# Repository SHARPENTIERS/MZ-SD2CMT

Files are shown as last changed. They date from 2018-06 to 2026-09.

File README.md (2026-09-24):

# MZ-SD2CMT2 - Reborn

**Extended SD-card CMT emulator / recorder for the Sharp MZ-800**  
**Firmware 1.0**

<p align="center">
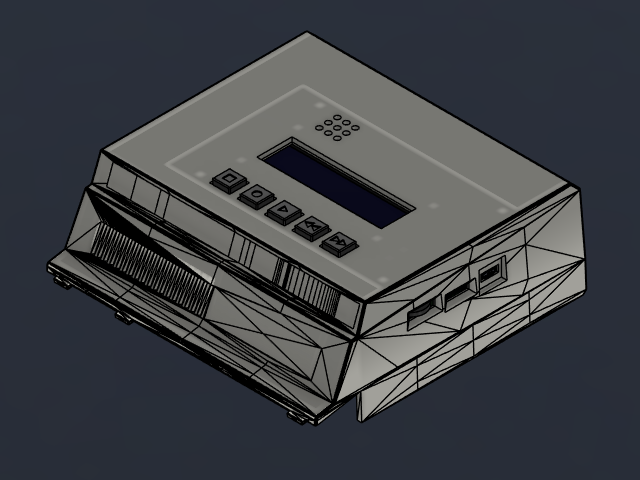
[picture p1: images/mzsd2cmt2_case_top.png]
MZ-SD2CMT2 enclosure
  
</p>

> **MZ-SD2CMT2 is based directly on the original [MZ-SD2CMT](https://github.com/SHARPENTIERS/MZ-SD2CMT) project by Christophe Avoinne (hlide).**  
> The purpose of MZ-SD2CMT2 is to **continue and extend the original project**: improve the firmware and user interface, add playback and recording capabilities, and provide an optional integrated hardware implementation, while preserving compatibility with the original modular hardware concept.

The primary target is the **Sharp MZ-800**. The project acts as a solid-state CMT replacement using an SD card, but its design goal is not only functional replacement: the dedicated hardware version is also intended to look and feel at home next to original Sharp MZ equipment.

## Project goals

MZ-SD2CMT2 has three main goals: **preserve compatibility with the original MZ-SD2CMT modular hardware**, extend the firmware with additional playback/recording features, and provide an optional dedicated PCB and enclosure for a cleaner stand-alone build.

The dedicated version remains based on the same core CMT interface, but adds convenience hardware and a mechanical design inspired by original Sharp MZ cassette equipment.

## Main features

- SD-card file browser with alphabetical sorting, folders and long-name scrolling
- playback of **MZF, MZT, M12, WAV, LEP, L16 and TAP**
- recording to **MZF, WAV, LEP and L16**
- WAV recording at **44.1 kHz or 22.05 kHz, 8-bit mono**
- recording control by **MOTOR**, automatic activity detection, or manual control
- optional **AutoName**: automatic naming of recordings from detected Sharp MZ tape metadata
- live recognition/display of several normal and turbo tape profiles while recording
- multiple Sharp MZ tape timing and loader profiles, including NORMAL, MZ-700, InterCopy and Turbo Copy families
- **Ultra Fast** loading for compatible MZF files
- selectable ZX Spectrum **TAP playback speed**
- **MFI metadata for MZF** and **MTI per-record metadata for MZT**
- **MZT mini-browser / record selector** showing logical record number, title, loader/profile and per-record duration
- independent loader/profile selection for every logical record inside an MZT
- browser `I` indicator when matching MFI/MTI playback information is available
- MFI/MTI files hidden from normal browser entry counts and sorting
- preparation and conversion of **MZF, MZT, LEP, L16 and WAV** files, including matching **MFI/MTI** metadata is possible with [Extended QDTool](https://github.com/bales0/QDTool)
- automatic sound-monitor activity during physical tape waveform playback/recording
- persistent hardware, playback and recording settings stored in EEPROM
- SD-card insertion/removal handling on supported dedicated hardware
- selectable internal MZ-SD2CMT2 / external physical CMT path on supported dedicated hardware

This README is intentionally a **project overview rather than a complete operating manual**.

For normal use see:

- [User Handbook](guide/USER_HANDBOOK.md)
- [Quick Reference Guide](guide/QUICK_REFERENCE_GUIDE.md)

For metadata syntax see:

- [MFI / MTI playback metadata](guide/MFI_MTI_FORMAT.md)

## Playback overview

### Normal files

Browse to a file and press **PLAY**.

Supported playback formats are:

| Format | Purpose |
|---|---|
| **MZF** | canonical single Sharp MZ program image |
| **MZT** | container with multiple logical MZF records |
| **M12** | supported Sharp tape-format variant |
| **WAV** | sampled tape waveform |
| **LEP** | pulse-duration representation using a 50 µs unit |
| **L16** | pulse-duration representation using a 16 µs unit |
| **TAP** | ZX Spectrum TAP playback |

The normal recommended starting point for Sharp MZ software is:

```text
PLAY CTRL = MOTOR
LOADER    = NORMAL
SPEED     = 1:1
```

When a library contains matching MFI/MTI files, use:

```text
PLAY CTRL = MOTOR
LOADER    = AUTO
```

### MZT mini-browser / record selector

An MZT is not started immediately as one long stream. Opening an MZT first enters a lightweight **record selector**.

Example:

```text
+----------------+
|2I5 PACMAN     █|
|MTI N13 01:27   |
+----------------+
```

The selector shows:

- selected logical record and total record count
- title from the selected MZF header
- the resolved loader/profile for that record
- the nominal duration of that record when known

Controls:

```text
REWIND = previous record
FFWD   = next record
PLAY   = confirm/start selected record
STOP   = return to main browser
```

The selector wraps from the first record to the last and vice versa.

During playback, **STOP** returns first to the MZT selector. A second **STOP** returns to the main SD browser.

Each logical MZT record is treated independently. Its title, loader/profile and duration are recalculated for that record rather than applying one global setting to the whole MZT.

Ultra Fast records are also treated as independent LOAD operations. After an Ultra Fast record completes, the next MZT record is not injected automatically: MOTOR mode waits for a new MOTOR cycle and MANUAL mode waits for a new PLAY confirmation.

## MFI and MTI playback metadata

External playback metadata use two explicit sidecar formats:

```text
GAME.MZF  -> GAME.MFI
TAPE.MZT  -> TAPE.MTI
```

There is **no external `.MZI` fallback**. The internal source module still uses the historical `mzi_sidecar.*` name, but files on the SD card are MFI/MTI.

### MFI - one MZF

Example:

```ini
TYPE=NORMAL
SPEED=1:3
```

MFI is used when:

```text
LOADER = AUTO
```

If a loader is selected manually, the manual selection has priority.

### MTI - per-record information for MZT

Each logical record can have its own playback profile:

```ini
RECORD=1
TYPE=NORMAL
SPEED=1:1

RECORD=2
TYPE=IC
SPEED=1:3

RECORD=3
TYPE=TC
SPEED=1:3

RECORD=4
TYPE=UL_MZ800
```

This is particularly useful for multi-part games where the bootstrap, main program and later level/data records do not use the same loader.

Current supported metadata families include:

| TYPE | SPEED |
|---|---|
| `NORMAL` | `1:1`, `1:2`, `1:3`, `1:4` |
| `MZ700` | `1:1`, `1:3` |
| `IC` | `1:1`, `1:2`, `1:3`, `1:4` |
| `TC` | `1:1`, `1:2`, `1:3` |
| `UL` | no SPEED |
| `UL_MZ800` | no SPEED |
| `UL_MZ700` | no SPEED |

`TC 1:4` is intentionally not defined in the current firmware.

If an MTI file or a particular `RECORD=n` section is missing/invalid, that record falls back independently to `NORMAL 1:1`. Other MZT records are resolved again from their own metadata.

### Browser information indicator

MFI and MTI files themselves are hidden from the normal browser and do not count as visible entries.

A normal browser counter:

```text
3/28
```

changes to:

```text
3I28
```

when matching playback information exists for the highlighted MZF/MZT.

For MZT, the same `I` convention is also used in the logical record counter when MTI information is available.

## Preparing files with Extended QDTool

The companion [**Extended QDTool**](https://github.com/bales0/QDTool) can be used on a PC to prepare files for MZ-SD2CMT2.

In its Advanced mode it can:

- create and edit **MZF** and multi-record **MZT** images
- export tape waveforms as **LEP**, **L16** or **44.1 kHz WAV**
- assign a **Loader** and **Speed** profile to individual records before waveform export
- generate matching **MFI** sidecars when saving MZF files
- generate matching **MTI** sidecars with per-record profiles when saving MZT files
- combine several records into one waveform output or export them separately
- import supported WAV/LEP/L16 tape captures and map recognized NORMAL, MZ700, IC and TC timing profiles back to record metadata

This makes Extended QDTool the recommended desktop utility for preparing an SD-card library when files need to be converted, grouped into MZT containers, assigned a specific playback profile, or supplied together with MFI/MTI information for `LOADER=AUTO`.

Typical workflow:

```text
MZF files
   |
   +--> assign Loader / Speed in Extended QDTool
   |
   +--> save as MZF + MFI
   |
   +--> combine as MZT + MTI
   |
   +--> or export as LEP / L16 / WAV
```

The waveform exporters use the selected record profiles. Static waveform export supports the NORMAL, MZ700, IC and TC families implemented by QDTool; Ultra Fast profiles require the live CMT handshake and therefore are not exported as a static LEP/L16/WAV waveform.

## Recording overview

Recording formats:

| Format | Record |
|---|---:|
| **MZF** | yes |
| **WAV 44.1 kHz** | yes |
| **WAV 22.05 kHz** | yes |
| **L16** | yes |
| **LEP** | yes |

Recording modes:

- **MOTOR** - follows the Sharp MOTOR signal
- **AUTO** - starts on detected signal activity and finishes after inactivity
- **MANUAL** - controlled by the user

All normal captures are written to:

```text
/RECORDINGS
```

A short **STOP** finishes and saves an active recording. A long **STOP** cancels it and deletes an already-created capture file.

AutoName can decode a valid incoming header, display the detected title/profile during capture and rename the provisional `RECxxxx` file after a successful save.

## Loader/profile families

The user-facing loader families include:

- **NORMAL** - normal Sharp MZ timing family, 1:1 through 1:4
- **MZ700** - MZ-700 1:1 and FAST3 / 1:3
- **IC** - InterCopy-family profiles, 1:1 through 1:4
- **TC** - Turbo Copy profiles, 1:1 through 1:3
- **UL** - Ultra Fast with automatic target/placement handling
- **UL MZ800** - MZ-800-specific Ultra Fast
- **UL MZ700** - MZ-700-specific Ultra Fast
- **AUTO** - resolve MFI/MTI when present, otherwise use safe fallback behaviour

Compact LCD labels include `N11`..`N14`, `M71`, `M73`, `IC1`..`IC4`, `TC1`..`TC3`, `UL`, `UL8` and `UL7`.

## Hardware variants

### 1. Original-compatible modular build

The original MZ-SD2CMT concept is deliberately retained as a fully supported hardware option. MZ-SD2CMT2 can therefore be built from readily available modules without the dedicated PCB. This is useful for reproducing the original project, experimenting with the firmware, or building a compact version from standard parts.

The modular implementation uses the same basic building blocks as MZ-SD2CMT: an ATmega2560 board, a 16×2 LCD/keypad interface, an SPI SD-card module and the four Sharp MZ CMT signals. Two ATmega2560 board styles are practical:

- a standard **Arduino Mega 2560 R3**, which can accept the LCD Keypad Shield directly,
- a compact **Mega 2560 Pro Mini / Mini Mega**, which provides the same ATmega2560 resources in a much smaller module and is convenient for a self-contained enclosure.

#### Arduino Mega 2560 R3

<p align="center">
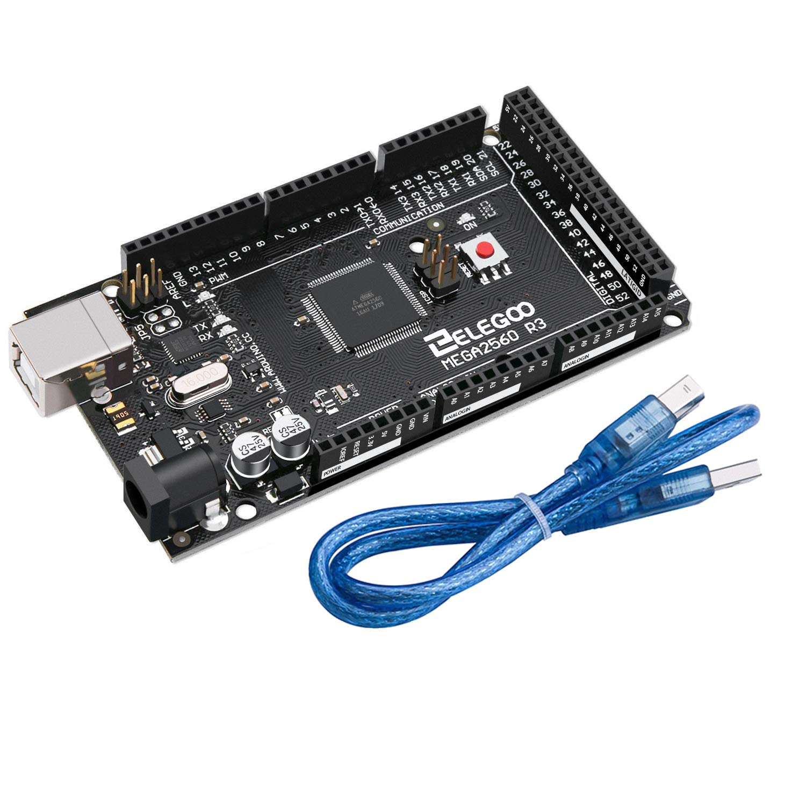
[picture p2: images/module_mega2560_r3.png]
Arduino Mega 2560 R3 used by the original-compatible modular build
  
</p>

The full-size Mega 2560 follows the most straightforward construction style: the LCD Keypad Shield can be fitted directly on the Arduino headers and the SD-card module and CMT signals are connected with wiring. This is the closest arrangement to the original MZ-SD2CMT module-based implementation.

**What to look for when buying:** a full-size **Mega 2560 R3-compatible 5 V / 16 MHz board** with the ATmega2560 and the standard Mega shield header layout. The photograph above is a real board and is intended as a visual identification aid.

#### Mini Mega / Mega 2560 Pro Mini

<p align="center">
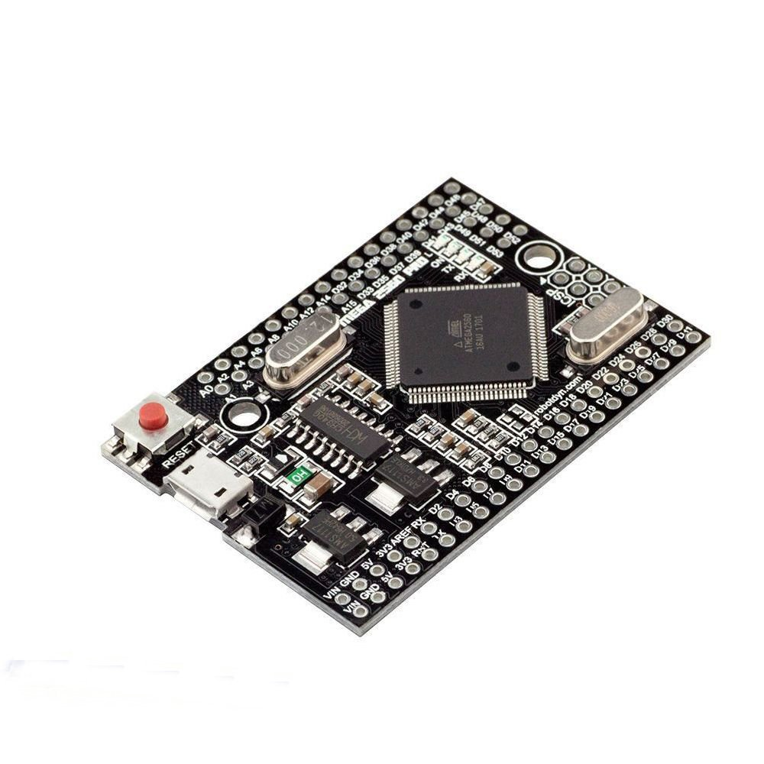
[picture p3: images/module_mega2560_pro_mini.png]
Mini Mega 2560 module
  
</p>

The compact Mini Mega version keeps the ATmega2560 platform while reducing the physical size substantially. It is especially suitable when the modular electronics are to be placed in a small stand-alone case rather than left as separate development boards.

**What to look for when buying:** this board is commonly listed as **Mega 2560 Pro Mini**, **Mini Mega 2560**, **Mega Pro Embed** or similar. Choose the **ATmega2560, 5 V, 16 MHz** version. The photograph above shows the compact board style used as the reference for this project.

For this version the repository already contains printable enclosure parts in the `STL/KeypadShield` directory:

- [`STL/KeypadShield/Cover.stl`](STL/KeypadShield/Cover.stl) - enclosure/cover
- [`STL/KeypadShield/Button.stl`](STL/KeypadShield/Button.stl) - printable button part

These STL files allow the Mini Mega + keypad-shield implementation to be built as a compact finished unit while still using the original modular electrical concept.

#### 16x2 LCD Keypad Shield

<p align="center">
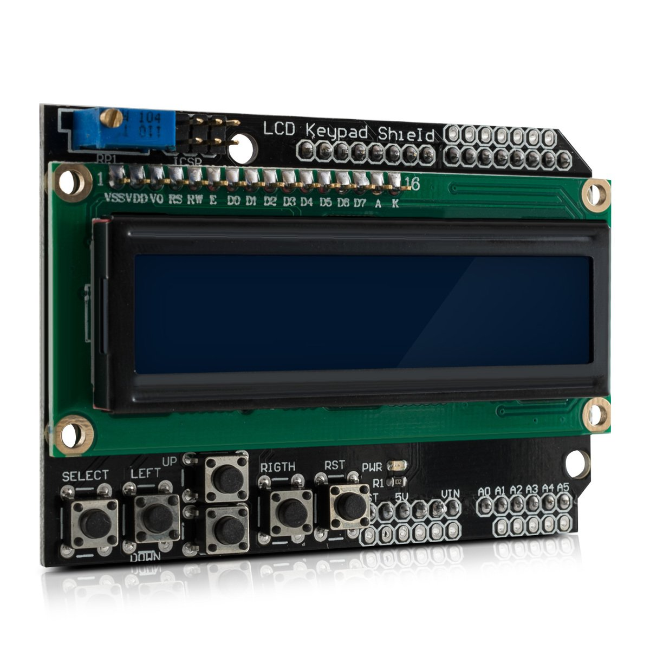
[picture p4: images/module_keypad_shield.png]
16x2 LCD Keypad Shield
  
</p>

The firmware retains support for the familiar 16x2 LCD with five analogue-keypad buttons. The keypad shield provides the display and the basic navigation/transport controls without requiring a custom front-panel PCB.

**What to look for when buying:** the common **1602 / HD44780-compatible LCD Keypad Shield** with five navigation buttons read through the analogue resistor ladder on **A0**. The real photograph above matches the classic shield style used by the original MZ-SD2CMT project.

#### SD-card module

<p align="center">
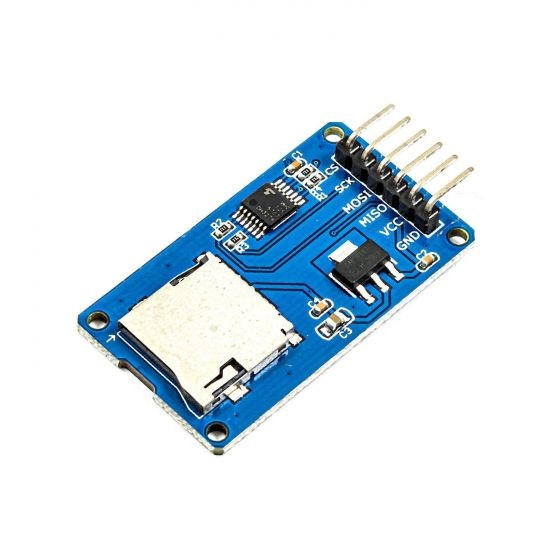
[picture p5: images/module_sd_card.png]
SPI SD-card module with 5 V level shifting
  
</p>

The modular build uses a standard SPI SD-card adapter with 5 V-compatible level shifting. On the Mega 2560 the hardware SPI interface is connected through pins **50-53** (`MISO`, `MOSI`, `SCK`, `SS/CS`).

**What to look for when buying:** use an **SD-card SPI module intended for 5 V Arduino boards**, with an onboard **3.3 V regulator and logic-level conversion**. The original-style full-size module usually exposes `GND`, `3.3V`, `5V`, `CS/SDCS`, `MOSI`, `SCK`, `MISO` and `GND`. The real photograph above is included as a visual guide; modules with the same electrical function may have a different PCB colour or layout.

Connection details for the Sharp MZ CMT interface are collected in the dedicated **CMT interface and compatibility** section below, so the wiring reference is shown only once in this README.

### 2. Dedicated MZ-SD2CMT2 hardware

The dedicated hardware combines the electronics into a purpose-built unit and adds:

- **SD-card presence detection**, allowing the firmware to detect card insertion/removal instead of relying only on failed file access
- a selectable **internal MZ-SD2CMT2 / external CMT path**, allowing a real external cassette recorder or another CMT source to remain connected and be selected without rewiring
- **audio monitoring** of the tape signal during playback and recording
- integrated connectors and wiring intended for a permanent installation
- a dedicated mechanical arrangement for the LCD, five control buttons, SD-card access and CMT connections

#### USB programming from PlatformIO

The dedicated PCB is designed so that the Mega/ATmega2560 firmware can be programmed and updated through the **USB connection directly from PlatformIO**. For normal firmware updates this avoids the need to connect a separate ISP programmer.

> **Important:** direct USB upload requires an **Arduino Mega 2560-compatible bootloader** to be present in the ATmega2560. If a blank/replacement ATmega2560 is fitted, or the Mega module does not contain the bootloader, the Arduino Mega 2560 bootloader must first be programmed via **ISP**. Once the bootloader is installed, subsequent firmware uploads can be performed normally through USB using PlatformIO/AVRDUDE.

#### Mechanical design

A major goal of the dedicated version is for the finished device to **visually resemble an original Sharp MZ CMT/cassette unit as closely as is practical**, rather than looking like a generic Arduino box.

The enclosure is therefore designed around the visual language of period Sharp hardware: a low, slightly wedge-shaped body, an inclined upper control panel, a recessed display area, a row of transport-style controls and horizontal grille/vent details. The intention is **not to make an exact 1:1 reproduction of a specific Sharp cassette mechanism**, but to create a modern SD-based CMT replacement that looks appropriate beside an MZ-800 and preserves the character of the original equipment.

The dedicated PCB is designed together with the enclosure, so the positions of the display, buttons, SD-card access and connectors are part of the mechanical concept rather than an afterthought.

For the dedicated PCB version, the repository contains the matching **3D-printable mechanical parts** in the [`STL/PCB`](STL/PCB) directory:

- [`STL/PCB/Cover.stl`](STL/PCB/Cover.stl) - enclosure cover
- [`STL/PCB/Distancer.stl`](STL/PCB/Distancer.stl) - mechanical spacer
- [`STL/PCB/FFD_REW.stl`](STL/PCB/FFD_REW.stl) - fast-forward / rewind control
- [`STL/PCB/Play.stl`](STL/PCB/Play.stl) - PLAY control
- [`STL/PCB/Rec.stl`](STL/PCB/Rec.stl) - REC control
- [`STL/PCB/Stop.stl`](STL/PCB/Stop.stl) - STOP control

These STL files form the mechanical counterpart to the dedicated PCB and allow the enclosure and transport-style controls shown below to be reproduced without having to design a separate case. There is a space between knobs and tact switches for double adhesive foam to dampen too much click feel.

<table>
<tr>
<td align="center"><b>PCB - component side</b></td>
<td align="center"><b>PCB - opposite side</b></td>
</tr>
<tr>
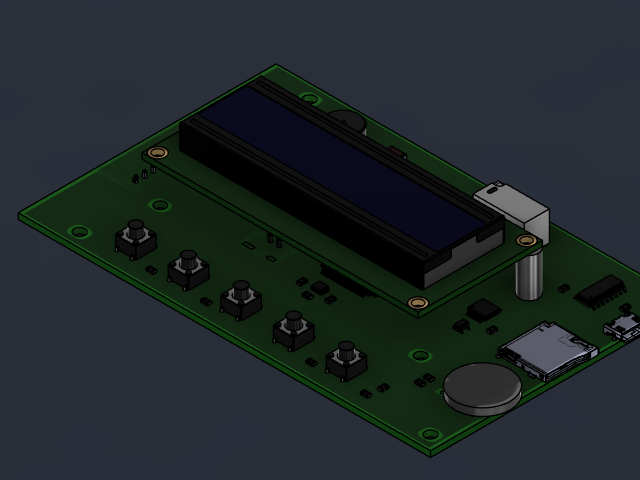
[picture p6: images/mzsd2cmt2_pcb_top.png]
MZ-SD2CMT2 PCB top
<td></td>
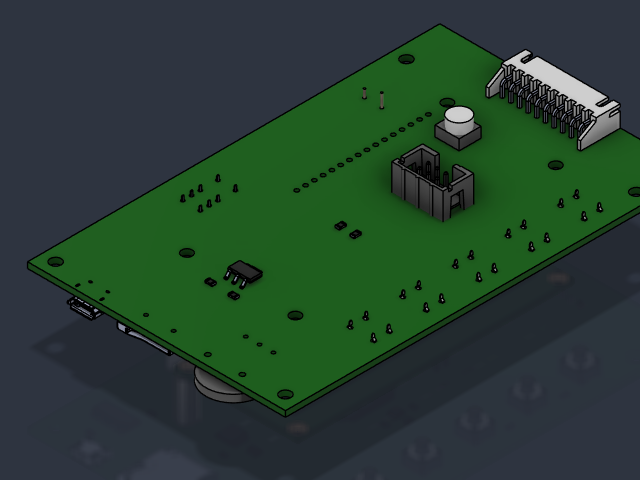
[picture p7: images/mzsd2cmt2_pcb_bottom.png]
MZ-SD2CMT2 PCB bottom
<td></td>
</tr>
</table>

<p align="center">
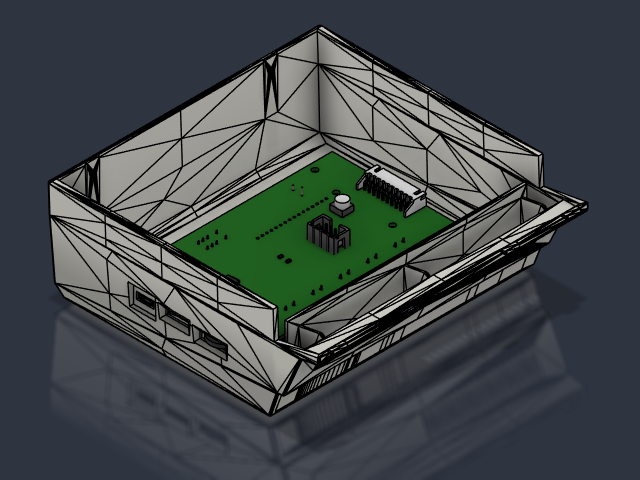
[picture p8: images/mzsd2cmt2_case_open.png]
MZ-SD2CMT2 internal arrangement
  
</p>

<p align="center"><em>Internal arrangement of the dedicated PCB below the upper control panel.</em></p>

## CMT interface and compatibility with MZ-SD2CMT

MZ-SD2CMT2 retains the CMT signal arrangement of the original MZ-SD2CMT project. This is the key hardware compatibility point that allows both the original-style modular build and the dedicated PCB to use the same firmware architecture.

<p align="center">
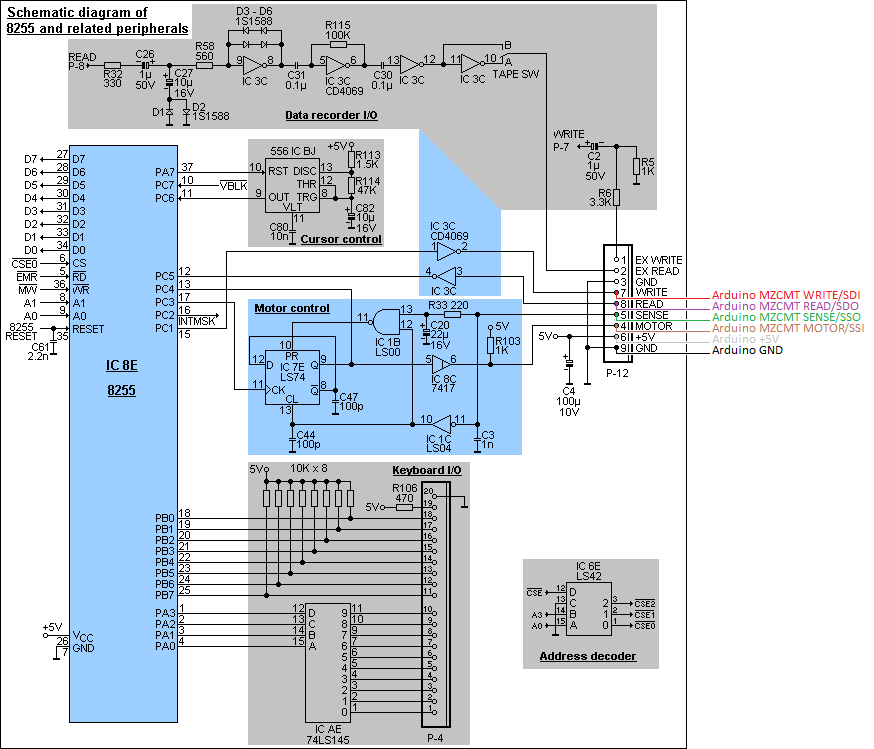
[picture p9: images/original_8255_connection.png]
MZ-SD2CMT compatible Sharp MZ 8255 CMT wiring reference
  
</p>

<p align="center"><em>Original MZ-SD2CMT 8255/CMT connection diagram and pin assignment.</em></p>

| Signal | Arduino Mega pin | Function |
|---|---:|---|
| `WRITE / SDI` | 15 | data from the Sharp MZ to the CMT interface |
| `MOTOR / SSI` | 16 | motor/control input from the Sharp MZ |
| `READ / SDO` | 2 | data from the CMT interface to the Sharp MZ |
| `SENSE / SSO` | 18 | tape sense/control output to the Sharp MZ |

These four signals are also used by the original MZ-SD2CMT Ultra-Fast transfer method. The dedicated MZ-SD2CMT2 PCB adds card detection, external-CMT switching and audio-monitor circuitry around this core interface without changing the basic connection concept.

> **Dedicated PCB schematic:** the electrical schematic of the MZ-SD2CMT2 board is kept with the project hardware files. The PCB/enclosure images in this README are mechanical/3D design renders, not the electrical schematic.

## Software structure

The current firmware targets the **ATmega2560**. Time-critical tape generation and capture use AVR timers and interrupts, while SD access, file parsing, UI and metadata processing run in the foreground.

The source tree is divided into functional areas including:

- `src/play` - playback engines, loaders and timing profiles
- `src/record` - WAV/LEP/L16/MZF recording and automatic naming
- `src/formats` - file-format detection, tape profiles and MFI/MTI sidecar handling
- `src/drivers` - LCD, keypad, SD card, CMT I/O, external-CMT switching and sound monitor
- `src/ui` - browser, MZT record selector, menus and transport screens

The internal sidecar implementation is still named `mzi_sidecar.*` for source compatibility, but the supported external metadata files are `.MFI` and `.MTI`.

## Documentation

- [User Handbook](guide/USER_HANDBOOK.md) - full operating instructions
- [Quick Reference Guide](guide/QUICK_REFERENCE_GUIDE.md) - basic controls and everyday operation
- [MFI / MTI playback metadata](guide/MFI_MTI_FORMAT.md) - sidecar syntax and selection rules
- [CMT timing reference](guide/CMT_TIMING_REFERENCE.md) - technical timing/calibration reference
- [InterCopy / Turbo Copy timing reference](guide/CMT_INTERCOPY_TURBOCOPY_TIMING_REFERENCE.md) - copier-specific timing analysis

## Origins, references and acknowledgements

MZ-SD2CMT2 builds on earlier work from the Sharp MZ and retro-computing community. The following projects, formats and authors were used either as a direct starting point or as technical references during development:

| Project / format | Author(s) | Contribution / relevance |
|---|---|---|
| **[MZ-SD2CMT](https://github.com/SHARPENTIERS/MZ-SD2CMT)** | **Christophe Avoinne (hlide)** / SHARPENTIERS | **Direct predecessor and primary foundation of MZ-SD2CMT2.** Hardware concept, Sharp MZ CMT interface, file playback and Ultra-Fast transfer work. |
| **MZF2LEP** ([included in MZ-SD2CMT](https://github.com/SHARPENTIERS/MZ-SD2CMT/tree/master/Tools/mzf2lep)) | **Christophe Avoinne (hlide)** | MZF-to-LEP/WAV conversion and Sharp MZ tape waveform/timing work. MZF2LEP itself was based on MZF2WAV. |
| **MZF2WAV** | **Jeroen F. J. Laros** | Earlier MZF-to-audio conversion code on which MZF2LEP was based. |
| **[SDLEP-READER / LEP format](https://dcmoto.pages-perso.free.fr/bricolage/sdlep-reader/index.html)** | **Daniel Coulom** | LEP pulse-duration format and SD-based virtual cassette reader concept. |
| **[ZX Spectrum TAP format](https://sinclair.wiki.zxnet.co.uk/wiki/TAP_format)** | ZX Spectrum community / historical TAP documentation | TAP block structure and ZX Spectrum tape encoding/timing reference used for TAP playback support. |
| **[mz800emu](https://github.com/michalhucik/mz800emu)** | **Michal Hucik (ordoz)** | Reference material for Sharp MZ hardware, CMT behaviour and file formats. |
| **[TapeMZ](https://github.com/michalhucik/TapeMZ)** | **Michal Hucik (ordoz)** | Research and implementation covering Sharp MZ tape formats, loaders, timing profiles, WAV analysis and the TMZ archival format. |

Special thanks to the original authors, maintainers and contributors. MZ-SD2CMT2 is intended to extend this body of work while preserving clear attribution to the projects from which code, ideas, file formats or technical information originated.

## Development status

Firmware 1.0 documents the current user-facing playback, MZT selection, MFI/MTI metadata and recording workflow described above. Timing profiles and hardware options continue to be tested on real Sharp MZ hardware.

## License

See [`LICENSE`](LICENSE).

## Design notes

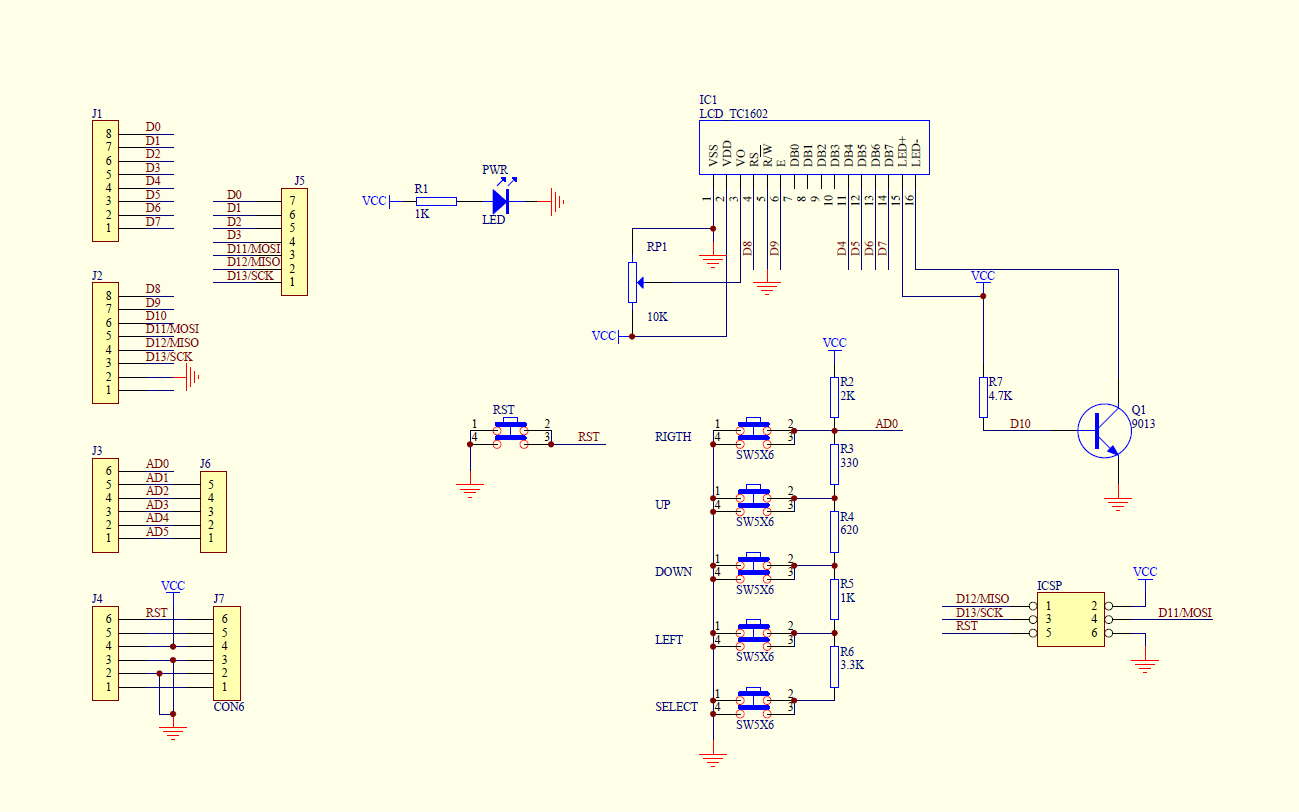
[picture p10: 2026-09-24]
images/lcdkeypadshieldschematic.png

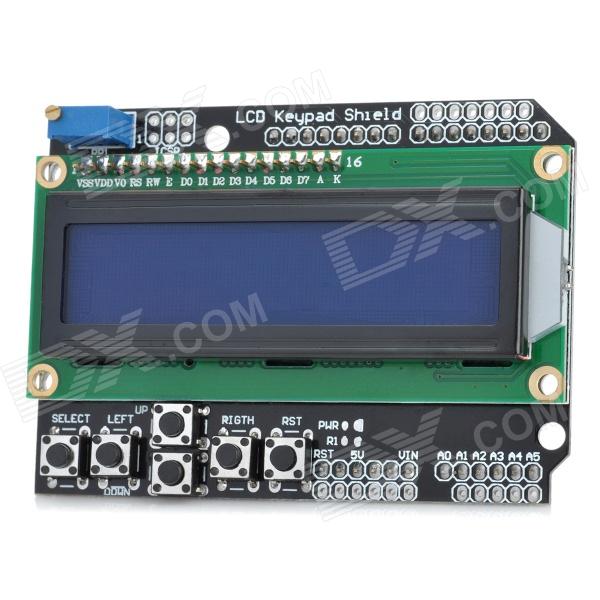
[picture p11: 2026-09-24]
images/lcdkeypadshield.jpeg

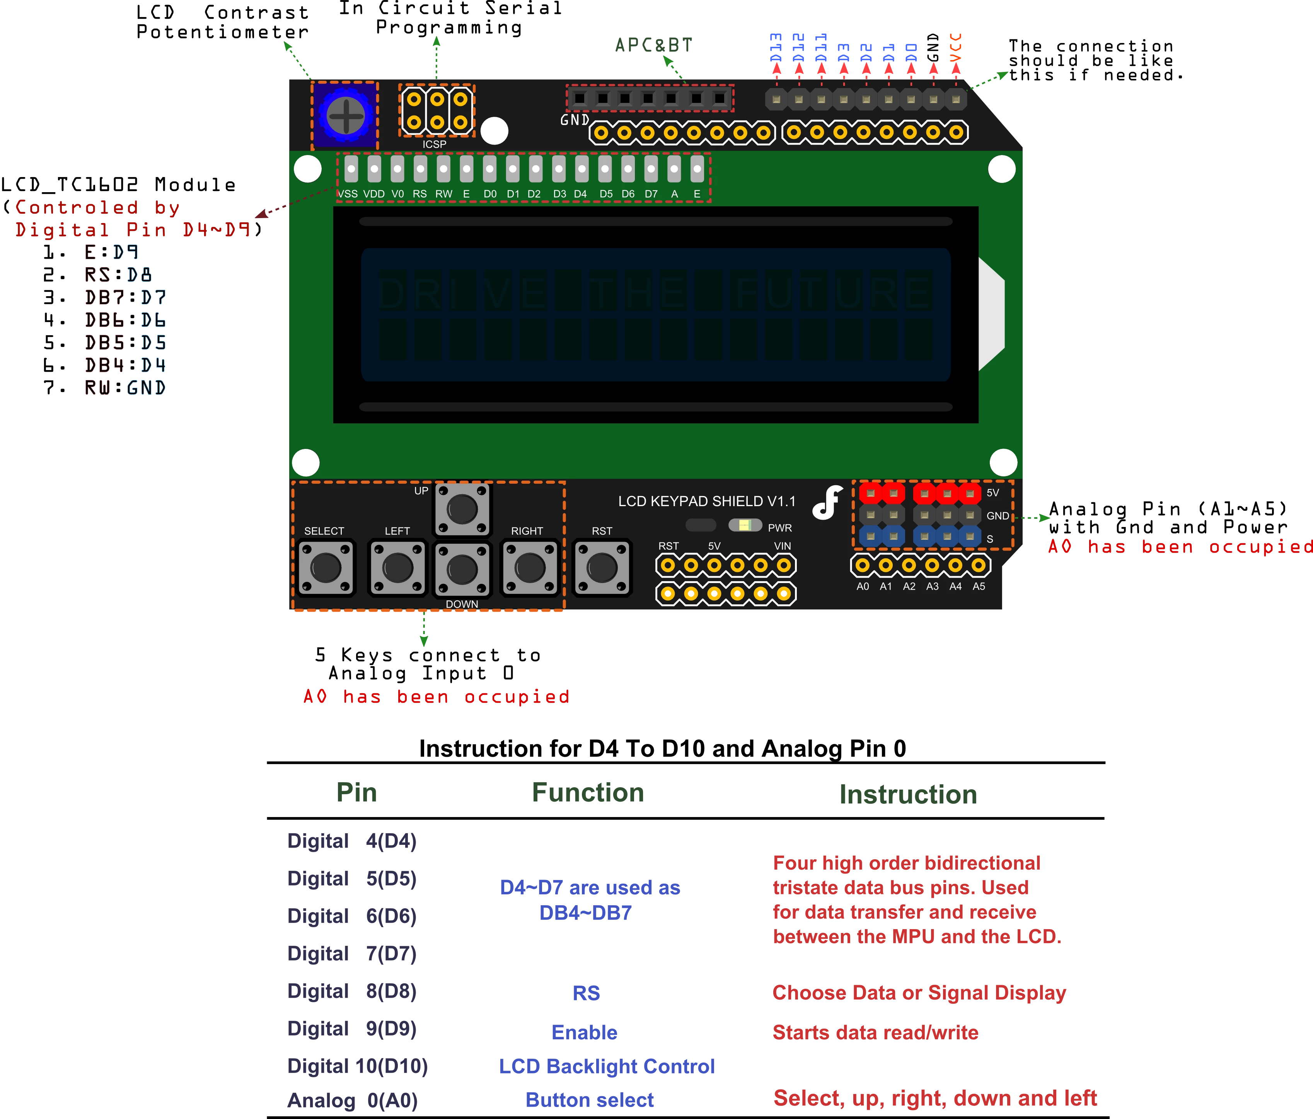
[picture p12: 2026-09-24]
images/lcdkeypadshield.webp

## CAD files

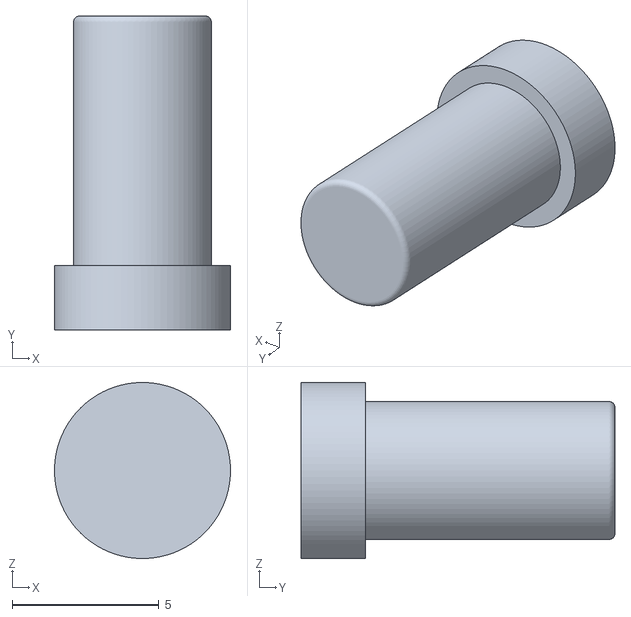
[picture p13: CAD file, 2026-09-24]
STL/KeypadShield/Button.stl
6.00 x 10.7 x 6.00

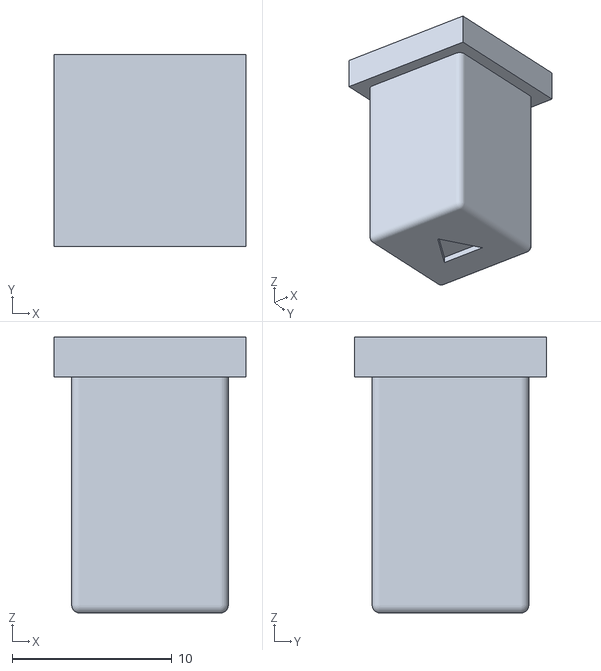
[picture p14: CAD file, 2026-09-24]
STL/PCB/Play.stl
12.0 x 12.0 x 17.3

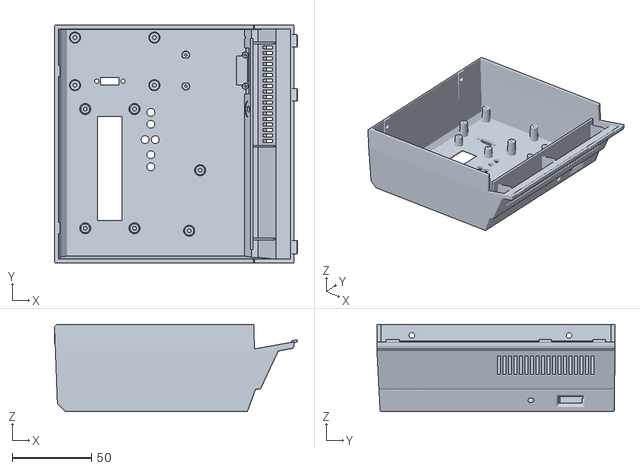
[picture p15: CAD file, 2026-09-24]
STL/KeypadShield/Cover.stl
153.1 x 150.0 x 55.0

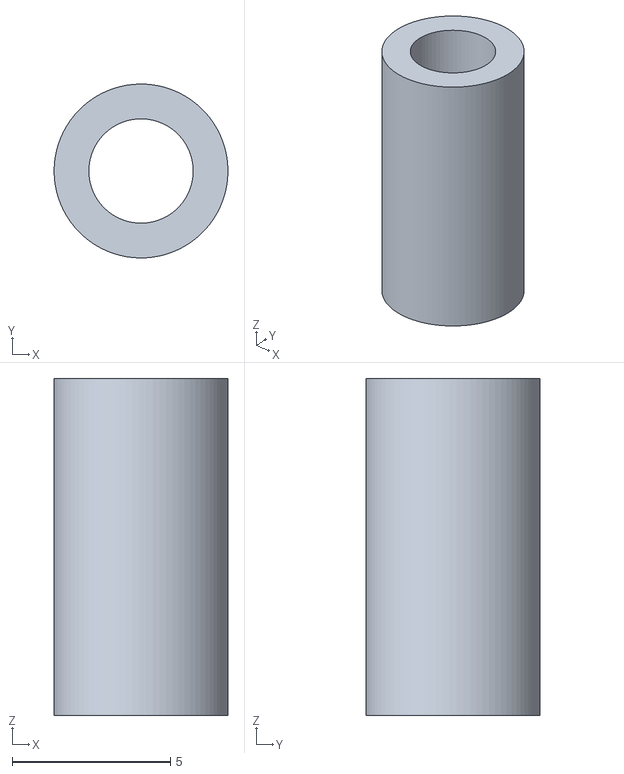
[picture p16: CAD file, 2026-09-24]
STL/PCB/Distancer.stl
5.50 x 5.50 x 10.7

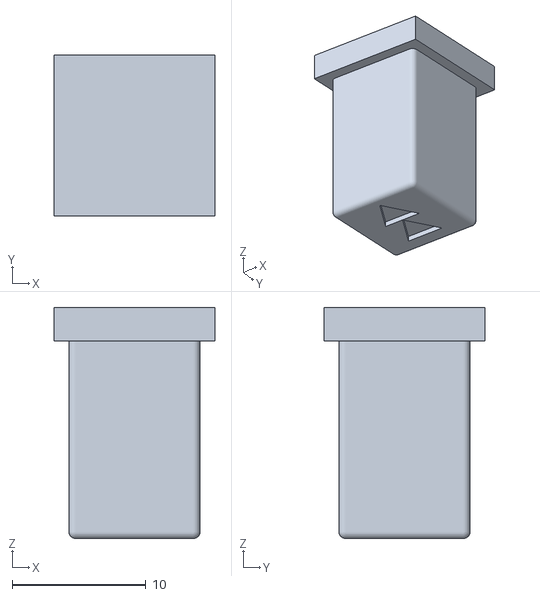
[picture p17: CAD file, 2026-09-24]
STL/PCB/FFD_REW.stl
12.0 x 12.0 x 17.3

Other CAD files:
STL/PCB/Cover.stl
STL/PCB/Stop.stl
STL/PCB/Rec.stl

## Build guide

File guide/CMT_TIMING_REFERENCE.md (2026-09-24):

# SD2CMT2 CMT Timing Reference
## ROM/loader-derived calibration reference

**Document purpose:** stable calibration source for future changes to CMT/PWM timing in `bales0/MZ-SD2CMT2`.

**Reference revision:** 2 (2026-08-29). This revision closes the native MZ-800 low-monitor analysis and separates MZ-800 IC, MZ-800 TC and MZ-700 FAST3 turbo-loader timing.

**Scope:** Sharp MZ CMT modes implemented in SD2CMT2 at baseline commit
`fabf8fc0d032a0363b991be2c1e388fc5657d2c5` (`TAP playback percentage adjustment`).

**Explicitly out of scope:** TAP/Sinclair. TAP must receive its own ROM/loader audit.

**Important:** this document intentionally distinguishes three different things that must never be conflated:

1. a waveform physically **generated** by a monitor ROM,
2. a receiver **decision/read point** implemented by a loader,
3. an empirically selected SD2CMT2 waveform that is merely required to fall safely on opposite sides of that read point.

The old 44.1 kHz WAV references remain useful as regression material, but they are **not the primary timing authority**.

---

## 1. Frozen inputs

### 1.1 Supplied ROM images

| File | Meaning | Size [B] | SHA-256 |
|---|---|---:|---|
| `1z-013a(2).rom` | MZ-700 PAL monitor 1Z-013A | 4096 | `ae1d65717414d4693158cbbd9ab707aa43e4e1ac0b2ae0e13ee3f68c66cba81b` |
| `mz700_1z-009a_jp(1).rom` | MZ-700 Japanese monitor 1Z-009A | 4096 | `b0d16889ac3e2a80cc3bc9445bc95bc9988df7b6115124f284850667cf45ff9f` |
| `9Z_504M(4).ROM` | MZ-800 high monitor 9Z-504M | 8192 | `68a91b82517d5642e250cdddb519de780fb20bcde39b2de8baee387ca6bf446a` |
| `Mz700a(1).rom` | MZ-800 low monitor 1Z-013B (binary identifies itself as `** MONITOR 1Z-013B **`) | 4096 | `fa65299ff588e3402973afbb1285dc5a7993efe9265213b64ba8e3a6facd2acf` |

### 1.2 SD2CMT2 source baseline

Repository:

`https://github.com/bales0/MZ-SD2CMT2`

Frozen commit:

`fabf8fc0d032a0363b991be2c1e388fc5657d2c5`

The repository head was re-checked on 2026-08-29; this commit is still the latest commit on `master`.

Important files at that commit:

- `src/formats/mz_tape_profiles.cpp`
- `src/formats/mz_tape_profiles.h`
- `src/formats/mz_loader_profiles.cpp`
- `src/play/mzf_loader.cpp`
- `src/play/mzf_playback.cpp`
- `src/play/mz700_fast3.cpp`
- `src/play/loader_mode.h`
- `TEST/MZ700/verify_mz700_fast3.ps1`

Relevant source blob IDs at the frozen commit:

```text
mz_tape_profiles.cpp   482414a8bba21e5787c325f02eed231eabcdf247
mzf_playback.cpp       f8429deb2fb9007a27626355242ef7b1f610dcfd
mzf_loader.cpp         1f45f2a7e3c20e91b6313e7d5c99d86f3880b7cc
mz_loader_profiles.cpp 3df3f1a41d67c582db30ff4cdaafdbcd502da029
mz700_fast3.cpp        ef24f178d995c13a6c16259536a75051b6a2fdcc
```

Embedded loader byte arrays additionally fingerprint to:

```text
IC loader, 96 B: SHA-256 a52224f33e5ad8ca6d436257f58ef5802c4a4a8a7c8e0798e31a0a968a6eeab2
TC loader, 90 B: SHA-256 4ab47c752ae0d04ce341d9be221336ed51b30a9c698d09aed4370172917ee790
```

If any of these inputs changes, this document is no longer automatically authoritative for the changed code.

---

## 2. Evidence and confidence rules

Use the following precedence when calibrating or reviewing a timing change.

| Level | Label | Meaning |
|---|---|---|
| 1 | `ROM-PATH-HIGH` | Supplied ROM bytes + deterministic Z80 path + documented hardware wait model |
| 1 | `LOADER-PATH-HIGH` | Exact loader bytes + exact patch value + deterministic RAM-executed Z80 path |
| 2 | `OFFICIAL-HW` | Sharp service/technical manual timing or source listing |
| 3 | `HW-TESTED` | Proven on a physical MZ machine, but exact timing origin may be empirical |
| 4 | `EMPIRICAL-WAV` | Derived from sampled WAV/PCM; quantized and not a source of exact CPU timing |
| special | `HANDSHAKE` | Mode is not pulse-width PWM; SHORT/LONG timing is not applicable |
| open | `TRACE-PENDING` | Static analysis exists, but cycle-accurate runtime trace is still desirable |

A WAV can confirm polarity, framing and compatibility. It must not silently overwrite a ROM/loader-derived timing equation.

---

## 3. Clock and timer model

### 3.1 Z80 clocks used here

```text
MZ-700 PAL / MZ-800 PAL: 3,546,875 Hz
MZ-700 Japanese/NTSC:    3,579,545 Hz
ATmega2560 SD2CMT2:     16,000,000 Hz
```

For ATmega2560 Timer3 with prescaler 1:

```text
1 timer tick = 62.5 ns
ticks = round(seconds * 16,000,000)
```

### 3.2 Monitor-ROM wait-state model

The published 1Z-013A source listing annotates timings such as:

```text
PUSH AF       12 T
LD A,n         9 T
LD (nn),A     16 T
CALL nn       20 T
DEC A          5 T
JP NZ,nn      13 T
RET            11 T
```

These are consistent with the standard Z80 timing plus one wait state for
each instruction byte fetched from monitor ROM. Example:

```text
LD A,n:      7 + 2 ROM-byte waits = 9 T
CALL nn:    17 + 3 ROM-byte waits = 20 T
JP NZ,nn:   10 + 3 ROM-byte waits = 13 T
```

This matters enormously. A PC emulator that executes the same instructions
with plain Z80 timings can produce a waveform roughly 20–30 % too fast even
though the instruction sequence itself is correct.

The supplied `MZ700_monitor_speed.wav` observed earlier is therefore treated
only as an emulator-output reference. Its 8/9 and 16/17 sample pulse halves
are consistent with missing/reduced real monitor-ROM wait time and 44.1 kHz
quantization; they are **not** the calibration authority used below.

For loaders that first copy the monitor to RAM and execute the patched CMT
receiver from RAM, this ROM-fetch penalty is removed. For those paths this
audit uses normal Z80 instruction timings. A future cycle-accurate runtime
trace should still verify that no machine-specific RAM wait is inserted.

---

## 4. Critical concept: a ROM pulse does not always have one fixed LOW width

`SHORT` and `LONG` explicitly create the rising and falling CMT writes, but
after the falling edge the routine returns to its caller. The time until the
next rising edge therefore includes caller instructions.

Consequently:

```text
HIGH width = largely intrinsic to SHORT/LONG routine
LOW width  = intrinsic delay + caller/framing/next-bit path
```

For example, a SHORT in the leader, a SHORT in a tape mark and a SHORT before
a LONG data bit do not have exactly the same LOW duration.

Therefore a firmware structure containing only:

```text
short_high, short_low, long_high, long_low
```

is necessarily a fixed approximation of a software-generated ROM waveform.
This is not a bug in SD2CMT2; it is a modeling decision that must be explicit.

---

## 5. MZ-700 monitor ROM analysis

### 5.1 Common delay routines

Both supplied MZ-700 ROMs contain:

```asm
0759  3E 15       LD A,$15        ; DLY1
075B  3D          DEC A
075C  C2 5B 07    JP NZ,$075B
075F  C9          RET

0760  3E 13       LD A,$13        ; DLY2
0762  3D          DEC A
0763  C2 62 07    JP NZ,$0762
0766  C9          RET
```

Using the monitor-ROM wait model:

```text
CALL DLY1 = 20 + 18*21 + 20 = 418 T
CALL DLY2 = 20 + 18*19 + 20 = 382 T
```

### 5.2 1Z-013A PAL

Supplied ROM SHA-256:

`ae1d65717414d4693158cbbd9ab707aa43e4e1ac0b2ae0e13ee3f68c66cba81b`

Relevant routines:

```text
WBYTE $0767
SHORT $0A01
LONG  $0A1B
DLY4  $09A9, operand $59 = 89
DLY3  $0A4A, operand $3F = 63
EDGE  $0601
RBYTE $0624
```

`SHORT` uses two `DLY1` calls per phase.

Exact rising-to-falling interval:

```text
16 + 2*418 + 9 = 861 T
861 T / 3,546,875 Hz = 242.749 us
```

`LONG` uses `DLY4`, whose call-inclusive time is:

```text
CALL DLY4 = 20 + 18*89 + 20 = 1642 T

LONG HIGH = 16 + 1642 + 9 = 1667 T
          = 469.991 us
```

### 5.3 1Z-009A Japanese/NTSC

Supplied ROM SHA-256:

`b0d16889ac3e2a80cc3bc9445bc95bc9988df7b6115124f284850667cf45ff9f`

Relevant routines:

```text
WBYTE $076D
SHORT $0D47
LONG  $0D60
DLY3  $0A4A, operand $45 = 69
EDGE  $0601
RBYTE $0624
```

`SHORT` is cycle-equivalent to 1Z-013A.

The Japanese `LONG` is important: it is not the same implementation as the
PAL ROM. Its first phase uses:

```text
DLY1 + DLY1 + DLY1 + DLY2
```

and its second phase uses:

```text
DLY1 + DLY1 + DLY1 + DLY1
```

Hence:

```text
LONG HIGH = 16 + 3*418 + 382 + 9
          = 1661 T
          = 464.025 us at 3.579545 MHz
```

This result is extremely close to Sharp's nominal MZ-700 service value of
464 us.

### 5.4 Exact context-dependent MZ-700 pulse table

Each cell below is `T-states / microseconds`.

| ROM | CPU [Hz] | SHORT HIGH | SHORT LOW leader | SHORT LOW mark | SHORT LOW S→L | SHORT LOW S→S | LONG HIGH | LONG LOW mark | LONG LOW L→L | LONG LOW L→S |
|---|---:|---:|---:|---:|---:|---:|---:|---:|---:|---:|
| `MZ700_1Z013A_PAL` | 3,546,875 | 861 / 242.749 | 946 / 266.714 | 934 / 263.330 | 938 / 264.458 | 951 / 268.123 | 1667 / 469.991 | 1740 / 490.573 | 1757 / 495.366 | 1770 / 499.031 |
| `MZ700_1Z009A_JP` | 3,579,545 | 861 / 240.533 | 946 / 264.279 | 934 / 260.927 | 938 / 262.044 | 951 / 265.676 | 1661 / 464.025 | 1770 / 494.476 | 1787 / 499.225 | 1800 / 502.857 |

Notes:

- `leader`: repeated SHORT in the BC leader loop.
- `mark`: repeated pulse in the D/E tape-mark loop.
- `S→L`, `S→S`, `L→L`, `L→S`: steady WBYTE data-loop transitions.
- The LOW path after the last bit/checksum can have another caller-dependent
  value; do not infer a universal LOW value from this table.

### 5.5 Why the current MZ-700 profile works

Current SD2CMT2:

```text
SHORT = 240 us HIGH + 264 us LOW
LONG  = 464 us HIGH + 494 us LOW
```

For 1Z-009A this is an excellent fixed representation of the canonical
pulse portions:

| Quantity | 1Z-009A derived | SD2CMT2 | Error |
|---|---:|---:|---:|
| SHORT HIGH | 240.533 us | 240 us | -0.533 us |
| SHORT LOW, leader | 264.279 us | 264 us | -0.279 us |
| LONG HIGH | 464.025 us | 464 us | -0.025 us |
| LONG LOW, mark | 494.476 us | 494 us | -0.476 us |

This also matches the Sharp MZ-700 service-manual nominal values
240/264/464/494 us.

**Calibration conclusion:** do not replace the current MZ-700 NORMAL
240/264/464/494 profile with the much shorter values measured from the
emulator WAV. The current profile has substantially stronger ROM/hardware
support than the WAV-derived alternative.

The 1Z-013A PAL ROM is measurably different. If a future project version
needs strict PAL-1Z-013A waveform fidelity, add a separate profile instead
of silently redefining `MZ700_NORMAL_1X`.

### 5.6 Reference Timer3 ticks for MZ-700 source values

These are *reference conversions*, not an instruction to change firmware.

| ROM/path | T | us | nearest Timer3 ticks @16 MHz |
|---|---:|---:|---:|
| 1Z-013A SHORT HIGH | 861 | 242.749 | 3884 |
| 1Z-013A SHORT LOW leader | 946 | 266.714 | 4267 |
| 1Z-013A LONG HIGH | 1667 | 469.991 | 7520 |
| 1Z-013A LONG LOW mark | 1740 | 490.573 | 7849 |
| 1Z-009A SHORT HIGH | 861 | 240.533 | 3849 |
| 1Z-009A SHORT LOW leader | 946 | 264.279 | 4228 |
| 1Z-009A LONG HIGH | 1661 | 464.025 | 7424 |
| 1Z-009A LONG LOW mark | 1770 | 494.476 | 7912 |

### 5.7 MZ-700 NORMAL receive decision timing

The same ROMs also allow a source-based check of the normal receiver.

For monitor-ROM execution, after a successful rising-edge sample inside
`EDGE`, the next data sample in `RBYTE` is modeled as:

```text
detected-edge -> data sample = 103 + 18*N T
```

where `N` is the byte at `$0A4B` used by `DLY3`.

The rising-edge polling loop in ROM is approximately 62 T, therefore a
physical edge can be detected anywhere within approximately one 62-T
polling interval:

```text
earliest sample = 103 + 18*N
latest sample   = earliest + 62
```

For the supplied ROMs:

| ROM | DLY3 N | earliest | latest | window [us] |
|---|---:|---:|---:|---:|
| 1Z-013A PAL | $3F = 63 | 1237 T | 1299 T | 348.758–366.238 |
| 1Z-009A JP | $45 = 69 | 1345 T | 1407 T | 375.746–393.067 |

The 1Z-013A late edge of this static window is very close to Sharp's
nominal MZ-700 read point of 368 us. This is an additional consistency
check for the ROM wait-state model.

These values also explain why pulse profiles that are not perfectly
waveform-faithful can still load reliably: the receiver classifies by a
decision window, not by requiring an exact pulse duration.

---

## 6. MZ-800 native monitor 1Z-013B — exact Z80 pulse audit

The newly supplied 4096-byte image `Mz700a(1).rom` identifies itself at
ROM `$06E7` as:

```text
**  MONITOR 1Z-013B  **
```

SHA-256:

`fa65299ff588e3402973afbb1285dc5a7993efe9265213b64ba8e3a6facd2acf`

The binary matches the 1Z-013B source organization in the MZ-800 Technical
Reference Manual and closes the major open item from revision 1 of this
document.

### 6.1 Why MZ-800 timing constants differ from MZ-700

The relevant 1Z-013B timing constants are:

```text
DLY1 $0759 : LD A,$1B = 27
DLY2 $0760 : LD A,$19 = 25
DLY4 $09A9 : LD A,$73 = 115
DLY3 $0A4A : LD A,$52 = 82
```

The important point is that these larger counters are not evidence of a
slower CMT. They compensate for the different monitor execution timing.

The MZ-700 1Z-013A source uses a delay-loop model of approximately 18 T per
loop count. The MZ-800 1Z-013B constants are chosen for the standard
14-T `DEC A / JP NZ` loop:

```text
MZ700 DLY1: 21 * 18 = 378
MZ800 DLY1: 27 * 14 = 378

MZ700 DLY4: 89 * 18 = 1602
MZ800 DLY4:115 * 14 = 1610

MZ700 DLY3: 63 * 18 = 1134
MZ800 DLY3: 82 * 14 = 1148
```

This is a strong code-level explanation for why simply copying delay
operands between MZ-700 and MZ-800 is wrong.

For 1Z-013B this audit uses standard Z80 instruction timing. The assembler
listing's own comments (`DLY1 ~111.39 us`, `DLY2 ~103.45 us`,
`DLY4 ~458.81 us`, `DLY3 ~331.35 us`) are consistent with this model at
3.546875 MHz.

### 6.2 Exact delay equations

For a normal RAM/no-added-wait Z80 loop:

```text
DLY(N) routine body
 = LD A,N + N*(DEC A + JP NZ) + RET
 = 7 + N*(4+10) + 10
 = 17 + 14*N T

CALL DLY(N), inclusive
 = 17 + (17 + 14*N)
 = 34 + 14*N T
```

Thus for 1Z-013B:

```text
CALL DLY1(27) = 412 T
CALL DLY4(115)= 1644 T
```

The `DLY3` routine is special because it executes `LD A,N; JP $0762`,
entering DLY2 at the loop body:

```text
CALL DLY3(N) = 44 + 14*N T
CALL DLY3(82)= 1192 T
```

### 6.3 Exact MZ-800 generated HIGH widths

`SHORT` at `$0A01` contains two DLY1 calls between its `$E003` writes.

```text
SHORT HIGH
 = 2*CALL_DLY1 + LD A,$02 + LD ($E003),A
 = 2*412 + 7 + 13
 = 844 T
 = 237.956 us
```

`LONG` at `$0A1A` contains one DLY4 call between its writes.

```text
LONG HIGH
 = CALL_DLY4 + LD A,$02 + LD ($E003),A
 = 1644 + 7 + 13
 = 1664 T
 = 469.145 us
```

These are the most context-independent pulse quantities because they are
fully inside the pulse routine.

### 6.4 Exact context-dependent LOW widths

The LOW phase includes the remainder of `SHORT`/`LONG` plus caller code
before the next rising edge. Therefore there is no single exact LOW value.

| Context | T-states | time [us] | nearest Timer3 ticks @16 MHz |
|---|---:|---:|---:|
| SHORT HIGH | 844 | 237.956 | 3807 |
| SHORT LOW, repeated leader (`GAP1`) | 918 | 258.819 | 4141 |
| SHORT LOW, repeated tape mark (`GAP3`) | 908 | 256.000 | 4096 |
| SHORT LOW, data S→L | 896 | 252.617 | 4042 |
| SHORT LOW, data S→S | 906 | 255.436 | 4087 |
| LONG HIGH | 1664 | 469.145 | 7506 |
| LONG LOW, repeated tape mark (`GAP2`) | 1728 | 487.189 | 7795 |
| LONG LOW, data L→L | 1716 | 483.806 | 7741 |
| LONG LOW, data L→S | 1726 | 486.626 | 7786 |

Examples of the low-phase equations:

```text
SHORT tail after falling edge
 = 2*CALL_DLY1 + POP AF + RET
 = 824 + 10 + 10
 = 844 T

SHORT LOW, leader
 = SHORT_tail
 + DEC BC + LD A,B + OR C + JR NZ
 + CALL SHORT + PUSH AF + LD A,$03 + LD ($E003),A
 = 844 + 6 + 4 + 4 + 12 + 17 + 11 + 7 + 13
 = 918 T

SHORT LOW, data S->L
 = 844 + RLCA + CALL C,LONG + pulse-prefix
 = 844 + 4 + 17 + 31
 = 896 T

SHORT LOW, data S->S
 = 844 + RLCA + CALL C(not taken) + CALL NC,SHORT + pulse-prefix
 = 844 + 4 + 10 + 17 + 31
 = 906 T
```

The corresponding LONG equations differ only by replacing the `SHORT` tail
with the 1664-T LONG tail.

### 6.5 Comparison with Sharp service values

Sharp's MZ-800 service documentation gives nominal values:

```text
SHORT HIGH 240 us
SHORT LOW  278 us
LONG  HIGH 470 us
LONG  LOW  494 us
READ POINT diagram: 379 us
READ POINT prose:   368 us
```

Direct Z80 execution gives:

```text
SHORT HIGH 237.956 us
SHORT LOW  approximately 252.617..258.819 us in steady/common contexts
LONG  HIGH 469.145 us
LONG  LOW  approximately 483.806..487.189 us in steady/common contexts
```

The HIGH portions agree extremely well with the manual. The software-derived
LOW portions are shorter than the manual's nominal LOW values. The manual
values must therefore be treated as hardware/nominal waveform guidance,
while the table above is the exact digital `$E003` software-edge schedule.

Do not collapse these two evidence types into one fake “exact” value.

### 6.6 Native MZ-800 receive decision window

The successful rising-edge read in `EDGE` is at `$061A`. In `RBYTE`, the
later data read is reached after:

```text
AND $20             7 T
JR Z,EDGE-loop       7 T  (not taken after successful rising edge)
RET                 10 T
JP C,RBY3           10 T  (not taken)
CALL DLY3(N)       44 + 14*N T
LD A,(DE)            7 T  (data sample)
-----------------------------------------------
detected-edge -> sample = 85 + 14*N T
```

For native MZ-800 `N=$52=82`:

```text
earliest detected-edge sample
 = 1233 T
 = 347.630 us
```

The successful rising-edge polling loop repeats every approximately 52 T,
so the physical edge can precede the detected edge by up to one poll:

```text
static physical-edge sample window
 = 1233..1285 T
 = 347.630..362.291 us
```

This is close to the service-manual 368/379-us read-point data once input
circuit propagation and documentation rounding are allowed for.

### 6.7 Current SD2CMT2 MZ-800 NORMAL versus Z80

Current project:

```text
SHORT 250/250 us
LONG  500/500 us
```

Compared with the exact Z80 schedule:

| Quantity | Z80 reference | current | delta |
|---|---:|---:|---:|
| SHORT HIGH | 237.956 us | 250 us | 12.044 us (+5.06 %) |
| SHORT LOW leader | 258.819 us | 250 us | -8.819 us (-3.41 %) |
| SHORT LOW data S→S | 255.436 us | 250 us | -5.436 us (-2.13 %) |
| LONG HIGH | 469.145 us | 500 us | 30.855 us (+6.58 %) |
| LONG LOW tape mark | 487.189 us | 500 us | 12.811 us (+2.63 %) |
| LONG LOW data L→S | 486.626 us | 500 us | 13.374 us (+2.75 %) |

**Calibration interpretation:** current 250/250/500/500 is a usable symmetric
compatibility approximation, but it is not ROM-exact.

If future work wants waveform fidelity rather than a symmetric model, the
best solution is not another single four-number guess. It is to allow
context-dependent LOW timing, or at minimum document which context was
chosen for a fixed profile.

A reasonable *reference-only* rounded fixed approximation of common 1Z-013B
software edges would be near:

```text
SHORT HIGH ~238 us
SHORT LOW  ~253..259 us
LONG  HIGH ~469 us
LONG  LOW  ~484..487 us
```

Do not change firmware to these values without real-MZ regression.

---

## 7. MZ-800 turbo loader — Intercopy (IC)

**Target machine:** MZ-800.

**Project modes:**

```text
IC_1_4
IC_1_3
IC_1_2
```

**Embedded loader:** 96 bytes, SHA-256
`a52224f33e5ad8ca6d436257f58ef5802c4a4a8a7c8e0798e31a0a968a6eeab2`.

### 7.1 What IC changes in the monitor

The IC loader operates on the RAM copy of the low monitor and performs two
timing-relevant modifications.

First, it replaces the `RET` at monitor `EDGE+$1E`, address `$061F`, with:

```asm
JP $115C
```

The loader byte sequence is visible directly in the embedded code:

```text
3E C3       LD A,$C3
32 1F 06    LD ($061F),A
21 5C 11    LD HL,$115C
22 20 06    LD ($0620),HL
```

Second, it obtains the selected speed byte from the fake header metadata and
writes it to the DLY3 operand at `$0A4B`.

In the current SD2CMT2 fake header:

```text
metadata byte $18 = original file type
metadata byte $19 = IC speed byte
```

The IC loader reads the pair via `$1108`, then uses the high byte for
`$0A4B`.

Project speed operands:

```text
IC_1_4 -> $11 = 17
IC_1_3 -> $16 = 22
IC_1_2 -> $20 = 32
```

### 7.2 IC EDGE return hook cost

Hook at `$115C`:

```asm
PUSH BC
LD   A,($1110)
XOR  $0C
LD   ($1110),A
LD   BC,$06CF
OUT  (C),A
POP  BC
RET
```

Standard RAM-executed Z80 cost:

```text
11 + 13 + 7 + 13 + 10 + 12 + 10 + 10 = 86 T
```

The original `$061F` instruction was `RET` (10 T). It is replaced by a
10-T `JP $115C` plus the 86-T hook, therefore the **net receiver delay added
by IC is +86 T**.

### 7.3 IC exact receiver equation

For RAM execution:

```text
base detected-edge -> sample = 85 + 14*N T
IC detected-edge -> sample   = 85 + 14*N + 86 T
poll uncertainty             = 0..52 T
```

So:

```text
IC earliest = 171 + 14*N T
IC latest   = 223 + 14*N T
```

### 7.4 IC receiver windows and current PWM

| Mode | DLY3 | sample T window | sample [us] | current SHORT H/L [us] | current LONG H/L [us] | SHORT-high margin [us] | LONG-high margin [us] |
|---|---:|---:|---:|---:|---:|---:|---:|
| `IC_1_4` | `0x11` (17) | 409–461 | 115.313–129.974 | 112/80 | 176/160 | 3.313 | 46.026 |
| `IC_1_3` | `0x16` (22) | 479–531 | 135.048–149.709 | 112/96 | 224/192 | 23.048 | 74.291 |
| `IC_1_2` | `0x20` (32) | 619–671 | 174.520–189.181 | 144/112 | 256/224 | 30.520 | 66.819 |

Margin definitions:

```text
SHORT margin = earliest sample - SHORT HIGH
LONG margin  = LONG HIGH - latest sample
```

The IC_1_4 SHORT margin is the tightest of all current turbo modes. That mode
should be the first regression target if IC timings are ever changed.

### 7.5 IC phase/polarity in current SD2CMT2

`mzf_stage_uses_low_first_timing()` returns true for IC turbo stages.
Therefore current IC pulses are physically started LOW-first. This is a
phase decision separate from pulse width and must be preserved during any
calibration change unless a hardware trace proves otherwise.

### 7.6 IC calibration meaning

The loader does **not** generate the transmitted waveform. It defines a
receiver decision window.

Therefore the code-derived requirement is:

```text
SHORT must be LOW before the receiver sample window
LONG must still be HIGH through the receiver sample window
```

The current asymmetric IC H/L values are compatibility waveforms chosen
around that decision window. Their LOW widths determine cadence and the next
edge, but cannot be derived from the single receiver sample point alone.

---

## 8. MZ-800 turbo loader — TurboCopy (TC)

**Target machine:** MZ-800.

**Project modes:**

```text
TC_1_3
TC_1_2
```

**Embedded loader:** 90 bytes loaded at `$D400`, SHA-256
`4ab47c752ae0d04ce341d9be221336ed51b30a9c698d09aed4370172917ee790`.

### 8.1 TC monitor modification

The TC loader carries its speed byte at loader offset `$4B`:

```text
runtime address $D44B
```

It executes:

```asm
LD A,($D44B)
LD ($0A4B),A
```

so the byte directly becomes the DLY3 operand.

Current SD2CMT2 values:

```text
TC_1_3 -> $1B = 27
TC_1_2 -> $29 = 41
```

TC does **not** install the IC `$061F -> $115C` EDGE hook.

The TC loader also arranges for the low monitor to execute from RAM before
the accelerated `RDDAT` path, therefore use normal no-wait Z80 instruction
timing for the patched receive routine.

### 8.2 TC exact receiver equation

With no IC hook:

```text
earliest sample = 85 + 14*N T
latest sample   = earliest + 52 T
```

### 8.3 TC receiver windows and current PWM

| Mode | DLY3 | sample T window | sample [us] | current SHORT H/L [us] | current LONG H/L [us] | SHORT-high margin [us] | LONG-high margin [us] |
|---|---:|---:|---:|---:|---:|---:|---:|
| `TC_1_3` | `0x1B` (27) | 463–515 | 130.537–145.198 | 112/112 | 204/204 | 18.537 | 58.802 |
| `TC_1_2` | `0x29` (41) | 659–711 | 185.797–200.458 | 144/144 | 288/288 | 41.797 | 87.542 |

Both current TC modes have wide classification margin.

### 8.4 TC polarity and framing details

Current SD2CMT2 sets:

```text
mzf_wave_invert_signal = true
```

for TC turbo. Thus TC's physical waveform polarity is automatically inverted
relative to the direct MZF/IC path. This inversion does not change timing
intervals, but it is part of the proven loader compatibility and must be
treated as a first-class calibration parameter.

Current TC-specific framing parameters include:

```text
TC_1_3 turbo leader: 15130 SHORT pulses
TC_1_2 turbo leader: 11239 SHORT pulses
TC trailing:         98 SHORT pulses
TC start delay:      110 ms
```

These values are **framing/transport parameters**, not DLY3 readpoint
parameters. Do not derive or modify them from the equation above.

### 8.5 TC calibration meaning

Exactly as with IC, the source-derived truth is the receiver sample window.
The current symmetric `112/112, 204/204` and `144/144, 288/288` waveforms
are implementation choices with substantial readpoint margin, not literal
pulse widths generated by TurboCopy itself.

---

## 9. MZ-700 turbo loader — FAST3

**Target machine:** MZ-700 monitor family.

This section is intentionally separate from IC/TC because FAST3 is built
around the supplied MZ-700 1Z-009A monitor logic, not the MZ-800 loader
family.

### 9.1 Exact project transformation

The project embeds the exact 1Z-009A QADCN table and constructs a header-only
runtime. Before accelerated data loading the runtime:

1. maps/copies the monitor so the CMT code executes from RAM,
2. writes only the DLY3 operand at `$0A4B`,
3. restores original SIZE/LOAD fields,
4. calls the public `RDDAT` vector at `$002A`.

The timing patch is:

```asm
LD A,$15
LD ($0A4B),A
```

so:

```text
FAST3 DLY3 N = $15 = 21
```

The project verification explicitly rejects the old `$0512` speed patch and
locks `$0A4B` as the only timing patch.

### 9.2 FAST3 exact receiver equation

FAST3 installs no IC EDGE hook. Once the monitor code is in RAM:

```text
earliest sample = 85 + 14*21
                = 379 T

latest sample   = 431 T
```

For the supplied Japanese 1Z-009A clock 3.579545 MHz:

```text
sample window = 105.879..120.406 us
```

For use on a 3.546875-MHz PAL-compatible machine, the same RAM instruction
path would be:

```text
sample window = 106.855..121.515 us
```

The distinction is small relative to the current pulse margin, but the clock
must still be recorded in any future audit.

### 9.3 FAST3 current PWM and margins

Current SD2CMT2:

```text
SHORT = 80 us HIGH + 80 us LOW
LONG  = 160 us HIGH + 160 us LOW
```

For the Japanese MZ-700 clock:

```text
SHORT-high margin
 = 105.879 - 80
 = 25.879 us

LONG-high margin
 = 160 - 120.406
 = 39.594 us
```

Thus both bit classes remain well separated from the complete static
readpoint window.

### 9.4 FAST3 phase and boundary behavior

Current project deliberately keeps FAST3 **HIGH-first**, unlike IC.

It also holds READ LOW for:

```text
400 ms
```

between the synthetic header and FAST3 payload stage.

That 400-ms interval is an inter-stage transport/startup behavior. It is not
part of SHORT/LONG pulse timing and must remain outside the DLY3 timing
equation.

### 9.5 FAST3 calibration meaning

FAST3 is a receiver-timing modification, not a transmitter pulse generator.

The old comment saying the input sample is “about 97 us after the edge”
counts only part of the delay mechanism. The complete static
detected-edge-to-sample path is the window above.

Therefore `80/160 us` should be justified by **decision margin**, not by
claiming that the patched ROM “generates 80/160-us pulses”.

---

## 10. Current NORMAL 2x and 3x modes

Current project values:

```text
MZ800 NORMAL 2x:
  SHORT = 2178 Timer3 ticks = 136.125 us per half
  LONG  = 4425 Timer3 ticks = 276.5625 us per half

MZ800 NORMAL 3x:
  SHORT = 1811 Timer3 ticks = 113.1875 us per half
  LONG  = 3265 Timer3 ticks = 204.0625 us per half
```

The current source explicitly says these came from 44.1 kHz PCM references.

Crucially, selecting `LOADER_MODE_NORMAL_1_2` or
`LOADER_MODE_NORMAL_1_3` does **not** install a receiver patch comparable to
IC/TC/FAST3.

Therefore these profiles are classified:

```text
EMPIRICAL-WAV / EXTERNAL-RECEIVER-ASSUMPTION
```

An AI agent must not label them ROM-derived or loader-derived. Before future
recalibration, establish which receiving monitor/loader is expected to
decode them.

---

## 11. UL LOW/HIGH modes are not PWM modes

The project's own UL receivers (`LOW` and `HIGH`, including MZ-700 UL)
use a software handshake:

```text
Z80 waits for WRITE phase
Z80 samples READ
Z80 changes $E003
AVR sees phase change
AVR drives next READ bit
```

The receiver loop contains operations equivalent to:

```asm
LD A,(DE)
BIT 4,A
JR Z/NZ,wait
```

The steady polling loop is about 27 standard Z80 T-states when running from
RAM.

`LOW` and `HIGH` in these loader names describe loader placement/address
choice, **not pulse polarity and not SHORT/LONG timing**.

Classification:

```text
type = HANDSHAKE
short_high = N/A
short_low  = N/A
long_high  = N/A
long_low   = N/A
```

Calibration of UL must use handshake turnaround/timeout analysis, not the
PWM table.

---

## 12. Framing values: keep separate from pulse calibration

Current project also contains leader/tape-mark counts. They are not pulse
lengths and should not be silently changed as part of a half-wave audit.

Current profile highlights:

```text
MZ700 NORMAL: header 22000 SHORT, data 11000 SHORT
MZ800 NORMAL: header 6344 SHORT, data 6344 SHORT
IC payload:   5500 SHORT
TC_1_3:       15130 SHORT
TC_1_2:       11239 SHORT
```

Sharp service documentation uses 22000/11000 for standard cassette framing.
The current MZ800 6344/6344 behavior is therefore a separate framing/design
question. Preserve it until a dedicated framing audit and hardware A/B test
are performed.

Likewise, MZ-700 documentation describes duplicated blocks separated by
SHORT pulses; current profile behavior should be audited separately from
pulse-width calibration.

---

## 13. Recommended calibration policy for SD2CMT2

### NORMAL ROM-compatible modes

Prefer:

```text
supplied ROM bytes
-> exact CMT write path
-> machine clock + verified wait-state model
-> contextual pulse timing
-> fixed Timer3 approximation
-> real-hardware regression
```

For a fixed four-value profile, explicitly state which contexts were chosen
as representative.

### Turbo receiver modes

Prefer:

```text
exact loader bytes
-> exact DLY3/EDGE patches
-> sample window
-> choose SHORT/LONG HIGH widths with margin
-> choose LOW widths for safe cadence/framing
-> real-hardware regression
```

Do **not** ask “what pulse does the loader generate?” when the loader is only
a receiver.

### UL modes

Do not put UL into a PWM pulse table. Audit handshake timing separately.

---

## 14. Machine-readable summary for future AI agents

The block below is deliberately redundant with the prose. It is intended as
a stable extraction target.

```yaml
schema: sd2cmt2-cmt-timing-reference-v2
project:
  repo: bales0/MZ-SD2CMT2
  commit: fabf8fc0d032a0363b991be2c1e388fc5657d2c5
  latest_checked: 2026-08-29
  avr_hz: 16000000

scope:
  tap: excluded

roms:
  mz700_1z013a_pal:
    file: 1z-013a(2).rom
    sha256: ae1d65717414d4693158cbbd9ab707aa43e4e1ac0b2ae0e13ee3f68c66cba81b
    cpu_hz: 3546875
    execution_model: mz700_monitor_wait_timing
    dly3_operand: 0x3f
    confidence: ROM-PATH-HIGH

  mz700_1z009a_jp:
    file: mz700_1z-009a_jp(1).rom
    sha256: b0d16889ac3e2a80cc3bc9445bc95bc9988df7b6115124f284850667cf45ff9f
    cpu_hz: 3579545
    execution_model: mz700_monitor_wait_timing
    dly3_operand: 0x45
    canonical_fixed_us:
      short_high: 240
      short_low: 264
      long_high: 464
      long_low: 494
    confidence: ROM-PATH-HIGH

  mz800_1z013b:
    file: Mz700a(1).rom
    sha256: fa65299ff588e3402973afbb1285dc5a7993efe9265213b64ba8e3a6facd2acf
    identity_string: "**  MONITOR 1Z-013B  **"
    cpu_hz: 3546875
    execution_model: standard_z80_timing_for_1z013b_delay_code
    delay_operands:
      dly1: 0x1b
      dly2: 0x19
      dly4: 0x73
      dly3: 0x52
    generated_waveform_t:
      short_high: 844
      short_low:
        leader: 918
        tape_mark: 908
        data_S_to_L: 896
        data_S_to_S: 906
      long_high: 1664
      long_low:
        tape_mark: 1728
        data_L_to_L: 1716
        data_L_to_S: 1726
    receiver_sample_t:
      earliest_from_detected_edge: 1233
      latest_from_physical_edge_static_model: 1285
    confidence: ROM-PATH-HIGH

  mz800_9z504m:
    file: 9Z_504M(4).ROM
    sha256: 68a91b82517d5642e250cdddb519de780fb20bcde39b2de8baee387ca6bf446a
    role: high_monitor
    delegates_rddat_vector_002a: true
    paired_low_monitor: mz800_1z013b

turbo_loaders:
  mz800_ic:
    target: MZ800
    loader_bytes: 96
    loader_sha256: a52224f33e5ad8ca6d436257f58ef5802c4a4a8a7c8e0798e31a0a968a6eeab2
    execution: low_monitor_copy_in_ram
    edge_patch:
      address: 0x061f
      replacement: JP_0x115c
      net_extra_t: 86
    modes:
      IC_1_4:
        dly3_n: 17
        sample_t: [409, 461]
        current_us:
          short: [112, 80]
          long: [176, 160]
      IC_1_3:
        dly3_n: 22
        sample_t: [479, 531]
        current_us:
          short: [112, 96]
          long: [224, 192]
      IC_1_2:
        dly3_n: 32
        sample_t: [619, 671]
        current_us:
          short: [144, 112]
          long: [256, 224]
    physical_phase: LOW-first
    confidence: LOADER-PATH-HIGH

  mz800_tc:
    target: MZ800
    loader_bytes: 90
    load_address: 0xd400
    loader_sha256: 4ab47c752ae0d04ce341d9be221336ed51b30a9c698d09aed4370172917ee790
    execution: low_monitor_copy_in_ram
    edge_hook_t: 0
    speed_source_address: 0xd44b
    speed_patch_address: 0x0a4b
    modes:
      TC_1_3:
        dly3_n: 27
        sample_t: [463, 515]
        current_us:
          short: [112, 112]
          long: [204, 204]
      TC_1_2:
        dly3_n: 41
        sample_t: [659, 711]
        current_us:
          short: [144, 144]
          long: [288, 288]
    physical_polarity: inverted_by_sd2cmt2
    confidence: LOADER-PATH-HIGH

  mz700_fast3:
    target: MZ700
    source_rom: mz700_1z009a_jp
    execution: monitor_copy_in_ram
    dly3_n: 21
    speed_patch_address: 0x0a4b
    edge_hook_t: 0
    sample_t: [379, 431]
    current_us:
      short: [80, 80]
      long: [160, 160]
    physical_phase: HIGH-first
    pre_payload_low_delay_ms: 400
    confidence: LOADER-PATH-HIGH

non_pwm:
  ul_low: HANDSHAKE
  ul_high: HANDSHAKE
  mz700_ul_low: HANDSHAKE
  mz700_ul_high: HANDSHAKE

empirical_profiles:
  mz800_normal_2x:
    short_half_ticks: 2178
    long_half_ticks: 4425
    source: 44.1kHz_PCM
  mz800_normal_3x:
    short_half_ticks: 1811
    long_half_ticks: 3265
    source: 44.1kHz_PCM
```

---

## 15. AI maintenance contract

Any future AI/code agent changing CMT timing in this project **must**:

1. identify the exact mode/profile being changed;
2. state whether it is `generated waveform`, `receiver readpoint`, or
   `handshake`;
3. identify the exact ROM/loader hash or frozen source commit;
4. identify the CPU clock;
5. state whether code executes from ROM or RAM;
6. state the wait-state model;
7. show the exact Z80 T-state equation;
8. show conversion to microseconds;
9. show conversion to Timer3 ticks;
10. preserve signal phase/polarity (`HIGH-first`/`LOW-first`, inversion);
11. compare against the current profile;
12. report SHORT and LONG decision margins for receiver-derived modes;
13. run or request a real-hardware regression before removing a
    hardware-proven profile;
14. never use a quantized WAV as a higher authority than a verified
    ROM/loader execution path without an explicit documented reason.

If a value cannot be proven, label it `EMPIRICAL`, `MANUAL`, or
`TRACE-PENDING`; do not invent precision.

---

## 16. Open items

Native MZ-800 timing is now statically closed to the same level as the
available ROM-path analysis: the supplied 1Z-013B binary is identified,
hashed and cycle-counted.

The remaining work is **validation and automation**, not missing source data:

- acquire a cycle-accurate runtime trace of `$E003` writes and `$E002` reads
  on a model that reproduces the machine's memory timing;
- capture real MZ-700 and MZ-800 digital CMT edges with a logic analyzer
  before the analog cassette circuitry when possible;
- compare the trace against this document's T-state equations;
- A/B test any future replacement of the current symmetric MZ-800
  `250/250/500/500` profile;
- separately audit framing/leader counts, because this document intentionally
  treats leader count and pulse width as different calibration dimensions.

### Recommended automated trace format

A future debug build/emulator should emit:

```text
cycle=<absolute Z80 T> pc=<PC> addr=E003 write=<0|1> map=<ROM|RAM>
cycle=<absolute Z80 T> pc=<PC> addr=E002 read=<0|1>  map=<ROM|RAM>
```

For receiver tests, feed a deterministic pattern such as:

```text
00 FF 55 AA
```

The analysis should automatically report:

```text
S->S
S->L
L->S
L->L
rising-edge polling latency
detected-edge -> sample
physical-edge -> sample window
```

The trace must include memory mapping so ROM execution and RAM-executed
turbo monitor code cannot be confused.

---

## 17. External reference documents

These are supporting references; the supplied binaries and frozen project
source remain the primary reproducible inputs.

- Sharp MZ-700 Owner's Manual / 1Z-013A source listing:
  `https://eaw.app/Downloads/Manuals/Sharp/MZ-700_Owners_Manual.pdf`
- Sharp MZ-700 Service Manual:
  `https://old.sharpmz.org/mz-700/download/sm700.pdf`
- Sharp MZ-800 Technical Reference Manual / 1Z-013B source listing (used to cross-check the supplied low-monitor binary):
  `https://www.radeksuk.cz/sharp/gdg/dokumentace/MZ800_Technical_reference_manual.pdf`
- Sharp MZ-800 Service Manual:
  `https://www.idealine.info/sharpmz/mz-800/download/sm800.pdf`
- MZ-800 ROM layout reference:
  `https://www.idealine.info/sharpmz/mz-800/dldrom.htm`

---

## 18. Current audit verdict

The audit now has a source-derived Z80 basis for both native monitor
families and for every implemented MZ turbo receiver mode.

### Native MZ-700

The earlier WAV-first conclusion remains corrected:

**retain MZ-700 NORMAL 240/264/464/494 us as the current fixed compatibility
profile unless a dedicated PAL/JP split is introduced.**

The supplied ROMs show that exact software-edge timing is contextual, but
the current profile is strongly supported by the Japanese 1Z-009A ROM and
Sharp's nominal hardware values.

### Native MZ-800

The supplied `1Z-013B` binary closes the missing-ROM gap.

The exact Z80 software-edge schedule is approximately:

```text
SHORT HIGH 237.956 us
SHORT LOW  252.617..258.819 us in common steady contexts
LONG  HIGH 469.145 us
LONG  LOW  483.806..487.189 us in common steady contexts
```

Therefore current `250/250/500/500 us` is a **symmetric compatibility
approximation**, not an exact reproduction of 1Z-013B.

No firmware change is made by this audit. Any later change should compare
real-hardware reliability against both the current profile and the
ROM-derived contextual reference.

### MZ-800 Intercopy (IC)

IC is a receiver modification of the RAM monitor copy. It patches DLY3 and
adds a **net +86 T EDGE-return hook**. The three current waveforms have
source-derived decision windows; IC_1_4 has the tightest SHORT margin and
deserves the most conservative treatment.

### MZ-800 TurboCopy (TC)

TC patches DLY3 directly from `$D44B` to `$0A4B`, with no IC EDGE hook.
Both current TC modes have substantial static readpoint margin. TC's signal
inversion and 98-SHORT trailing sequence are separate compatibility
parameters and must not be lost in a timing refactor.

### MZ-700 FAST3

FAST3 is explicitly an MZ-700 receiver mode. It copies the monitor into RAM,
patches only `$0A4B` to `$15`, and uses the normal EDGE path. Current
`80/80, 160/160 us` is justified by the derived readpoint window, not by a
claim that the ROM itself generates those widths.

### Overall rule

For future SD2CMT2 changes:

```text
native NORMAL:
    ROM-generated edge schedule is the timing source

IC / TC / FAST3:
    loader receiver window is the timing source

UL:
    handshake turnaround is the timing source

WAV:
    regression evidence only, not the highest timing authority
```

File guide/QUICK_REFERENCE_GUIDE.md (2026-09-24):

# MZ-SD2CMT2 – Reborn
## Quick Reference Guide

**Firmware 1.0**

This guide contains the basic controls and everyday operating steps only.

---

## Front-panel buttons

| Button | Basic function |
|---|---|
| **REWIND** | previous / up |
| **FFWD** | next / down |
| **STOP** | back / stop |
| **RECORD** | record |
| **PLAY** | select / play / confirm |

---

## SD-card browser

| Action | Control |
|---|---|
| Previous item | **REWIND** |
| Next item | **FFWD** |
| Enter folder / select file | short **PLAY** |
| Open PLAY settings | long **PLAY** |
| Go to parent folder | short **STOP** |
| Go directly to root | long **STOP** from a subfolder |
| Open SYSTEM menu | long **STOP** at root |
| Start recording with current settings | short **RECORD** |
| Open RECORD settings | long **RECORD** |

Holding **FFWD** or **REWIND** scrolls repeatedly.

### Browser counter

```text
3/28
```

means item 3 of 28.

```text
3I28
```

means item 3 of 28 and playback information is available for the selected MZF/MZT.

---

## Load and play a file

1. Select the file with **FFWD / REWIND**.
2. Press **PLAY**.
3. With `PLAY CTRL = MOTOR`, start the normal LOAD operation on the Sharp.
4. MZ-SD2CMT2 starts when the computer requests the tape.
5. Press **PLAY** during playback to pause or resume.
6. Press **STOP** to stop and return.

Recommended basic settings:

```text
PLAY CTRL = MOTOR
LOADER    = NORMAL
SPEED     = 1:1
```

If your library contains matching MFI/MTI information, use:

```text
PLAY CTRL = MOTOR
LOADER    = AUTO
```

---

## MZT multi-record files

Opening an MZT first shows its record selector.

| Action | Control |
|---|---|
| Previous record | **REWIND** |
| Next record | **FFWD** |
| Play selected record | **PLAY** |
| Return to browser | **STOP** |

During MZT playback, **STOP** first returns to the MZT record selector. Press **STOP** again to return to the main browser.

---

## PLAY controls

| Control | Action |
|---|---|
| **PLAY** | start / pause / resume |
| **STOP** | stop / back |
| **FFWD / REWIND** | select MZT record when the MZT selector is open |

Common display states:

| Display | Meaning |
|---|---|
| `RDY` | ready |
| `PLY` | playing |
| `PLA` | playing with information selected automatically |
| `PAU` | paused |
| `ERR` | error |

Pause reason at the end of the line:

```text
U = paused by user
M = paused by MOTOR control
```

---

## Recording

From the browser:

```text
short RECORD = start recording with current settings
long  RECORD = open RECORD settings
```

During recording:

| Control | Action |
|---|---|
| **PLAY** | pause / resume; also starts when manually armed |
| short **STOP** | finish and save |
| long **STOP** | cancel recording |

> **Important:** long **STOP** cancels the recording. If a capture file has already been created, it is deleted.

When stopping normally, wait while:

```text
SAVING ...
```

is displayed. The recording is finished when the saved screen appears.

All normal recordings are stored in:

```text
/RECORDINGS
```

---

## RECORD settings

Open the menu with long **RECORD**.

Use:

```text
FFWD / REWIND = move between settings
PLAY          = change / confirm
STOP          = return
```

Main choices are:

- recording type
- recording mode
- AutoName on/off

For an ordinary Sharp SAVE directly to MZF, a useful starting setup is:

```text
REC TYPE = MZF
REC MODE = MOTOR
AUTONAME = ON
```

### Recording modes

| Mode | Behaviour |
|---|---|
| `MOTOR` | follows the Sharp MOTOR signal |
| `AUTO` | waits for signal activity and stops automatically after inactivity |
| `MANUAL` | recording is controlled by the user |

---

## Display basics

A vertical bar at the right side of the display shows operating margin.

```text
high bar = good
low bar  = pay attention
```

Common messages:

| Display | Meaning / action |
|---|---|
| `INSERT CARD` | insert the SD card |
| `SD CARD ERROR` | press **RECORD** to retry |
| `EMPTY` | no visible files in the folder |
| `WAIT SIGNAL` | AUTO recording is armed |
| `PAUSED ... M` | waiting because of MOTOR control |
| `SAVING` | wait; do not remove the SD card |
| `SVD` | recording saved |
| `REC CANCELLED` | recording cancelled |
| `FILE DELETED` | cancelled recording file was deleted |

---

## PLAY settings

Open with long **PLAY** from the browser.

Use:

```text
FFWD / REWIND = move between settings
PLAY          = change / confirm
STOP          = return
```

For normal use, keep:

```text
PLAY CTRL = MOTOR
```

Use `MANUAL` only when you want playback to ignore MOTOR control.

---

## SYSTEM menu

At the root browser, long **STOP** opens the SYSTEM menu.

Use:

```text
FFWD / REWIND = move
PLAY          = change / confirm
STOP          = return
```

The ABOUT screen shows firmware version 1.0.

---

## Most important shortcuts

```text
REWIND        previous
FFWD          next
PLAY short    select / play
PLAY long     PLAY settings
STOP short    back / stop / save recording
STOP long     root or SYSTEM; during RECORD = CANCEL
RECORD short  start recording
RECORD long   RECORD settings
```

**Remember:** while recording, short **STOP** saves; long **STOP** cancels.

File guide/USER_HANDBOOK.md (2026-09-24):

# MZ-SD2CMT2 – Reborn
## User Handbook

**Extended SD-card CMT emulator / recorder for Sharp MZ computers**  
**Handbook draft for firmware 1.0**

> **Draft status**
>
> This is the first full user-handbook draft. It is intentionally more detailed than the project README and is designed both for users who simply want to replace the cassette recorder and for experienced users who want to use loader profiles, MZT containers, MFI/MTI metadata, direct MZF recording, AutoName and diagnostic information.
>
> The layout and wording are intended to be refined before a later PDF edition. LCD examples in this Markdown version are text mock-ups of the real 16×2 display. In the final PDF they can be replaced or supplemented by graphical LCD renders and photographs.

<p align="center">
  MZ-SD2CMT2 Reborn
</p>

---

## Contents

1. [Who this handbook is for](#1-who-this-handbook-is-for)
2. [What MZ-SD2CMT2 does](#2-what-mz-sd2cmt2-does)
3. [Quick start – load your first MZF](#3-quick-start--load-your-first-mzf)
4. [Front-panel controls](#4-front-panel-controls)
5. [Understanding the 16×2 LCD](#5-understanding-the-162-lcd)
6. [Using the SD-card browser](#6-using-the-sd-card-browser)
7. [Supported file formats](#7-supported-file-formats)
8. [Playing files](#8-playing-files)
9. [PLAY settings](#9-play-settings)
10. [Loader modes and speed profiles](#10-loader-modes-and-speed-profiles)
11. [MFI and MTI metadata](#11-mfi-and-mti-metadata)
12. [MZT multi-record tapes](#12-mzt-multi-record-tapes)
13. [Recording](#13-recording)
14. [AutoName and automatic profile detection](#14-autoname-and-automatic-profile-detection)
15. [Understanding the buffer indicator](#15-understanding-the-buffer-indicator)
16. [System settings](#16-system-settings)
17. [Keypad calibration](#17-keypad-calibration)
18. [Recommended setups](#18-recommended-setups)
19. [Troubleshooting](#19-troubleshooting)
20. [Technical reference](#20-technical-reference)
21. [Glossary](#21-glossary)

---

# 1. Who this handbook is for

MZ-SD2CMT2 can be used at two very different levels.

### If you only want a cassette replacement

You do **not** need to understand tape timing, loader profiles, MFI/MTI files or Ultra Fast loading. For normal use, read:

- Quick Start
- Front-panel controls
- SD-card browser
- Playing files
- the basic part of Recording
- Troubleshooting

A normal MZF can be treated very much like a cassette already inserted in a tape recorder: select it, let the Sharp request the tape, and allow MZ-SD2CMT2 to provide the signal.

### If you want the advanced features

Continue with:

- Loader modes and speed profiles
- Ultra Fast loading
- MZT containers
- MFI/MTI metadata
- direct MZF recording
- AutoName
- detected tape profiles
- buffer diagnostics
- MOTOR/AUTO/MANUAL capture modes

These functions allow MZ-SD2CMT2 to do considerably more than simply reproduce a cassette waveform.

---

# 2. What MZ-SD2CMT2 does

MZ-SD2CMT2 is a solid-state replacement and extension for the cassette/CMT interface used by the Sharp MZ family, with the **Sharp MZ-800 as the primary target**.

Instead of storing programs on magnetic tape, files are kept on an SD card. The device generates or reproduces the signal expected by the Sharp computer and can also capture data written by the Sharp back to the CMT interface.

The firmware supports:

- direct playback of **MZF**
- multi-record **MZT**
- **M12**
- waveform playback from **WAV**
- pulse/edge formats **LEP** and **L16**
- ZX Spectrum-style **TAP**
- recording to **MZF**
- recording to **WAV 44.1 kHz**
- recording to **WAV 22.05 kHz**
- recording to **L16**
- recording to **LEP**
- automatic naming from detected tape headers
- automatic recognition of several loader/tape profiles
- NORMAL and turbo playback profiles
- Ultra Fast loading
- MFI/MTI sidecar metadata
- MOTOR-controlled, AUTO-triggered and MANUAL playback/recording
- optional switching between the internal SD emulator and an external physical CMT unit

The original-compatible modular hardware and the dedicated PCB use the same basic Sharp CMT signals.

---

# 3. Quick start – load your first MZF

This is the shortest path for a user who simply wants to load software.

## 3.1 Prepare the SD card

Copy your MZF files to the SD card. Folders may be used to organise games, utilities and other software.

A simple example:

```text
/
├── GAMES/
│   ├── PACMAN.MZF
│   ├── MANICMIN.MZF
│   └── ...
├── BASIC/
└── DEMOS/
```

Insert the card and switch on MZ-SD2CMT2.

## 3.2 Browse to the program

The five front-panel buttons correspond to:

```text
REWIND   = up / previous
FFWD     = down / next
STOP     = back
RECORD   = record
PLAY     = select / play
```

Example browser display:

```text
+----------------+
|../GAMES    3/28|
|PACMAN.MZF      |
+----------------+
```

`3/28` means that the highlighted entry is item 3 of 28 visible entries in the current directory.

Press **PLAY** briefly to select `PACMAN.MZF`.

## 3.3 Load from the Sharp

With the default **PLAY CTRL = MOTOR** setting, MZ-SD2CMT2 waits for the Sharp computer to activate the cassette motor/control signal.

The display may show:

```text
+----------------+
|PACMAN.MZF     █|
|PAUSED         M|
+----------------+
```

The `M` in the final column means that playback is waiting because of **MOTOR control**.

Start the normal cassette load operation on the MZ-800. When the Sharp activates MOTOR, MZ-SD2CMT2 begins sending the tape data.

During normal playback:

```text
+----------------+
|PACMAN.MZF     █|
|PLY 00:08/01:42 |
+----------------+
```

`PLY` means playback is active. The time before `/` is elapsed time; the value after `/` is the nominal total duration.

## 3.4 Stop or leave playback

Press **STOP** to return to the browser.

For ordinary use, that is all you need to know.

---

# 4. Front-panel controls

MZ-SD2CMT2 uses the familiar five-button LCD Keypad Shield layout or equivalent dedicated front-panel buttons.

The firmware maps them as follows:

| Physical label | Logical function | Typical browser function |
|---|---|---|
| **REWIND** | UP | previous item |
| **FFWD** | DOWN | next item |
| **STOP** | LEFT / BACK | parent / back |
| **RECORD** | RIGHT | start recording |
| **PLAY** | SELECT | open / play / confirm |

The exact action depends on the current screen.

## 4.1 Browser shortcuts

| Button | Short press | Long press |
|---|---|---|
| REWIND | previous entry | repeated scrolling while held |
| FFWD | next entry | repeated scrolling while held |
| STOP | parent directory | from a subdirectory: root; from root: SYSTEM menu |
| RECORD | start recording with current settings | open RECORD settings |
| PLAY | enter directory or select file | open PLAY settings |

## 4.2 PLAY screen

| Button | Action |
|---|---|
| PLAY | start / pause / resume |
| STOP | stop and return; in MZT, first returns to the MZT record selector |
| REWIND | previous MZT record while the MZT selector is active |
| FFWD | next MZT record while the MZT selector is active |

## 4.3 RECORD screen

| Button | Action |
|---|---|
| PLAY | start manually when armed, or pause/resume an active recording |
| STOP short | finish and save |
| STOP long | cancel recording; if a capture file has already been created it is deleted |

> **Important:** long STOP while recording is **Cancel**, not normal Stop/Save.

---

# 5. Understanding the 16×2 LCD

The display has only sixteen characters per line, so several compact abbreviations are used.

This chapter is deliberately detailed. Once the display conventions are understood, diagnosing playback and recording becomes much easier.

---

## 5.1 The graphical buffer column

During active PLAY or RECORD, the **last LCD column** is normally reserved for a custom vertical bar character.

In the text examples in this handbook it is represented as:

```text
▁  low
▃
▅
▇
█  high
```

The real HD44780 LCD uses a custom vertical-fill character rather than these Unicode blocks.

### The important rule

**A high bar is healthy. A very low bar deserves attention.**

The internal meaning differs between PLAY and RECORD:

- during **PLAY**, the bar represents how much source data is already buffered and ready for output;
- during **RECORD**, it represents **buffer headroom** – how much safe free capacity remains.

This difference is explained in detail in [Understanding the buffer indicator](#15-understanding-the-buffer-indicator).

---

## 5.2 Browser display

At the root directory:

```text
+----------------+
|/           1/42|
|GAMES           |
+----------------+
```

Inside a directory:

```text
+----------------+
|../GAMES    3/28|
|PACMAN.MZF      |
+----------------+
```

### Browser line 1

The first line contains:

- `/` at root, or `../` inside a directory;
- the current directory name when space permits;
- position `current/total` at the right.

For example:

```text
3/28
```

means third visible item out of 28.

The browser is alphabetically sorted.

### `I` instead of `/` in the counter

If the highlighted MZF or MZT has matching playback metadata, the separator changes.

Normal:

```text
3/28
```

Metadata available:

```text
3I28
```

The `I` means an information sidecar exists:

- `.MFI` for an `.MZF`
- `.MTI` for an `.MZT`

Example:

```text
+----------------+
|../GAMES    3I28|
|PACMAN.MZF      |
+----------------+
```

The metadata files themselves are hidden from normal browsing.

---

## 5.3 Browser status screens

### SD card removed

```text
+----------------+
|INSERT CARD     |
|                |
+----------------+
```

### SD card error

```text
+----------------+
|SD CARD ERROR   |
|RECORD=RETRY    |
+----------------+
```

Press **RECORD** to retry SD initialization.

### Reinitializing

```text
+----------------+
|SD INIT         |
|                |
+----------------+
```

### Empty directory

```text
+----------------+
|../EMPTY     0/0|
|EMPTY           |
+----------------+
```

### Name too long

```text
+----------------+
|NAME TOO LONG   |
|                |
+----------------+
```

### Path too long

```text
+----------------+
|PATH TOO LONG   |
|                |
+----------------+
```

---

## 5.4 Standard PLAY display

Example:

```text
+----------------+
|PACMAN.MZF     █|
|PLY 00:12/01:42 |
+----------------+
```

### Line 1

The first fifteen columns contain the filename. Long names scroll horizontally.

The final column is the playback buffer bar.

### Line 2

`PLY` = actively playing.

```text
PLY 00:12/01:42
```

means:

- `PLY` – playback active
- `00:12` – 12 seconds elapsed
- `/`
- `01:42` – nominal total time 1 minute 42 seconds

---

## 5.5 `RDY`, `PLY`, `PLA`, `PAU`, `ERR`

The PLAY screen can use the following state abbreviations:

| Display | Meaning |
|---|---|
| `RDY` | source prepared / ready |
| `PLY` | playing |
| `PLA` | playing using loader information selected automatically from MFI/MTI metadata |
| `PAU` | paused |
| `ERR` | playback error |

`PLA` is useful because it confirms that **AUTO** actually selected the loader profile from the information sidecar rather than merely falling back to a default.

Example:

```text
+----------------+
|MFI PACMAN.MZF █|
|PLA 00:04/00:31 |
+----------------+
```

The `MFI` prefix shows that the MZF loader profile is being taken from the matching `.MFI`.

---

## 5.6 User pause and MOTOR pause

The **last character of line 2** may indicate why playback is paused.

### User pause

```text
+----------------+
|PACMAN.MZF     █|
|PAU 00:17/01:42U|
+----------------+
```

`U` = **User pause**.

The user pressed PLAY to pause the stream.

### MOTOR pause

```text
+----------------+
|PACMAN.MZF     █|
|PAU 00:17/01:42M|
+----------------+
```

`M` = **Motor pause**.

The Sharp computer lowered the MOTOR signal and MZ-SD2CMT2 paused automatically.

### Waiting for MOTOR before playback begins

```text
+----------------+
|PACMAN.MZF     █|
|PAUSED         M|
+----------------+
```

This is not an error. The file is prepared and MZ-SD2CMT2 is waiting for the computer.

---

## 5.7 Manual override of a MOTOR pause

In MOTOR mode, an active stream normally follows the Sharp MOTOR signal.

If playback has already been paused because MOTOR went LOW, pressing **PLAY** is an explicit user override and resumes playback even while MOTOR is still LOW.

The override lasts until MOTOR goes HIGH again. After that, normal MOTOR control is re-armed and the next LOW will pause the stream again.

This is useful for testing and unusual software, but normal users can simply let the computer control the transport.

---

## 5.8 Percentage PLAY display

Formats for which an exact nominal time is not the most useful representation use a percentage.

Example:

```text
+----------------+
|PROGRAM.L16    █|
|PLY        045% |
+----------------+
```

The percentage shows progress through the current source.

---

## 5.9 Turbo/Ultra-Fast phase display

Some generated Sharp tape profiles expose an internal phase label.

Example:

```text
+----------------+
|GAME.MZF       █|
|PLY UL     063% |
+----------------+
```

The three-character phase field is diagnostic. It shows which portion of a multi-stage loader is currently being sent.

Possible phase labels include:

| Phase | Meaning |
|---|---|
| `NLL` | Ultra-Fast bootstrap/normal-loader phase using LOW placement |
| `NLH` | Ultra-Fast bootstrap/normal-loader phase using HIGH placement |
| `HLL` | Ultra-Fast header phase using LOW placement |
| `HLH` | Ultra-Fast header phase using HIGH placement |
| `U7L` | MZ-700 Ultra-Fast loader phase, LOW placement |
| `U7H` | MZ-700 Ultra-Fast loader phase, HIGH placement |
| `ICL` | IC turbo loader stage |
| `IC` | IC turbo data stage |
| `TC` | Turbo Copy loader/data stage |
| `F3L` | MZ-700 FAST3 stage, LOW placement |
| `F3H` | MZ-700 FAST3 stage, HIGH placement |
| `UL` | Ultra-Fast handshake/data stage |

These abbreviations are intended mainly as diagnostics. A normal user does not need to react to them.

---

## 5.10 MZT selector display

Opening an MZT does **not** immediately begin record 1. It first opens a small record selector.

Example without MTI metadata:

```text
+----------------+
|2/5 PACMAN     █|
|SEL N13 01:27   |
+----------------+
```

Meaning:

- `2/5` – record 2 of 5
- `PACMAN` – title from that record's MZF header
- `SEL` – AUTO mode, but no MTI profile is being applied
- `N13` – NORMAL 1:3 for this record
- `01:27` – nominal duration

### MZT with MTI metadata

```text
+----------------+
|2I5 PACMAN     █|
|MTI N13 01:27   |
+----------------+
```

`I` and `MTI` confirm that the record has been resolved using the `.MTI` sidecar.

### Manually forced loader

```text
+----------------+
|2I5 PACMAN     █|
|MAN TC3 00:36   |
+----------------+
```

`MAN` means the user selected a loader manually in PLAY settings, so the manual setting has priority over MTI.

### Duration not known

Ultra Fast payload timing is handshake-driven and may not have a predictable duration.

```text
+----------------+
|2I5 PACMAN     █|
|MTI UL   --:--  |
+----------------+
```

---

## 5.11 Compact loader labels used by MZT

| LCD | Loader |
|---|---|
| `N11` | NORMAL 1:1 |
| `N12` | NORMAL 1:2 |
| `N13` | NORMAL 1:3 |
| `N14` | NORMAL 1:4 |
| `M71` | MZ700 1:1 |
| `M73` | MZ700 FAST3 / 1:3 |
| `IC2` | IC 1:2 |
| `IC3` | IC 1:3 |
| `IC4` | IC 1:4 |
| `TC2` | Turbo Copy 1:2 |
| `TC3` | Turbo Copy 1:3 |
| `TC4` | Turbo Copy 1:4 |
| `UL` | classic Ultra Fast |
| `UL8` | Ultra Fast forced for MZ-800 |
| `UL7` | Ultra Fast forced for MZ-700 |

---

## 5.12 Basic RECORD display

WAV example:

```text
+----------------+
|REC0001.WAV 44k█|
|REC 00:12       |
+----------------+
```

Line 1 contains:

- provisional filename
- WAV sample-rate abbreviation
- buffer-headroom bar in the last column

`44k` means 44.1 kHz mode.

At 22.05 kHz:

```text
+----------------+
|REC0001.WAV 22k█|
|REC 00:12       |
+----------------+
```

For LEP, L16 or MZF the sample-rate suffix is not used.

---

## 5.13 RECORD armed states

### MOTOR mode, waiting for MOTOR

```text
+----------------+
|REC0001.MZF    █|
|PAUSED         M|
+----------------+
```
`M` means waiting on the Sharp MOTOR signal.

### AUTO mode, waiting for the first signal activity

```text
+----------------+
|REC0001.WAV 44k█|
|WAIT SIGNAL     |
+----------------+
```

No file capture begins until signal activity is detected.

---

## 5.14 RECORD pause indicators

### User pause

```text
+----------------+
|REC0001.L16    █|
|PAU 00:24      U|
+----------------+
```

`U` = paused by the user.

### Motor pause

```text
+----------------+
|REC0001.L16    █|
|PAU 00:24      M|
+----------------+
```

`M` = paused because MOTOR is LOW.

A user pause has priority over MOTOR. If the user pauses recording manually, a later MOTOR HIGH does not silently resume it.

---

## 5.15 Detected profile and payload progress

When AutoName/profile detection has recognized a tape format and the payload length is known, the second line changes from elapsed time to profile + progress.

Example:

```text
+----------------+
|PACMAN         █|
|REC NRL 1:2 45% |
+----------------+
```

When paused:

```text
+----------------+
|PACMAN         █|
|PAU NRL 1:2 45%M|
+----------------+
```

The positions are fixed:

```text
columns: 1234567890123456
         REC NRL 1:2 45% 
         PAU NRL 1:2 45%M
```

The final column is reserved for `M`, `U` or another pause reason.

### Important: 100% does not necessarily mean recording has stopped

Example:

```text
+----------------+
|PACMAN         █|
|REC NRL 1:2 100%|
+----------------+
```

`100%` means the **declared detected payload length has been received**.

It does **not** necessarily mean the recorder has finished:

- MANUAL recording may continue;
- AUTO recording may still be keeping the five-second idle tail;
- the system may still be finalizing the file.

To avoid confusion, `REC` blinks after detected payload progress reaches 100% while the engine is still genuinely recording.

---

## 5.16 Detected record-profile abbreviations

| LCD | Meaning |
|---|---|
| `NRL 1:1` | detected normal Sharp MZ tape at 1:1 |
| `NRL 1:2` | detected normal Sharp MZ tape at 1:2 |
| `NRL 1:3` | detected normal Sharp MZ tape at 1:3 |
| `NRL 1:4` | detected normal Sharp MZ tape at 1:4 |
| `MZ7 1:1` | detected MZ-700 profile 1:1 |
| `MZ7 1:3` | detected MZ-700 FAST3 profile |
| `IC 1:2` etc. | detected IC/InterCopy-family profile |
| `TC 1:2` etc. | detected Turbo Copy profile |
| `SIN 1:x` | detected Sinclair-style auxiliary tape profile |
| `CPM 1:x` | detected CP/M/CMT-style auxiliary profile |

The detected profile is informational and also helps MZ-SD2CMT2 preserve the intended playback characteristics when appropriate.

---

## 5.17 Saving and saved screens

While the file is being finalized:

```text
+----------------+
|SAVING PACMAN   |
|NRL 1:2     WAIT|
+----------------+
```

or, when no profile was detected:

```text
+----------------+
|SAVING REC0001  |
|PLEASE WAIT     |
+----------------+
```

After a successful save:

```text
+----------------+
|SVD PACMAN.MZF  |
|NRL 1:2         |
+----------------+
```

Long filenames scroll while the fixed `SAVING ` or `SVD ` prefix remains visible.

---

## 5.18 Cancel screens

If recording had already created a file and long STOP cancels it:

```text
+----------------+
|FILE DELETED    |
|                |
+----------------+
```

If recording was cancelled before a capture file existed:

```text
+----------------+
|REC CANCELLED   |
|                |
+----------------+
```

---

## 5.19 Record error

```text
+----------------+
|REC ERROR       |
|MZF OVERFLOW    |
+----------------+
```

The second line contains the specific error when available.

---

# 6. Using the SD-card browser

The browser displays only user-relevant media entries. Playback metadata such as `.MFI` and `.MTI` is hidden.

## 6.1 Moving through entries

- REWIND = previous
- FFWD = next
- holding either button repeats
- moving past the first/last entry wraps around

The browser inserts a short pause before wrapping during repeated scrolling so that holding the button does not immediately run through the end of the list.

## 6.2 Entering and leaving directories

Press PLAY on a directory to enter it.

Press STOP briefly to go to the parent.

Press STOP long in a subdirectory to return directly to root.

At root, long STOP opens SYSTEM settings.

## 6.3 Long filenames

Long names scroll after a short hold.

The current directory name can also scroll independently on line 1.

## 6.4 SD card removal and reinsertion

The dedicated hardware can detect media removal.

If the card is removed:

```text
INSERT CARD
```

is shown.

During active PLAY, media removal aborts the stream safely. Reinserting the card causes reinitialization; MZT attempts to return to the previously prepared record selector, while a normal file is prepared again rather than blindly resumed from a stale buffer.

---

# 7. Supported file formats

| Format | Play | Record | Purpose |
|---|---:|---:|---|
| **MZF** | yes | yes | canonical Sharp MZ single-file image |
| **MZT** | yes | no | container with multiple logical MZF records |
| **M12** | yes | no | Sharp tape-format variant supported by playback |
| **WAV** | yes | yes | sampled physical tape waveform |
| **LEP** | yes | yes | compact pulse-duration representation, 50 µs unit |
| **L16** | yes | yes | finer pulse-duration representation, 16 µs unit |
| **TAP** | yes | no | ZX Spectrum TAP playback |

## 7.1 MZF

Best choice for ordinary Sharp software when a clean logical program image is available.

Advantages:

- small
- fast to browse
- can use generated loader/timing profiles
- supports MFI metadata
- can be recorded directly from a valid Sharp tape stream

## 7.2 MZT

A virtual multi-record tape.

An MZT may contain several logical MZF records. MZ-SD2CMT2 presents them through a mini-browser and can apply a different MTI loader profile to each record.

## 7.3 WAV

Stores a sampled representation of the tape signal.

WAV is useful for:

- compatibility with audio tools
- preserving a signal-like representation
- archiving
- analysis

MZ-SD2CMT2 records mono WAV at either:

- 44.1 kHz
- 22.05 kHz

### Hardware-speed limitation

> **Important:** WAV recording with AutoName / live metadata recognition is supported only up to approximately the **1:2** tape-speed profile because of the ATmega2560 real-time processing and buffering limits.
>
> Do not rely on WAV + AutoName/profile recognition for 1:3 or 1:4 signals. For faster signals use a more suitable direct/edge-oriented recording path where possible.

This limitation should be considered a design boundary, not an SD-card formatting problem.

## 7.4 LEP

Pulse-duration format using a 50 µs unit.

Good when a pulse representation is preferred over a sampled WAV while retaining physical tape timing.

## 7.5 L16

Pulse-duration format using a 16 µs unit.

L16 provides finer timing resolution than LEP and is a useful archival/intermediate format for fast or timing-sensitive tape signals.

## 7.6 TAP

ZX Spectrum TAP playback is supported with selectable bit rates:

- 1400 Bd
- 1800 Bd
- 2100 Bd
- 2500 Bd

TAP speed is independent from the Sharp loader SPEED setting.

---

# 8. Playing files

## 8.1 Select a file

Browse to the file and press PLAY.

MZ-SD2CMT2 detects the format from the extension.

Unknown extensions show:

```text
UNSUPPORTED
```

## 8.2 MOTOR playback

Default mode:

```text
PLAY CTRL
MOTOR
```

MZ-SD2CMT2 follows the Sharp MOTOR signal.

This is the most cassette-like behaviour and the recommended default.

## 8.3 MANUAL playback

```text
PLAY CTRL
MANUAL
```

The source starts immediately when selected/confirmed.

The Sharp MOTOR signal does not automatically control playback.

Use this for:

- diagnostics
- software with unusual MOTOR behaviour
- non-Sharp targets
- testing generated signals

## 8.4 Pause/resume

PLAY toggles pause/resume.

The reason is shown by:

- `U` – user
- `M` – motor

## 8.5 End of file

End of file leaves the source ready rather than automatically looping forever.

A later PLAY can re-prepare and start the source again.

---

# 9. PLAY settings

From the browser, **long PLAY** opens the PLAY menu.

Use:

- FFWD / REWIND to move through settings
- PLAY to change the selected setting
- STOP to return

Settings are stored persistently.

---

## 9.1 WAV INVERT

```text
+----------------+
|>WAV INVERT     |
| ON             |
+----------------+
```

or

```text
+----------------+
|>WAV INVERT     |
| OFF            |
+----------------+
```

This compensates the polarity of a WAV source when required.

It applies to WAV input/playback interpretation. Generated Sharp MZF/MZT signals use loader-defined polarity and do not use this setting.

---

## 9.2 PLAY CTRL

```text
+----------------+
|>PLAY CTRL      |
| MOTOR          |
+----------------+
```

or:

```text
+----------------+
|>PLAY CTRL      |
| MANUAL         |
+----------------+
```

Recommended default: **MOTOR**.

---

## 9.3 LOADER

Available choices:

```text
NORMAL
AUTO
UL
UL MZ800
UL MZ700
MZ700
IC
TC
```

The next chapter explains them.

---

## 9.4 SPEED

The available SPEED choices depend on the selected loader.

NORMAL:

```text
1:1
1:2
1:3
1:4
```

MZ700:

```text
1:1
1:3
```

IC:

```text
1:2
1:3
1:4
```

TC:

```text
1:2
1:3
1:4
```

AUTO and UL variants do not expose a manual SPEED value and show `--`.

The firmware remembers a separate last-used speed for NORMAL, MZ700, IC and TC.

---

## 9.5 TAP SPEED

```text
+----------------+
|>TAP SPEED      |
| 1400 Bd        |
+----------------+
```

Cycles through:

- 1400 Bd
- 1800 Bd
- 2100 Bd
- 2500 Bd

Only TAP playback uses this value.

---

# 10. Loader modes and speed profiles

## 10.1 Understanding `1:1`, `1:2`, `1:3`, `1:4`

`1:1` is the baseline timing profile.

The faster profiles represent progressively shorter tape timings:

- `1:2` ≈ faster transfer profile
- `1:3` ≈ still faster
- `1:4` ≈ fastest of the listed normal/turbo timing ratios

The exact waveform is defined by the selected loader family; the ratio is a convenient user-facing label, not a promise that every program takes exactly one-half, one-third or one-quarter of the original wall-clock time.

---

## 10.2 NORMAL

The standard Sharp-style generated tape profile.

Use NORMAL when:

- maximum compatibility is wanted
- you know which standard timing the target loader accepts
- diagnosing a file that fails under a turbo profile

Start with:

```text
NORMAL 1:1
```

and only increase speed when you know the receiving loader supports it.

---

## 10.3 AUTO

AUTO is the recommended advanced default when a library contains matching metadata.

For MZF:

1. look for same-basename `.MFI`;
2. if valid, use its loader/profile;
3. if missing or invalid, fall back to NORMAL 1:1.

For MZT:

1. look for same-basename `.MTI`;
2. resolve the selected record independently;
3. missing/invalid record metadata falls back to NORMAL 1:1 for that record.

A manually selected loader always wins over metadata.

---

## 10.4 UL – Ultra Fast

UL uses the MZ-SD2CMT-style Ultra Fast transfer mechanism for compatible MZF data.

Unlike ordinary cassette timing, the high-speed payload uses the live CMT handshake and therefore its duration is not represented as a normal fixed tape time.

Use UL when:

- the file is compatible;
- very fast loading is wanted;
- you understand that the transfer behaviour differs from a normal physical tape.

The generic UL mode automatically determines appropriate LOW/HIGH placement where possible.

---

## 10.5 UL MZ800

Forces the Ultra Fast profile appropriate to the MZ-800 path.

LCD compact form:

```text
UL8
```

Use when the automatic/general UL selection needs to be constrained specifically for MZ-800 behaviour.

---

## 10.6 UL MZ700

Forces the MZ-700 Ultra Fast profile.

LCD compact form:

```text
UL7
```

---

## 10.7 MZ700

MZ-700 profile.

Available speeds:

- 1:1
- 1:3 FAST3

Compact LCD labels:

```text
M71
M73
```

---

## 10.8 IC

IC/InterCopy-family turbo profiles.

Available speeds:

- 1:2
- 1:3
- 1:4

Compact labels:

```text
IC2
IC3
IC4
```

---

## 10.9 TC

Turbo Copy profiles.

Available speeds:

- 1:2
- 1:3
- 1:4

Compact labels:

```text
TC2
TC3
TC4
```

---

## 10.10 Loader abbreviations – what do UL, UL8, UL7, N13, IC3… mean?

The 16×2 LCD cannot show long loader names all the time, so the firmware uses compact labels.

It is useful to distinguish **three different spellings of the same function**:

1. the human-readable PLAY menu name;
2. the keyword used in an MFI/MTI sidecar;
3. the compact label used on the LCD.

| Function | PLAY menu | MFI / MTI | LCD |
|---|---|---|---|
| Normal MZ timing 1:1 | `NORMAL` + `1:1` | `TYPE=NORMAL` + `SPEED=1:1` | `N11` |
| Normal MZ timing 1:2 | `NORMAL` + `1:2` | `TYPE=NORMAL` + `SPEED=1:2` | `N12` |
| Normal MZ timing 1:3 | `NORMAL` + `1:3` | `TYPE=NORMAL` + `SPEED=1:3` | `N13` |
| Normal MZ timing 1:4 | `NORMAL` + `1:4` | `TYPE=NORMAL` + `SPEED=1:4` | `N14` |
| MZ-700 normal | `MZ700` + `1:1` | `TYPE=MZ700` + `SPEED=1:1` | `M71` |
| MZ-700 FAST3 | `MZ700` + `1:3` | `TYPE=MZ700` + `SPEED=1:3` | `M73` |
| InterCopy-family 1:2 | `IC` + `1:2` | `TYPE=IC` + `SPEED=1:2` | `IC2` |
| InterCopy-family 1:3 | `IC` + `1:3` | `TYPE=IC` + `SPEED=1:3` | `IC3` |
| InterCopy-family 1:4 | `IC` + `1:4` | `TYPE=IC` + `SPEED=1:4` | `IC4` |
| Turbo Copy 1:2 | `TC` + `1:2` | `TYPE=TC` + `SPEED=1:2` | `TC2` |
| Turbo Copy 1:3 | `TC` + `1:3` | `TYPE=TC` + `SPEED=1:3` | `TC3` |
| Turbo Copy 1:4 | `TC` + `1:4` | `TYPE=TC` + `SPEED=1:4` | `TC4` |
| Ultra Fast, automatic target/placement | `UL` | `TYPE=UL` | `UL` |
| Ultra Fast for MZ-800 | `UL MZ800` | `TYPE=UL_MZ800` | `UL8` |
| Ultra Fast for MZ-700 | `UL MZ700` | `TYPE=UL_MZ700` | `UL7` |

### `UL`

`UL` is the firmware shorthand for the **Ultra Fast loader/transfer path**.
It is not simply “NORMAL at a still higher ratio”. A normal or turbo tape profile still generates a timing-based tape waveform. Ultra Fast changes the transfer method and uses the live CMT WRITE/SENSE handshake for the fast payload.

Because the payload transfer is handshake-driven, its exact duration cannot be calculated in the same way as a normal generated tape. This is why an MZT selector can show:

```text
MTI UL   --:--
```

instead of a normal duration.

### `UL8` / `UL MZ800` / `UL_MZ800`

These three labels refer to the same MZ-800-specific Ultra Fast choice:

```text
PLAY menu:  UL MZ800
sidecar:    TYPE=UL_MZ800
LCD:        UL8
```

If older notes or users informally call this **UL800**, the current firmware spelling should still be used in files: `UL_MZ800`.

`UL8` does **not** mean “Ultra Fast speed 1:8”. The `8` identifies the **MZ-800 target**, not a speed ratio.

### `UL7` / `UL MZ700` / `UL_MZ700`

Likewise:

```text
PLAY menu:  UL MZ700
sidecar:    TYPE=UL_MZ700
LCD:        UL7
```

The `7` identifies the MZ-700 target. It is not a 1:7 speed.

### `N11` … `N14`

`N` means **NORMAL** and the two following digits encode the displayed speed:

```text
N11 = NORMAL 1:1
N12 = NORMAL 1:2
N13 = NORMAL 1:3
N14 = NORMAL 1:4
```

### `M71` and `M73`

`M7` identifies the **MZ-700** timing family:

```text
M71 = MZ700 1:1
M73 = MZ700 1:3 / FAST3
```

### `IC2`, `IC3`, `IC4`

`IC` identifies the **InterCopy-family** turbo profile.

The last digit is the selected ratio:

```text
IC2 = IC 1:2
IC3 = IC 1:3
IC4 = IC 1:4
```

### `TC2`, `TC3`, `TC4`

`TC` means **Turbo Copy**.

Again, the final digit is the speed profile:

```text
TC2 = TC 1:2
TC3 = TC 1:3
TC4 = TC 1:4
```

### Do not confuse loader labels with RECORD detection labels

During recording you may see labels such as:

```text
NRL 1:3
MZ7 1:3
IC 1:3
TC 1:3
```

These describe what the recorder **detected in the incoming signal**.

During MZT selection you instead see compact playback choices such as:

```text
N13
M73
IC3
TC3
UL8
```

One is a detection/status display; the other is a playback-loader selection.

---

## 10.11 Which loader should I choose?

| Situation | Recommended |
|---|---|
| I do not know | `NORMAL 1:1` for safety, or `AUTO` when metadata is available |
| I want the most compatible normal load | `NORMAL 1:1` |
| My library includes correct MFI/MTI | `AUTO` |
| I want maximum speed and know the MZF is UL-compatible | `UL` |
| I specifically need MZ-800 UL | `UL MZ800` / `UL8` |
| I specifically need MZ-700 UL | `UL MZ700` / `UL7` |
| I have a known MZ700 FAST3 image/profile | `MZ700 1:3` / `M73` |
| I know the file expects an IC profile | `IC` + correct speed |
| I know the file expects Turbo Copy | `TC` + correct speed |

If a fast mode fails, go back to a slower/more compatible profile before suspecting SD-card corruption.

---

# 11. MFI and MTI metadata

Earlier development discussions used the generic name **MZI**, and the internal firmware module is still named `mzi_sidecar.*`.

The **current external file formats are explicitly MFI and MTI**:

```text
GAME.MZF  -> GAME.MFI
TAPE.MZT  -> TAPE.MTI
```

> There is **no `.MZI` fallback** in the current format. `.MZI` is not read or written.

---

## 11.1 MFI – metadata for one MZF

Example:

```ini
TYPE=NORMAL
SPEED=1:3
```

Ultra Fast example:

```ini
TYPE=UL_MZ800
```

MFI is used only when PLAY loader selection is `AUTO`.

If the user selects `TC`, `IC`, `UL`, `NORMAL`, etc. manually, that manual selection has priority.

---

## 11.2 MTI – metadata for records inside an MZT

Example:

```ini
RECORD=1
TYPE=NORMAL
SPEED=1:3

RECORD=2
TYPE=UL

RECORD=3
TYPE=UL_MZ800

RECORD=4
TYPE=UL_MZ700

RECORD=5
TYPE=MZ700
SPEED=1:3
```

Each logical record can therefore have a different playback method.

---

## 11.3 Supported metadata combinations

| TYPE | SPEED |
|---|---|
| `NORMAL` | `1:1`, `1:2`, `1:3`, `1:4` |
| `MZ700` | `1:1`, `1:3` |
| `IC` | `1:2`, `1:3`, `1:4` |
| `TC` | `1:2`, `1:3`, `1:4` |
| `UL` | no SPEED |
| `UL_MZ800` | no SPEED |
| `UL_MZ700` | no SPEED |

Both LF and CRLF line endings are accepted.

TYPE matching is case-insensitive.

---

## 11.4 Why use metadata instead of renaming/converting the MZF?

The MZF remains the canonical program image.

Metadata tells MZ-SD2CMT2 **how to present that file to the computer**.

This is useful when:

- you want to preserve an original MZF unchanged;
- one program works best with a specific loader;
- you want AUTO to select the correct speed without remembering it;
- an MZT contains records that need different loaders;
- a multi-part game uses several tape blocks with different timing/loader requirements;
- you want to distribute one clean MZF/MZT library together with small playback instructions rather than modified copies of the program data.

The sidecar is therefore **playback policy**, not program data.

---

## 11.5 How AUTO actually uses the sidecar

The important rule is:

> **MFI/MTI is consulted only when PLAY `LOADER = AUTO`.**

### MZF

For:

```text
GAME.MZF
GAME.MFI
```

the sequence is:

```text
select GAME.MZF
       |
       v
PLAY LOADER = AUTO ?
       |
       +-- no --> use the manually selected loader
       |
       +-- yes
             |
             v
       GAME.MFI exists and is valid ?
             |
             +-- yes --> use TYPE/SPEED from GAME.MFI
             |
             +-- no  --> NORMAL 1:1
```

A manual loader selection always has priority.

For example, even if `GAME.MFI` says:

```ini
TYPE=UL_MZ800
```

selecting `TC 1:3` manually in the PLAY menu makes the session use TC 1:3.

### MZT

For:

```text
GAME.MZT
GAME.MTI
```

the logic is applied **independently to every selected logical MZT record**.

For example, record 1 can be NORMAL 1:1, record 2 UL MZ800 and record 3 TC 1:3.

If metadata for one particular record is missing or invalid, only that record falls back to NORMAL 1:1. Other records are resolved again from their own MTI sections.

---

## 11.6 MFI sidecars for a multi-part game stored as separate MZF files

A multi-part game does not have to be packed into one MZT.

A directory may contain:

```text
GAME_BOOT.MZF
GAME_BOOT.MFI

GAME_PART1.MZF
GAME_PART1.MFI

GAME_PART2.MZF
GAME_PART2.MFI

GAME_PART3.MZF
GAME_PART3.MFI
```

Each MZF can have its own playback policy.

Example:

`GAME_BOOT.MFI`

```ini
TYPE=NORMAL
SPEED=1:1
```

`GAME_PART1.MFI`

```ini
TYPE=TC
SPEED=1:3
```

`GAME_PART2.MFI`

```ini
TYPE=TC
SPEED=1:3
```

`GAME_PART3.MFI`

```ini
TYPE=UL_MZ800
```

With `LOADER=AUTO`, the user does not need to remember which part needs which loader. Selecting each MZF is enough.

This arrangement is useful when:

- the parts are naturally distributed as separate MZF files;
- the user wants to choose parts manually from folders;
- different editions or language versions share some parts;
- preserving each original MZF as an individual library object is preferred.

---

## 11.7 MTI sidecars for a multi-part game stored as one MZT

MZT is especially useful when a game originally consisted of several tape blocks that belong together.

Instead of:

```text
BOOT.MZF
PART1.MZF
PART2.MZF
PART3.MZF
```

they can be distributed as:

```text
GAME.MZT
GAME.MTI
```

The MZT keeps the logical records together and the MTI describes how each one should be played.

Example:

```ini
RECORD=1
TYPE=NORMAL
SPEED=1:1

RECORD=2
TYPE=TC
SPEED=1:3

RECORD=3
TYPE=TC
SPEED=1:3

RECORD=4
TYPE=UL_MZ800
```

In this example:

- record 1 is the initial bootstrap/loader and is played conservatively as NORMAL 1:1;
- records 2 and 3 are assigned to Turbo Copy 1:3;
- record 4 uses the MZ-800 Ultra Fast path.

The actual choices depend on the game and its loader. The example demonstrates that **one MZT is not forced to use one global speed**.

That is the main advantage of MTI for multi-part software.

---

## 11.8 Why per-record metadata matters for multi-part games

Many cassette programs are not one uninterrupted byte stream.

A game can contain, for example:

```text
record 1  bootstrap / loader
record 2  main program
record 3  level or data block
record 4  next level
record 5  additional data
```

The loader used by the first part does not necessarily describe the later parts.

MTI solves this by binding the playback profile to the **logical record number**:

```text
MZT record 1 -> profile A
MZT record 2 -> profile B
MZT record 3 -> profile B
MZT record 4 -> profile C
...
```

This allows the MZT to behave much more like the original multi-part cassette while still taking advantage of faster generated loaders where they are appropriate.

---

## 11.9 Sidecars do not modify the program image

This is an important design property.

For MZF:

```text
GAME.MZF
```

remains unchanged whether or not:

```text
GAME.MFI
```

exists.

For MZT:

```text
GAME.MZT
```

also remains unchanged when:

```text
GAME.MTI
```

is added, edited or removed.

This has several benefits:

- checksums/hashes of the original MZF/MZT remain stable;
- metadata can be corrected without rebuilding the image;
- users can experiment with loader profiles safely;
- the same program image can be preserved as the canonical archival copy.

---

## 11.10 Naming rules

The sidecar must use the same basename:

```text
PACMAN.MZF
PACMAN.MFI
```

and:

```text
MULTIPART.MZT
MULTIPART.MTI
```

Not:

```text
PACMAN.MZF
PACMAN_INFO.MFI
```

The sidecar files are hidden from the normal browser and do not increase the displayed `N/N` entry count.

---

## 11.11 Practical workflow for building a sidecar

For one MZF:

1. verify which loader/profile successfully loads the program;
2. create `same-name.MFI`;
3. write the working TYPE and SPEED;
4. set PLAY `LOADER=AUTO`;
5. reselect the MZF;
6. verify that the PLAY screen shows `MFI`/`PLA`.

For MZT:

1. open the MZT selector;
2. note the logical record numbers and titles;
3. determine the correct loader for each relevant record;
4. create one `same-name.MTI`;
5. add one `RECORD=n` section for each record that needs an explicit profile;
6. set PLAY `LOADER=AUTO`;
7. verify `MTI` in the selector for the resolved records.

A good MTI can therefore turn a complex multi-part tape into a file the user can simply select and use, without remembering a loader table.

---

# 12. MZT multi-record tapes

MZT is treated as a virtual tape containing multiple logical MZF records.

## 12.1 Opening an MZT

Selecting an MZT opens the record selector.

Example:

```text
+----------------+
|1I4 LOADER     █|
|MTI N11 00:23   |
+----------------+
```

Use:

- REWIND = previous record
- FFWD = next record
- PLAY = confirm/start
- STOP = return to browser

The selector wraps from first to last and last to first.

---

## 12.2 During MZT playback

The first line keeps the current logical record index and title visible.

Example:

```text
+----------------+
|3I4 GAME       █|
|PLA 00:15/01:05 |
+----------------+
```

When the active MZT record changes, its elapsed time resets to `00:00` and its own nominal duration becomes the total.

---

## 12.3 STOP hierarchy inside MZT

STOP has two levels:

```text
active MZT playback
        ↓ STOP
MZT record selector
        ↓ STOP
main SD browser
```

This makes it easy to stop record 3 and immediately choose record 2 or 4 without reopening the entire MZT.

---

## 12.4 End of an MZT record

At the end of the selected run the interface returns to the MZT selector instead of silently looping back to record 1.

---

## 12.5 Ultra Fast records in MZT

Ultra Fast records represent independent LOAD operations.

A completed UL payload returns control to the loaded program, so the next logical MZT record must not be injected automatically as though the Z80 were still waiting for tape data.

When another record follows UL/UL8/UL7:

- MOTOR mode requires a real LOW → HIGH MOTOR cycle before the next record starts;
- MANUAL mode requires a new PLAY confirmation.

This behaviour is particularly important for multi-part games. It prevents the next level/data record from being sent immediately after an Ultra Fast part if the running program has not requested that next LOAD yet.

---

## 12.6 MZT as a multi-part game container

For a multi-part game, think of an MZT as a **virtual cassette with indexed logical files** rather than one large MZF.

Example:

```text
GAME.MZT
  record 1  BOOT
  record 2  GAME
  record 3  LEVEL1
  record 4  LEVEL2
  record 5  LEVEL3
```

The matching:

```text
GAME.MTI
```

can then specify the appropriate loader for each logical part.

Example:

```ini
RECORD=1
TYPE=NORMAL
SPEED=1:1

RECORD=2
TYPE=IC
SPEED=1:3

RECORD=3
TYPE=UL_MZ800

RECORD=4
TYPE=UL_MZ800

RECORD=5
TYPE=UL_MZ800
```

This is only an example; the real loader assignments must match the particular game's tape format.

### Why this is useful

Without MTI, a user would have to remember something like:

```text
boot     -> NORMAL 1:1
game     -> IC 1:3
levels   -> UL MZ800
```

and manually change PLAY settings at the correct moments.

With MTI and `LOADER=AUTO`, that knowledge travels with the game.

The device resolves the selected MZT record and presents the corresponding profile automatically.

---

## 12.7 Multi-part games: MFI set or MZT+MTI?

Both approaches are valid.

### Separate MZF + MFI

Use when you want:

- every part to remain a separate file;
- manual selection of individual parts;
- a simple library structure;
- easy replacement of one part without rebuilding a container.

Example:

```text
GAME/
  BOOT.MZF
  BOOT.MFI
  PART1.MZF
  PART1.MFI
  PART2.MZF
  PART2.MFI
```

### MZT + MTI

Use when you want:
- all parts of one cassette/game kept together;
- logical record order preserved;
- one visible game file in the browser;
- per-record loader selection;
- a closer representation of a multi-file original tape.

Example:

```text
GAME.MZT
GAME.MTI
```

For a carefully prepared game library, **MZT + MTI is usually the cleaner presentation for a true multi-record cassette**, while separate MZF + MFI remains convenient when the parts are normally handled independently.

---

## 12.8 Important multi-part limitation: metadata chooses playback, not game logic

MTI knows:

- which MZT logical record is selected;
- which loader/profile should be used for it.

It does **not** understand the internal game state.

It cannot know that:

- the player has reached level 4;
- the program now wants side B;
- a particular data block should be skipped;
- the software expects a completely different tape.

The program running on the Sharp still determines **when another LOAD is requested**.

MZ-SD2CMT2 supplies the correct virtual-tape record and playback profile; it does not replace the game's own loading logic.

---

# 13. Recording

From the browser:

- short RECORD starts recording with the current settings;
- long RECORD opens RECORD settings.

All recordings are stored in:

```text
/RECORDINGS
```

The directory is handled automatically by the recording workflow.

---

## 13.1 RECORD settings

The menu contains:

```text
REC TYPE
REC MODE
AUTONAME
```

Use FFWD/REWIND to select a setting, PLAY to change it and STOP to return.

The settings are persistent.

---

## 13.2 REC TYPE

Choices:

```text
WAV 44kHz
WAV 22kHz
L16 16us
LEP 50us
MZF
```

### WAV 44 kHz

Highest WAV sampling option.

Advantages:

- familiar audio container
- useful for waveform archiving
- easier to inspect in conventional audio software

Disadvantages:

- higher SD write/CPU load
- larger files
- strictest real-time margin

### WAV 22 kHz

Lower data rate and smaller files.

Useful when 44.1 kHz is unnecessary.

### L16

16 µs edge-duration format.

Good for timing-sensitive tape capture without storing every audio sample.

### LEP

50 µs edge-duration format.

Compact and compatible with the LEP pulse-duration concept.

### MZF

Direct logical MZF reconstruction.

When the incoming Sharp tape stream is valid, this is often the most useful recording mode because the result is immediately usable as an MZF rather than an audio/pulse archive.

The direct MZF recorder validates the Sharp header/data structure and checks the block before finalizing the file.

---

## 13.3 Hardware-speed note for WAV + AutoName

> **Important hardware limitation**
>
> Because WAV capture, SD-card writes, packed-sample processing and live AutoName/profile decoding all compete for limited ATmega2560 real-time resources, **WAV recording with AutoName/live metadata recognition is supported only up to the 1:2 speed range**.
>
> Do not treat WAV + AutoName at 1:3 or 1:4 as a supported capture path.
>
> For faster tape signals prefer direct MZF recording or an edge-oriented format such as L16/LEP when appropriate.

Watch the buffer-headroom bar especially carefully when experimenting with higher data rates or slow SD cards.

---

## 13.4 REC MODE = MOTOR

```text
+----------------+
|>REC MODE       |
| MOTOR          |
+----------------+
```

The recorder arms first.

It starts when MOTOR becomes active, pauses when MOTOR becomes inactive and resumes when MOTOR becomes active again.

Typical armed display:

```text
+----------------+
|REC0001.MZF    █|
|PAUSED         M|
+----------------+
```

This is the closest equivalent to a real cassette recorder controlled by the computer.

---

## 13.5 REC MODE = AUTO

```text
+----------------+
|>REC MODE       |
| AUTO           |
+----------------+
```

The recorder arms and waits for signal activity rather than relying on MOTOR.

```text
+----------------+
|REC0001.L16    █|
|WAIT SIGNAL     |
+----------------+
```

After activity starts, capture begins.

When the signal becomes inactive for approximately five seconds, AUTO requests normal finalization.

AUTO is useful when:

- MOTOR is unavailable or unreliable;
- capturing an external tape signal;
- signal activity itself is a better trigger.

---

## 13.6 REC MODE = MANUAL

```text
+----------------+
|>REC MODE       |
| MANUAL         |
+----------------+
```

Capture begins immediately.

The user controls pause/resume and stop.

Use MANUAL for:

- test signals
- nonstandard sources
- capture where the Sharp MOTOR signal should be ignored

---

## 13.7 User pause has priority

If the user presses PLAY during an active recording:

```text
...U
```

is displayed.

This manual pause is not automatically cancelled by MOTOR going HIGH. The user must resume it explicitly.

---

## 13.8 Normal Stop/Save

Press STOP briefly.

The recorder enters finalization:

```text
SAVING ...
PLEASE WAIT
```

Wait for the `SVD` screen.

Do not remove the SD card while `SAVING` is shown.

---

## 13.9 Cancel

Long STOP cancels.

If a file was already created, it is removed.

This is intentionally different from normal STOP/Save.

---

## 13.10 Provisional filenames

Until AutoName has a valid title, recordings use sequence names similar to:

```text
REC0001.WAV
REC0002.L16
REC0003.MZF
```

The next free sequence is chosen automatically.

---

# 14. AutoName and automatic profile detection

AutoName does more than simply change a filename.

When enabled, the firmware attempts to decode useful metadata from the incoming tape stream while recording.

```text
+----------------+
|>AUTONAME       |
| ON             |
+----------------+
```

---

## 14.1 What AutoName does

When a valid recognizable header is found:

1. decode the tape header;
2. validate it;
3. extract and sanitize the title;
4. show the live detected name;
5. continue tracking the payload;
6. after a successful save, rename the provisional `RECxxxx` file.

Example while recording:

```text
+----------------+
|PACMAN         █|
|REC NRL 1:2 37% |
+----------------+
```

---

## 14.2 AutoName is cosmetic – it must not destroy a good recording

If the final rename fails, the completely saved `RECxxxx` file remains intact.

A naming problem must not invalidate the captured data.

---

## 14.3 Duplicate names

If:

```text
PACMAN.MZF
```

already exists, AutoName tries numbered alternatives:

```text
PACMAN_01.MZF
PACMAN_02.MZF
...
PACMAN_99.MZF
```

---

## 14.4 Sanitizing titles

Tape headers may contain Sharp character codes, copier-specific text or characters unsuitable for filenames.

The title is converted to a safe filename representation before being used.

The displayed/saved filename can therefore differ slightly from the exact raw header bytes.

---

## 14.5 AutoName and direct MZF recording

Direct MZF recording already decodes the Sharp structure as part of creating the logical MZF.

The decoded header can therefore provide:

- title
- payload length
- profile information

When the recorded MZF is renamed, its matching metadata sidecar is moved with it when available.

---

## 14.6 AutoName for WAV / L16 / LEP

For physical-waveform/edge recordings, AutoName runs a lightweight parallel decoder.

It can identify:

- standard Sharp MZ headers
- timing/profile information
- IC/InterCopy-family headers
- Turbo Copy
- selected auxiliary Sinclair-style profiles
- selected CP/M/CMT-style profiles

The decoder is deliberately memory-conscious so it can run on ATmega2560 without keeping large duplicate header buffers.

---

## 14.7 WAV + AutoName speed limit

This deserves repeating:

> **WAV record + AutoName/live metadata recognition is a supported combination only up to 1:2.**
>
> At 1:3 and 1:4 the real-time margin is not sufficient to guarantee correct live recognition/capture behaviour on this hardware.

If AutoName is the priority for a fast Sharp signal, use a capture mode designed for that data rate rather than assuming the WAV path will keep up.

---

## 14.8 Profile display

Once detected, the profile is shown on the RECORD status line:

```text
NRL 1:2
MZ7 1:3
IC 1:4
TC 1:3
SIN 1:2
CPM 1:1
```

This helps answer two important questions:

1. **What did the recorder recognize?**
2. **How far through the declared payload are we?**

---

# 15. Understanding the buffer indicator

This is one of the most important diagnostic features of MZ-SD2CMT2.

The buffer bar is always in the **right-most character cell of line 1** during active PLAY/RECORD.

---

## 15.1 Why buffering is needed

The tape signal is real-time.

SD cards are not perfectly real-time:

- a write can occasionally take longer;
- FAT/filesystem operations can cause latency;
- a read may need a new block;
- a slow or poor-quality SD card may pause unpredictably.

MZ-SD2CMT2 therefore places RAM buffering between the time-critical CMT signal and SD-card/file processing.

---

## 15.2 PLAY buffer – queued data

During playback the bar shows **how much data is ready ahead of the output**.

Conceptually:

```text
SD card -> RAM buffer -> real-time CMT output
```

### High PLAY bar

```text
█
```

Good.

There is plenty of data waiting for the timer/ISR output.

### Medium PLAY bar

```text
▅
```

Normally acceptable. The foreground code is refilling the stream.

### Very low PLAY bar

```text
▁
```

The real-time output is consuming data almost as quickly as the SD/filesystem side can provide it.

If the buffer reaches empty before more data is available, playback can report an underrun/error.

---

## 15.3 RECORD buffer – free headroom

During recording, the displayed bar deliberately represents **headroom**, not raw FIFO occupancy.

Conceptually:

```text
real-time CMT input -> RAM buffers -> decoder/file writer -> SD card
```

The firmware converts the internal usage to:

```text
headroom = 100% - used capacity
```

Therefore:

### High RECORD bar

```text
█
```

Very good.

Most of the buffer capacity is free.

### Falling RECORD bar

```text
▅  ->  ▃  ->  ▁
```

Captured data are accumulating faster than they are being drained to decoding/SD storage.

### Nearly empty RECORD bar

```text
▁
```

Warning condition.

There is very little free safety margin.

If incoming data continue to arrive while the system cannot drain the buffers, an overflow may occur.

---

## 15.4 Why PLAY and RECORD use different internal metrics

Internally:

- PLAY cares about **data already available**;
- RECORD cares about **free space still available**.

For the user the display is intentionally normalized so the same visual rule works:

> **more bar = healthier**
>
> **less bar = less safety margin**

---

## 15.5 What makes the RECORD buffer fall?

Common causes:

- high tape speed
- WAV 44.1 kHz
- AutoName enabled
- complex live decoding
- SD card with long write latency
- fragmented/slow media
- simultaneous high-rate capture and metadata recognition

---

## 15.6 What should I do if the bar often gets very low?

Try, in roughly this order:

1. use a known good SD card;
2. avoid unsupported high-speed WAV + AutoName combinations;
3. choose 22 kHz WAV when 44 kHz is unnecessary;
4. use L16/LEP for a fast physical timing capture;
5. use direct MZF for a valid Sharp logical save;
6. reduce tape speed;
7. retest without AutoName to separate capture load from recognition load.

A low buffer bar is much more useful diagnostically than simply waiting for an `OVERFLOW` or `UNDERRUN` message.

---

# 16. System settings

From the root browser, long STOP opens SYSTEM settings.

---

## 16.1 CMT SOURCE

```text
+----------------+
|>CMT SOURCE     |
| INTERNAL       |
+----------------+
```

or:

```text
+----------------+
|>CMT SOURCE     |
| EXTERNAL       |
+----------------+
```

### INTERNAL

Use MZ-SD2CMT2 as the CMT source.

### EXTERNAL

Route the external CMT path on hardware that supports the dedicated switching circuit.

This allows a real cassette recorder or another physical CMT source to remain connected without rewiring.

On a modular build without the dedicated switching hardware, this setting is naturally only meaningful if equivalent external switching has been implemented.

---

## 16.2 BACKLIGHT

Example:

```text
+----------------+
|>BACKLIGHT      |
|  70%           |
+----------------+
```

PLAY cycles the backlight level in 10% steps.

If an EEPROM write fails:

```text
+----------------+
|>BACKLIGHT      |
|  70% EEPROM ERR|
+----------------+
```

---

## 16.3 ABOUT

Example:

```text
+----------------+
|ABOUT v1.0      |
|RAM 3120 MIN2870|
+----------------+
```

The second line is a useful development/diagnostic readout:

- `RAM` = currently free SRAM estimate
- `MIN` = minimum free SRAM observed

The exact numbers depend on firmware path and runtime activity.

---

# 17. Keypad calibration

Different LCD keypad shields use slightly different resistor ladders.

MZ-SD2CMT2 therefore supports button calibration.

Calibration maps:

```text
REWIND -> UP
FFWD   -> DOWN
STOP   -> LEFT
RECORD -> RIGHT
PLAY   -> SELECT
```

---

## 17.1 Automatic calibration

If no valid calibration is stored, startup enters the calibration sequence.

Example:

```text
+----------------+
|KEYPAD          |
|CALIBRATION     |
+----------------+
```

Then:

```text
+----------------+
|CAL NONE        |
|RELEASE ALL     |
+----------------+
```

The unit measures the no-button ADC level.

It then asks for each button:

```text
PRESS REWIND
PRESS FFWD
PRESS STOP
PRESS RECORD
PRESS PLAY
```

Measured ADC values are stored in EEPROM.

---

## 17.2 Force recalibration

With a valid stored mapping, the firmware can decode the boot-time RECORD/RIGHT key and use it to force calibration.

This avoids assuming one fixed ADC threshold for every shield.

---

## 17.3 Calibration errors

Invalid mapping:

```text
CAL INVALID
USING DEFAULT
```

EEPROM save failure:

```text
EEPROM ERROR
NOT SAVED
```

The measured mapping may still be usable for the current session even when it could not be saved.

---

# 18. Recommended setups

## 18.1 “I only want to run MZ-800 software”

Use:

```text
PLAY CTRL = MOTOR
LOADER    = NORMAL
SPEED     = 1:1
```

Select an MZF and load it exactly as you would load from cassette.

This is the safest starting point.

---

## 18.2 “My library has MFI metadata”

Use:

```text
PLAY CTRL = MOTOR
LOADER    = AUTO
```

MFI/MTI can then choose the intended loader per file/record.

---

## 18.3 “I want the fastest possible compatible MZF load”

Try:

```text
LOADER = UL
```

If you know the machine target, use `UL MZ800` or `UL MZ700`.

If UL fails, return to the known compatible normal/turbo loader rather than repeatedly changing unrelated settings.

---

## 18.4 “I want to SAVE from the Sharp directly to an MZF”

Use:

```text
REC TYPE = MZF
REC MODE = MOTOR
AUTONAME = ON
```

This is an excellent everyday combination when the incoming stream is a valid Sharp program save.

The logical MZF result is compact and immediately reusable.

---

## 18.5 “I want to archive the physical signal”

Use:

```text
REC TYPE = L16
```

or, where appropriate:

```text
REC TYPE = LEP
```

These preserve pulse timing efficiently.

Use WAV when a conventional sampled waveform is specifically required.

---

## 18.6 “I want a WAV recording”

For the greatest margin:

```text
REC TYPE = WAV 22kHz
```

Use 44 kHz when the extra sample resolution is useful and the SD card/real-time margin is known to be good.

Remember:

> WAV + AutoName/live recognition is supported only through the 1:2 speed range.

---

## 18.7 “MOTOR control does not work with my source”

Try:

```text
REC MODE = AUTO
```

for activity-triggered recording, or:

```text
REC MODE = MANUAL
```

for complete user control.

---

# 19. Troubleshooting

## 19.1 `INSERT CARD`

The card is not detected.

Check:

- card is fully inserted;
- card-detect hardware, if present;
- SD power;
- SPI connections;
- card itself.

---

## 19.2 `SD CARD ERROR`

The card was detected or probed but initialization failed.

Press RECORD to retry.

If the error persists:

- power-cycle;
- try another SD card;
- check FAT formatting and wiring;
- on modular hardware verify the SD module is 5 V compatible and has proper level shifting.

---

## 19.3 `DIR FAIL`

The card is mounted but the directory scan failed.

Try reinitializing the card. Persistent failures can indicate filesystem/media problems.

---

## 19.4 `EMPTY`

The directory contains no visible entries.

Remember that metadata files are hidden.

---

## 19.5 `NAME TOO LONG`

The selected entry cannot be safely represented in the firmware path/name buffers.

Shorten the filename.

---

## 19.6 `PATH TOO LONG`

The complete directory path plus filename exceeds the session path limit.

Move the file closer to root or shorten folder names.

---

## 19.7 Playback stays at `PAUSED ... M`

You are in MOTOR mode and the computer has not asserted MOTOR.

Check:

- Sharp is actually executing a cassette LOAD operation;
- MOTOR/SSI wiring;
- PLAY CTRL setting.

For testing, MANUAL mode can separate a MOTOR wiring problem from a signal-generation problem.

---

## 19.8 Playback shows `...U`

You paused it manually.

Press PLAY again.

---

## 19.9 `UNDERRUN`

Playback buffer became empty before the next data could be supplied.

Possible causes:

- slow SD card
- very high data rate
- media/filesystem latency
- card removal/interruption

Watch the buffer bar before the error occurs.

---

## 19.10 Record buffer bar falls near zero

The system is losing capture headroom.

Possible causes:

- unsupported high-rate WAV combination
- 44.1 kHz WAV
- AutoName decoding overhead
- slow SD writes
- high-speed incoming tape

Change capture mode or reduce the load before assuming the incoming tape is corrupt.

---

## 19.11 `MZF OVERFLOW`

The direct MZF capture FIFO could not be drained quickly enough.

Use a good SD card and make sure the incoming profile is within the supported real-time range.

---

## 19.12 `MZF CHECKSUM`

The incoming logical block failed its checksum.

The direct MZF recorder can recover from the optional second NORMAL copy in supported cases, but a genuinely bad block cannot be saved as a valid logical MZF.

If the physical tape is important, capture it as L16/LEP/WAV for later analysis instead of forcing an invalid MZF.

---

## 19.13 `MZF INCOMPLETE`

Recording was stopped before a complete valid logical MZF block had been reconstructed.

Allow the full SAVE operation to finish.

---

## 19.14 AutoName did not rename the file

The recording itself may still be completely valid.

AutoName requires a recognizable and validated header.

Possible reasons:

- no valid header was found;
- speed/profile outside the supported live-recognition range;
- capture began too late;
- waveform is damaged;
- title could not be validated;
- final rename failed.

The provisional `RECxxxx` file is intentionally preserved.

---

## 19.15 WAV AutoName fails at 1:3 or 1:4

This is outside the intended supported range.

Use another capture format/path.

The hardware limit is expected behaviour, not necessarily a firmware bug.

---

## 19.16 MFI/MTI seems ignored

Check:

1. PLAY loader is set to **AUTO**;
2. basenames match exactly:
   `GAME.MZF` + `GAME.MFI`;
3. for MZT use `.MTI`;
4. the `RECORD=n` section exists;
5. TYPE/SPEED combination is valid.

Remember that a manually selected loader always overrides metadata.

---

## 19.17 I created `GAME.MZI` but nothing happens

Current external metadata format is:

```text
GAME.MFI
TAPE.MTI
```

`.MZI` is not a supported external fallback.

---

# 20. Technical reference

## 20.1 Sharp CMT signal interface

The original-compatible interface uses four signals:

| Signal | Mega pin | Direction/function |
|---|---:|---|
| `WRITE / SDI` | 15 | data from Sharp to CMT |
| `MOTOR / SSI` | 16 | transport/control from Sharp |
| `READ / SDO` | 2 | data from CMT to Sharp |
| `SENSE / SSO` | 18 | CMT sense/control to Sharp |

<p align="center">
  Sharp MZ 8255 CMT connection
</p>

These signals are also the basis of Ultra Fast transfer.

---

## 20.2 Recording architecture

At a high level:

```text
Sharp WRITE
    |
    v
time-critical capture
    |
    +--> RAM/FIFO
            |
            +--> WAV packer / edge encoder / MZF decoder
                    |
                    +--> SD file
                    |
                    +--> AutoName/profile decoder
```

The design tries to keep the time-critical ISR paths short and moves SD/filesystem work to foreground service functions.

This is why the buffer-headroom indicator is so useful.

---

## 20.3 Playback architecture

```text
SD file
   |
   +--> format parser / generated loader
           |
           +--> RAM buffer
                   |
                   +--> timer / real-time CMT output
```

MOTOR control sits above the transport and can pause/resume the active source.

---

## 20.4 MZF direct-record buffering

The direct MZF engine uses staged buffers plus the edge-capture FIFO.

The user-facing buffer bar is calculated as remaining headroom across the capture/staging capacity.

A full display therefore means low occupancy / large reserve.

---

## 20.5 WAV record buffer

The WAV backend reports its internal fill percentage; the common RECORD layer converts this to headroom before displaying it.

This ensures that **high bar = good** remains true.

---

## 20.6 PLAY WAV buffering

WAV playback pre-fills a sample stream and refills it in blocks before the timer consumes the data.

If the source buffer runs empty, the driver can report `UNDERRUN`.

---

## 20.7 Persistent settings

The firmware stores user settings in EEPROM, including:

- keypad calibration
- PLAY options
- per-loader speed selections
- TAP speed
- RECORD format/mode
- AutoName state
- system CMT source
- backlight

---

## 20.8 `/RECORDINGS`

All normal recording sessions target the root-level:

```text
/RECORDINGS
```

directory.

This keeps captures separate from the user's library folders and gives AutoName a predictable destination.

---

## 20.9 Metadata visibility

MFI/MTI are intentionally hidden from the browser.

They do not count toward the visible `N/N` item total.

This prevents a directory from appearing to contain duplicate user programs simply because each MZF has a sidecar.

---

# 21. Glossary

### AutoName
Live header recognition used to derive a meaningful filename and optional detected profile from a recording.

### AUTO playback
Loader mode that uses MFI/MTI when available and falls back safely when metadata is missing.

### AUTO recording
Activity-triggered recording mode. Capture starts from detected signal activity and ends after the idle timeout.

### Buffer
RAM used to decouple real-time tape input/output from slower or bursty SD-card operations.

### CMT
Cassette Magnetic Tape / cassette interface terminology used by Sharp systems.

### Headroom
Free capacity remaining in the recording buffers. The RECORD bar displays headroom.

### IC
IC/InterCopy-family turbo loader/profile terminology used by the firmware.

### LEP
Compact pulse-duration format using a 50 µs unit.

### L16
Pulse-duration format using a 16 µs unit.

### MFI
**MZF Information** sidecar used by this project for playback metadata belonging to one MZF. It is consulted in `LOADER=AUTO` mode and can select `TYPE` and `SPEED` without modifying the MZF itself.

### MOTOR
Sharp CMT control signal used to start/stop the virtual transport.

### MZF
Canonical single Sharp MZ program/tape image.

### MZT
Container holding multiple logical MZF records.

### MTI
**MZT Information** sidecar containing per-record playback metadata for an MZT. Each 1-based `RECORD=n` section can select its own loader/profile, which is especially useful for multi-part games.

### N11 / N12 / N13 / N14
Compact LCD labels for NORMAL 1:1 / 1:2 / 1:3 / 1:4.

### NRL
Detected normal Sharp tape profile shown during recording.

### PLA
PLAY-active state where loader information came from the information sidecar.

### PLY
Normal active PLAY state.

### PAU
Paused.

### RDY
Ready.

### SIN
Detected Sinclair-style auxiliary tape profile.

### CPM
Detected CP/M/CMT-style auxiliary profile.

### IC
InterCopy-family turbo loader/profile. `IC2`, `IC3` and `IC4` mean IC 1:2, 1:3 and 1:4.

### TC
Turbo Copy loader/profile. `TC2`, `TC3` and `TC4` mean TC 1:2, 1:3 and 1:4.

### UL
Firmware shorthand for the Ultra Fast loader/transfer path. It uses the CMT handshake for the fast payload rather than being merely another NORMAL speed ratio.

### UL7
Compact LCD form of `UL MZ700`; sidecar syntax is `TYPE=UL_MZ700`. The `7` identifies MZ-700, not speed 1:7.

### UL8
Compact LCD form of `UL MZ800`; sidecar syntax is `TYPE=UL_MZ800`. The `8` identifies MZ-800, not speed 1:8.

### User pause (`U`)
Pause explicitly requested by pressing PLAY.

### Motor pause (`M`)
Pause caused by the Sharp MOTOR signal.

---

# Revision note – sidecars and multi-part software

This revision expands the explanation of loader abbreviations and documents the intended use of MFI/MTI sidecars for single MZF files, MZT records and multi-part games.

# Documentation notes for the next revision

The following improvements are recommended before publishing a polished PDF:

- replace selected text LCD mock-ups with real LCD photographs or pixel-accurate renders;
- add arrows/callouts to the buffer column and pause-reason column;
- include a full front-panel button photograph;
- include side-by-side examples of normal PLAY, MOTOR pause and USER pause;
- include a sequence of AutoName screenshots:
  `RECxxxx` → detected title → detected profile/progress → `SAVING` → `SVD`;
- include side-by-side MZT examples for `SEL`, `MTI` and `MAN`;
- verify all loader examples on real MZ-800/MZ-700 hardware before freezing the PDF;
- add a short “first five minutes” two-page spread for printed use;
- create a final PDF with clickable table of contents and internal cross-references.

---

**Project:** MZ-SD2CMT2 – Reborn  
**Repository:** `bales0/MZ-SD2CMT2-Reborn`  
**Document status:** Draft for review

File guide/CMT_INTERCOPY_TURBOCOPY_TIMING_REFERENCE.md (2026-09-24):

# Sharp MZ CMT — Intercopy 10.2 & TurboCopy 1.22 Timing Reference

**Účel:** zdrojová reference pro stanovení časových konstant v **QDTool/QDTools** a **MZ-SD2CMT2**.

**Datum analýzy:** 2026-09-14

Tento dokument je určen k používání společně s:

- `CMT_TIMING_REFERENCE.md`
- `LEADER_PULSES_UNIFICATION.md`

Neřeší znovu kompletní Sharp ROM timing ani politiku leader counts. Doplňuje je o přímou analýzu dvou historických kopírek:

- **Intercopy V10.2**
- **Turbo Copy V1.22 / TC1.22**

Hlavní zásada:

> Vždy rozlišovat **writer-generated waveform**, **receiver decision timing**, **project compatibility waveform** a **leader/framing policy**. Tyto čtyři věci nejsou zaměnitelné.

---

# 1. Vstupní binárky

## 1.1 Intercopy V10.2

Soubor:

```text
Incopy102(3).mzf
```

SHA-256:

```text
b7b8669791a12c0212b046defdd37ca1f2687e595589c1cddf07bdb2ef443439
```

Identifikace v MZF filename:

```text
Intercopy V10.2
```

Poznámka: MZ znaková sada není ASCII, ale suffix `V10.2` je v headeru přímo čitelný.

---

## 1.2 Turbo Copy V1.22

Soubor:

```text
Tc122(4).mzf
```

SHA-256:

```text
aa1ee60b85ff8d2ef9f5cc0ebf43b199b7e5e0e715c85ee6b28e09aa9f68e384
```

MZF:

```text
TYPE = $01
LOAD = $1200
EXEC = $2D98
SIZE = 7083 B
```

Filename končí:

```text
V1.22
```

Startovací rutina kopíruje hlavní pracovní obraz z `$1200` do oblasti začínající `$E471`.

Relokační rozdíl použitý níže:

```text
$E471 - $1200 = $D271
```

Tím lze přímo mapovat kód uložený v MZF na runtime adresy TurboCopy.

---

# 2. Evidence labels používané v tomto dokumentu

```text
COPIER-WRITER-EXACT
    instrukce skutečného writeru konkrétní kopírky
    + deterministický výpočet Z80/timer timingů

COPIER-TIMER-EXACT
    přesná hodnota programovaného HW čítače / timer mode;
    převod na µs může stále záviset na přesné fyzické clock frekvenci

RECEIVER-EXACT
    přesný loader/monitor receive path a decision window

HW-NOMINAL
    hodnota z hardware/service dokumentace, např. CKMS = 1.10 MHz

PROJECT-COMPAT
    záměrně zvolený pevný waveform s dobrou receive margin;
    nemusí být totožný s historickým writerem

PROJECT-FRAMING
    kanonická politika leader/tapemark counts projektu;
    nesmí být odvozována z pulse width
```

Pro rozhodování o změně konstant platí:

```text
writer-exact != receiver-exact != compatibility waveform != framing
```

---

# 3. Intercopy V10.2 — rozlišení NORMAL a FAST IPL

## 3.1 Mode selector

Intercopy používá mode byte na `$16F3`.

Analýza programu dává:

```text
0 = NORMAL
1 = SINCLAIR
2 = CPM
3 = TURBO
4 = FAST IPL
```

To je důležité, protože společná FM writer rutina je používána více režimy.

---

## 3.2 NORMAL používá společný FM writer přímo

Pro režim NORMAL vede cesta v Intercopy přibližně:

```text
$2035
  -> $2054
  -> $19EE
  -> $1E39
  -> $1E09        select speed row
  -> table $16F7
  -> $1DF5        self-modify pulse delays
  -> $1D8E        physical CMT pulse writer
```

Takže časování odvozené z `$16F7/$1D8E` **není omylem jen FAST IPL timing**.

NORMAL používá tento writer přímo při zvolené rychlosti.

---

## 3.3 FAST IPL používá stejný fyzický FM writer jinak

FAST IPL má zvláštní setup.

Rutina kolem `$201C`:

1. uloží aktuálně zvolenou turbo rychlost,
2. nastaví dočasně `1200 Bd`,
3. zapíše loader/header,
4. původní rychlost obnoví,
5. turbo body zapíše společným FM writerem při vybrané rychlosti.

Tedy:

```text
FAST IPL header
    -> 1200 Bd physical FM timing

FAST IPL turbo body
    -> selected 2400 / 2800 / 3200 Bd physical FM timing
```

Framing FAST IPL je samostatná věc a řídí se `LEADER_PULSES_UNIFICATION`.

---

# 4. Intercopy speed table `$16F7`

Relevantní řádky:

```text
speed   readpoint   t1   t2   t3   t4
--------------------------------------
1200      $4D      $40  $80  $48  $87
2400      $20      $1F  $40  $26  $47
2800      $16      $18  $30  $22  $3D
3200      $11      $15  $2B  $20  $31
```

Význam:

```text
readpoint
    parametr receiveru / DLY3 family

t1
    SHORT první půlvlna

t2
    LONG první půlvlna

t3
    SHORT druhá půlvlna

t4
    LONG druhá půlvlna
```

`$1DF5` vloží čtyři timing bytes přímo do self-modifikované pulse rutiny `$1D8E`.

To je přímý důkaz, že Intercopy waveform může být asymetrický.

---

# 5. Intercopy writer `$1D8E` — výpočet pulse widths

Pro běžný steady data path je možné intervaly vyjádřit:

```text
první půlvlna:
    N = ($F2 + timing_operand) & $FF
    T = 182 + 13*N

druhá půlvlna:
    N = ($F3 + timing_operand) & $FF
    T = 169 + 13*N
```

Použitý PAL MZ-800 CPU clock:

```text
3,546,875 Hz
```

Převod:

```text
time_us = T / 3,546,875 * 1,000,000
```

Poznámka:

- tabulka níže je referenční steady-data waveform;
- některé leader/tape-mark kontexty mohou mít nepatrnou caller-dependent odchylku;
- například u některého opakovaného LONG kontextu může být rozdíl řádu 1 T;
- pro pevný čtyřčíselný profil jsou hodnoty níže správnou code-derived referencí.

Evidence:

```text
COPIER-WRITER-EXACT
```

---

# 6. Intercopy V10.2 — code-derived physical waveform

## 6.1 1200 Bd

```text
SHORT HIGH =  832 T = 234.573 us
SHORT LOW  =  936 T = 263.894 us

LONG  HIGH = 1664 T = 469.145 us
LONG  LOW  = 1755 T = 494.802 us
```

Tento výsledek je zároveň velmi dobrý sanity check proti standardnímu MZ-800 CMT waveformu.

---

## 6.2 2400 Bd

```text
SHORT HIGH = 403 T = 113.621 us
SHORT LOW  = 494 T = 139.278 us

LONG  HIGH = 832 T = 234.573 us
LONG  LOW  = 923 T = 260.229 us
```

Historický faktor:

```text
2:1
```

---

## 6.3 2800 Bd

```text
SHORT HIGH = 312 T =  87.965 us
SHORT LOW  = 442 T = 124.617 us

LONG  HIGH = 624 T = 175.930 us
LONG  LOW  = 793 T = 223.577 us
```

Historický speed ratio:

```text
7:3 = 2.333333...
```

V současném projektovém názvosloví se tento stupeň často označuje jako:

```text
NORMAL 1:3
IC 1:3
```

ale **nejde matematicky o 3.000×**.

---

## 6.4 3200 Bd

```text
SHORT HIGH = 273 T =  76.969 us
SHORT LOW  = 416 T = 117.286 us

LONG  HIGH = 559 T = 157.604 us
LONG  LOW  = 637 T = 179.595 us
```

Historický speed ratio:

```text
8:3 = 2.666666...
```

V současném projektovém názvosloví se tento stupeň často označuje jako:

```text
NORMAL 1:4
IC 1:4
```

ale **nejde matematicky o 4.000×**.

---

# 7. Kritický závěr pro NORMAL 3 / NORMAL 4

Pro historickou reprodukci Intercopy NORMAL:

```text
NORMAL "3" / 2800 Bd:
    SHORT 87.965 / 124.617 us
    LONG  175.930 / 223.577 us

NORMAL "4" / 3200 Bd:
    SHORT 76.969 / 117.286 us
    LONG  157.604 / 179.595 us
```

Tedy historický Intercopy NORMAL 3200 **není**:

```text
112 / 80 us
176 / 160 us
```

a není ani:

```text
96 / 96 us
192 / 192 us
```

Je záměrně / algoritmicky asymetrický.

Pro NORMAL 3200 je navíc důležitý poměr rozhodující první půlvlny:

```text
LONG_HIGH / SHORT_HIGH
= 157.604 / 76.969
≈ 2.048
```

To dává výrazně větší SHORT/LONG separation než profil:

```text
176 / 112 ≈ 1.571
```

Toto je důležité pro Barbarian-style adaptive receiver.

---

# 8. Intercopy IC loader — receiver timing není writer waveform

`CMT_TIMING_REFERENCE` už stanovuje přesné receiver windows pro IC.

IC loader:

- spouští low-monitor copy z RAM,
- patchuje DLY3,
- přidává EDGE-return hook s netto zpožděním `+86 T`.

Receiver equation:

```text
IC earliest = 171 + 14*N T
IC latest   = 223 + 14*N T
```

Speed bytes:

```text
IC 1:2 -> $20 = 32
IC 1:3 -> $16 = 22
IC 1:4 -> $11 = 17
```

Receiver windows:

```text
IC 1:2:
    619..671 T
    174.520..189.181 us

IC 1:3:
    479..531 T
    135.048..149.709 us

IC 1:4:
    409..461 T
    115.313..129.974 us
```

Současné SD2CMT2 IC waveforms:

```text
IC 1:2:
    SHORT 144 / 112 us
    LONG  256 / 224 us

IC 1:3:
    SHORT 112 /  96 us
    LONG  224 / 192 us

IC 1:4:
    SHORT 112 /  80 us
    LONG  176 / 160 us
```

Tyto hodnoty jsou:

```text
PROJECT-COMPAT / HW-tested compatibility waveform
```

Nejsou to:

```text
COPIER-WRITER-EXACT Intercopy waveform
```

Proto se v QDTool ani SD2CMT2 nesmí jedna tabulka automaticky používat pro:

```text
NORMAL 3200 exact
a
IC 1:4 compatibility
```

---

# 9. Doporučené oddělení Intercopy profilů v kódu

Pro oba projekty je vhodné mít koncepčně dvě vrstvy.

## Historická writer reference

```text
INTERCOPY_NORMAL_1200
INTERCOPY_NORMAL_2400
INTERCOPY_NORMAL_2800
INTERCOPY_NORMAL_3200
```

s code-derived H/L hodnotami z kapitoly 6.

Stejný physical timing engine je relevantní i pro FAST IPL turbo body.

## Receiver-compatible SD2CMT2 profiles

```text
IC_1_2_COMPAT
IC_1_3_COMPAT
IC_1_4_COMPAT
```

s dosavadními HW-proven hodnotami.

Změna jedné vrstvy nesmí automaticky měnit druhou.

---

# 10. QDTool WAV — důsledek sample rate

Při 44.1 kHz má jeden sample:

```text
22.675737 us
```

Intercopy NORMAL 3200 pak odpovídá přibližně:

```text
SHORT HIGH  76.969 us -> 3.394 samples
SHORT LOW  117.286 us -> 5.172 samples

LONG HIGH   157.604 us -> 6.950 samples
LONG LOW    179.595 us -> 7.920 samples
```

To je hrubá mřížka, zejména pro nejkratší 77-us půlvlnu.

Proto pro waveform-fidelity export:

```text
88.2 kHz
```

je výrazně vhodnější než 44.1 kHz.

Pokud QDTool zůstane na 44.1 kHz, musí používat průběžný fractional/error accumulator; jednotlivé pulsy budou stále výrazně kvantizované.

---

# 11. Turbo Copy V1.22 — nová přímá writer analýza

Starší reference měla:

```text
TC loader/readpoint = exact
TC historical writer loop = not yet directly established
```

`Tc122(4).mzf` tuto mezeru pro **Turbo Copy V1.22** zavírá.

Pozor:

> Tato část je source-exact pro TC1.22. Nesmí se bez dalšího tvrdit, že V1.0, V1.2, V1.21 a V1.22 mají bit-identický writer.

---

# 12. TurboCopy V1.22 — runtime relocation

Start na `$2D98` provádí relocaci hlavní pracovní oblasti do high monitor/work RAM prostoru.

Relevantní mapping:

```text
source $1974 -> runtime $EBE5
source $19A0 -> runtime $EC11
source $19A8 -> runtime $EC19
```

Právě `$EBE5` je fyzický CMT writer.

---

# 13. TurboCopy V1.22 — 8253 counter 0

TC1.22 programuje 8253 control register hodnotou:

```text
$36
```

Dekódování 8253 control word:

```text
counter = 0
RW      = LSB then MSB
mode    = MODE 3
format  = binary
```

MODE3 je square-wave generator.

Sharp MZ-800 service manual uvádí pro counter #0:

```text
CLK0 / CKMS = nominal 1.10 MHz
```

a OUT0 je přiveden také na:

```text
Z80 PIO PA4
```

TurboCopy tedy používá HW timer jako časovou základnu writeru.

Evidence:

```text
COPIER-TIMER-EXACT
+
HW-NOMINAL pro převod na µs
```

---

# 14. TurboCopy V1.22 — writer `$EBE5`

Zjednodušený význam runtime rutiny:

```asm
LD HL,(E25E)        ; SHORT timer count
JR NC,short
ADD HL,HL           ; Carry => LONG = 2 * SHORT

wait OUT0 phase
LD A,$03
OUT ($D3),A         ; jedna CMT WRITE hrana

...

wait opposite OUT0 phase
LD A,$02
OUT ($D3),A         ; druhá CMT WRITE hrana

CALL $E83D          ; reload 8253 counter 0 z HL
```

Důležité závěry:

```text
SHORT counter = E25E
LONG  counter = 2 * E25E
```

To je přímý writer kód.

LONG/SHORT ratio v timer count domain je tedy přesně:

```text
2:1
```

---

# 15. TurboCopy V1.22 — výpočet SHORT counteru

Runtime `$E87C/$E89E` používá:

```text
base = 480
ratio numerator   = byte E49C
ratio denominator = byte E49B
offset = 71
```

Výsledkem je:

```text
SHORT_COUNT =
    floor(480 * numerator / denominator) + 71
```

a:

```text
LONG_COUNT = 2 * SHORT_COUNT
```

Toto je:

```text
COPIER-TIMER-EXACT
```

V dodaném TC1.22 je výchozí stav:

```text
E49B = 2
E49C = 1
```

tedy:

```text
SHORT_COUNT
= floor(480 * 1 / 2) + 71
= 240 + 71
= 311

LONG_COUNT = 622
```

To odpovídá režimu 2:1.

Pro ratio 3:1:

```text
SHORT_COUNT
= floor(480 * 1 / 3) + 71
= 160 + 71
= 231

LONG_COUNT = 462
```

---

# 16. TurboCopy V1.22 — MODE3 timer half-periods

Pro 8253 MODE3:

- sudý count: HIGH a LOW mají `N/2` timer clocks,
- lichý count: jedna fáze má `(N+1)/2`, druhá `(N-1)/2`.

## TC 2:1

```text
SHORT count = 311
    MODE3 halves = 156 / 155 CKMS ticks

LONG count = 622
    MODE3 halves = 311 / 311 CKMS ticks
```

Při service-manual nominal:

```text
CKMS = 1.10 MHz
```

vyjde raw OUT0 reference:

```text
SHORT:
    156 ticks = 141.818 us
    155 ticks = 140.909 us

LONG:
    311 ticks = 282.727 us
    311 ticks = 282.727 us
```

## TC 3:1

```text
SHORT count = 231
    MODE3 halves = 116 / 115 CKMS ticks

LONG count = 462
    MODE3 halves = 231 / 231 CKMS ticks
```

Při 1.10 MHz:

```text
SHORT:
    116 ticks = 105.455 us
    115 ticks = 104.545 us

LONG:
    231 ticks = 210.000 us
    231 ticks = 210.000 us
```

Tyto hodnoty jsou **timer OUT0 timing**, ne ještě absolutně přesný PC1 cassette-WRITE edge schedule.

---

# 17. TurboCopy writer — proč nelze timer halves slepě vydávat za exact WRITE µs

TurboCopy writer nepřepojuje CMT WRITE přímo HW výstupem OUT0.

Z80:

1. polluje PIO PA4 / OUT0,
2. detekuje změnu timer phase,
3. až potom provede `OUT ($D3),A`.

Relevantní poll smyčka má řádově:

```text
IN + AND + JP = 25 Z80 T
```

Při 3.546875 MHz:

```text
25 T ≈ 7.048 us
```

Obě fyzické WRITE hrany mají podobnou následnou instrukční režii, ale okamžik zachycení timer edge je kvantovaný pollingem.

Proto:

```text
exact historical TC cassette WRITE waveform
```

není ideálně reprezentován jednou dokonale konstantní H/L čtveřicí.

Code-exact historická reprezentace je:

```text
MODE3 counter model
+
counter values
+
Z80 polling
```

Pro pevný čtyřčíselný profil je nutné zvolit aproximaci.

---

# 18. TurboCopy receiver — přesné readpointy

`CMT_TIMING_REFERENCE` stanovuje TurboCopy receiver path.

90B loader je zaveden na:

```text
$D400
```

Speed byte je:

```text
$D44B
```

a loader provede:

```asm
LD A,($D44B)
LD ($0A4B),A
```

bez Intercopy `+86 T` EDGE hooku.

Receiver equation:

```text
earliest = 85 + 14*N T
latest   = earliest + 52 T
```

## TC 1:2

```text
N = $29 = 41

sample window:
659..711 T
185.797..200.458 us
```

## TC 1:3

```text
N = $1B = 27

sample window:
463..515 T
130.537..145.198 us
```

Evidence:

```text
RECEIVER-EXACT
```

---

# 19. TurboCopy current project waveform vs writer reference

Současný SD2CMT2 používá:

```text
TC 1:2:
    SHORT 144 / 144 us
    LONG  288 / 288 us

TC 1:3:
    SHORT 112 / 112 us
    LONG  204 / 204 us
```

Tyto hodnoty mají dobrou receiver margin.

Nejsou však doslovnou reprezentací každého writer edge TC1.22.

Jejich status zůstává:

```text
PROJECT-COMPAT
```

Nová TC1.22 analýza poskytuje vedle nich historickou timer reference:

```text
TC 2:1:
    timer-centered SHORT ≈ 141 us
    timer-centered LONG  ≈ 283 us

TC 3:1:
    timer-centered SHORT ≈ 105 us
    timer-centered LONG  ≈ 210 us
```

s cca ±jedním polling quantum na jednotlivých software-detected edges.

Proto se nedoporučuje bez HW regression pouze přepsat stávající SD2CMT2 TC constants na timer-centered čísla.

---

# 20. TurboCopy V1.22 loader fingerprint

TC1.22 obsahuje 90B loader family zaváděnou na `$D400`.

V dodané binárce má extrahovaný 90B template před runtime metadata patchingem SHA-256:

```text
8f90221c447fe891a84364a437e66fae3d348bcc72d7cc2bc4d70433e7d7a0d1
```

To není bit-identický hash s dříve dokumentovanou V1.21-derived SD2CMT2 šablonou.

Z toho plyne:

> Nezaměňovat „stejná loader family / stejný timing mechanism“ s „bit-identická verze kopírky“.

Pro timing-critical receiver část však TC1.22 přímo obsahuje princip:

```text
speed byte -> $0A4B
```

stejně jako analyzovaná TC family.

---

# 21. Leader/framing policy — používat samostatný dokument

Pulse timing nesmí měnit leader counts.

Pro QDTool/SD2CMT2 používat `LEADER_PULSES_UNIFICATION` jako projektovou politiku.

Kanonicky:

```text
NATIVE NORMAL:
    HEADER = 22000 SHORT
    DATA   = 11000 SHORT

SPECIAL LOADER:
    HEADER       = 11000 SHORT
    loader DATA  =  5500 SHORT
    turbo DATA   =  5500 SHORT
```

Pro IC:

```text
11000 / 5500
```

má navíc silnou historickou a HW podporu.

Pro TC:

```text
11000 / 5500 / 5500
```

je **SD2CMT2 canonical/optimized framing policy**, nikoliv tvrzení o přesném historickém framingu každé TurboCopy verze.

Tato politika nesmí být zaměněna za pulse-width analýzu tohoto dokumentu.

---

# 22. Doporučené constants model pro QDTool

QDTool by měl rozlišit minimálně:

```text
HistoricalWriterProfile
CompatibilityReceiverProfile
FramingProfile
```

## Intercopy historical writer

```text
NORMAL_1200:
    short = 234.573 / 263.894 us
    long  = 469.145 / 494.802 us

NORMAL_2400:
    short = 113.621 / 139.278 us
    long  = 234.573 / 260.229 us

NORMAL_2800:
    short = 87.965 / 124.617 us
    long  = 175.930 / 223.577 us

NORMAL_3200:
    short = 76.969 / 117.286 us
    long  = 157.604 / 179.595 us
```

Pokud MFI/MTI zachovává historická projektová jména:

```text
NORMAL 1:3 -> Intercopy 2800 / 7:3
NORMAL 1:4 -> Intercopy 3200 / 8:3
```

musí být toto mapování výslovně dokumentováno.

---

# 23. Doporučené constants model pro SD2CMT2

## NATIVE / historical reproduction path

Pokud cílem režimu je reprodukovat Intercopy NORMAL:

```text
použít Intercopy writer-exact reference
```

## IC hardware-compat path

Pokud cílem je současný HW-proven IC loader:

```text
zachovat IC compatibility waveforms
```

dokud nejsou writer-exact hodnoty samostatně otestovány na reálném MZ.

## TC hardware-compat path

Současné:

```text
TC 1:2 = 144/144, 288/288
TC 1:3 = 112/112, 204/204
```

mají dobré receiver margins.

TC1.22 source-exact writer je lépe modelovat pomocí:

```text
8253 MODE3 + counter values + polling
```

než tvrdit, že historický writer měl jednu absolutně konstantní symetrickou čtveřici.

---

# 24. Doporučená tabulka zdrojové autority

| Profil / údaj | Autoritativní hodnota | Evidence |
|---|---|---|
| MZ-800 NORMAL 1× ROM | dle `CMT_TIMING_REFERENCE` | ROM-PATH-HIGH |
| Intercopy NORMAL 1200 | 234.573/263.894, 469.145/494.802 us | COPIER-WRITER-EXACT |
| Intercopy NORMAL 2400 | 113.621/139.278, 234.573/260.229 us | COPIER-WRITER-EXACT |
| Intercopy NORMAL 2800 | 87.965/124.617, 175.930/223.577 us | COPIER-WRITER-EXACT |
| Intercopy NORMAL 3200 | 76.969/117.286, 157.604/179.595 us | COPIER-WRITER-EXACT |
| IC receiver 1:2 | 174.520..189.181 us read window | RECEIVER-EXACT |
| IC receiver 1:3 | 135.048..149.709 us read window | RECEIVER-EXACT |
| IC receiver 1:4 | 115.313..129.974 us read window | RECEIVER-EXACT |
| IC current waveform | 144/112–256/224; 112/96–224/192; 112/80–176/160 | PROJECT-COMPAT / HW-proven |
| TC1.22 2:1 writer | SHORT count 311, LONG 622 | COPIER-TIMER-EXACT |
| TC1.22 3:1 writer | SHORT count 231, LONG 462 | COPIER-TIMER-EXACT |
| TC 1:2 receiver | 185.797..200.458 us | RECEIVER-EXACT |
| TC 1:3 receiver | 130.537..145.198 us | RECEIVER-EXACT |
| TC current 1:2 waveform | 144/144, 288/288 us | PROJECT-COMPAT |
| TC current 1:3 waveform | 112/112, 204/204 us | PROJECT-COMPAT |
| native NORMAL leaders | 22000 / 11000 | PROJECT-FRAMING / Sharp standard |
| special loader leaders | 11000 / 5500 | PROJECT-FRAMING |
| TC canonical 11000/5500/5500 | SD2CMT2 policy | PROJECT-FRAMING |

---

# 25. Co se nesmí znovu zaměnit

## 25.1 NORMAL 3200 není IC 1:4 waveform

Zakázaná inference:

```text
IC 1:4 speed byte = $11
=> NORMAL 1:4 musí být 112/80,176/160
```

Správně:

```text
$11 je receiver/readpoint speed byte
+
Intercopy 3200 writer používá vlastní t1..t4 row
```

---

## 25.2 Intercopy 3/4 nejsou matematické 3×/4×

```text
"3" -> 2800 Bd -> 7:3 ≈ 2.333×
"4" -> 3200 Bd -> 8:3 ≈ 2.667×
```

---

## 25.3 TurboCopy receiver delay není writer pulse width

```text
$29 / $1B
```

jsou receive DLY3 values.

Writer TC1.22 používá:

```text
8253 MODE3
E25E counter
```

---

## 25.4 TC fixed µs profile není bit-exact TC writer

Historický writer má:

```text
HW timer edge
-> Z80 polling
-> software CMT WRITE edge
```

Proto fixní waveform je nutně aproximace.

---

## 25.5 Leader count není pulse duration

Použít `LEADER_PULSES_UNIFICATION`.

Rychlejší waveform nesmí automaticky měnit počet leader pulzů.

---

# 26. Doporučení pro další implementaci

## QDTool

1. Opravit NORMAL 1:4 tak, aby nebyl kopií IC 1:4 compatibility timing.
2. Pokud názvy 1:3/1:4 reprezentují Intercopy slots:
   - 1:3 -> 2800 Bd code-derived row,
   - 1:4 -> 3200 Bd code-derived row.
3. Pro WAV s 3200 Bd preferovat 88.2 kHz nebo vyšší sample rate.
4. Oddělit writer-fidelity profily od loader-compatibility profilů.
5. Přidat automatické edge-duration testy pro všechny waveform profily.

## SD2CMT2

1. Neměnit HW-proven IC/TC compatibility constants pouze na základě historické fidelity.
2. Pokud se zavede faithful Intercopy NORMAL profil, použít code-derived row.
3. Pokud se zavede faithful TurboCopy profil, ideálně modelovat MODE3 count a polling, ne jen čtyři absolutní µs hodnoty.
4. Všechny změny IC/TC časování provést až s real-MZ regression.
5. Leader counts držet podle `LEADER_PULSES_UNIFICATION`.

---

# 27. Machine-readable reference

```yaml
schema: sharp-mz-copier-timing-reference-v1

clock:
  mz800_cpu_hz: 3546875
  tc_8253_ckms_nominal_hz: 1100000
  tc_8253_ckms_status: HW-NOMINAL

intercopy_v10_2:
  sha256: b7b8669791a12c0212b046defdd37ca1f2687e595589c1cddf07bdb2ef443439
  writer_evidence: COPIER-WRITER-EXACT

  normal_1200:
    readpoint: 0x4d
    short_us: [234.573, 263.894]
    long_us:  [469.145, 494.802]

  normal_2400:
    readpoint: 0x20
    short_us: [113.621, 139.278]
    long_us:  [234.573, 260.229]

  normal_2800:
    historical_ratio: "7:3"
    project_alias: "1:3"
    readpoint: 0x16
    short_t: [312, 442]
    long_t:  [624, 793]
    short_us: [87.965, 124.617]
    long_us:  [175.930, 223.577]

  normal_3200:
    historical_ratio: "8:3"
    project_alias: "1:4"
    readpoint: 0x11
    short_t: [273, 416]
    long_t:  [559, 637]
    short_us: [76.969, 117.286]
    long_us:  [157.604, 179.595]

ic_receiver:
  "1:2":
    dly3: 0x20
    sample_t: [619, 671]
    sample_us: [174.520, 189.181]
    current_compat_short_us: [144, 112]
    current_compat_long_us: [256, 224]

  "1:3":
    dly3: 0x16
    sample_t: [479, 531]
    sample_us: [135.048, 149.709]
    current_compat_short_us: [112, 96]
    current_compat_long_us: [224, 192]

  "1:4":
    dly3: 0x11
    sample_t: [409, 461]
    sample_us: [115.313, 129.974]
    current_compat_short_us: [112, 80]
    current_compat_long_us: [176, 160]

turbocopy_v1_22:
  sha256: aa1ee60b85ff8d2ef9f5cc0ebf43b199b7e5e0e715c85ee6b28e09aa9f68e384
  writer_evidence: COPIER-TIMER-EXACT
  timer:
    chip: "8253 counter 0"
    mode: 3
    control_word: 0x36
    short_count_formula: "floor(480*numerator/denominator)+71"
    long_count_formula: "2*short_count"

  "1:2":
    ratio_pair: [1, 2]
    short_count: 311
    long_count: 622
    mode3_short_ticks: [156, 155]
    mode3_long_ticks: [311, 311]
    nominal_out0_short_us_at_1_10mhz: [141.818, 140.909]
    nominal_out0_long_us_at_1_10mhz: [282.727, 282.727]
    receiver_dly3: 0x29
    receiver_window_us: [185.797, 200.458]
    current_compat_short_us: [144, 144]
    current_compat_long_us: [288, 288]

  "1:3":
    ratio_pair: [1, 3]
    short_count: 231
    long_count: 462
    mode3_short_ticks: [116, 115]
    mode3_long_ticks: [231, 231]
    nominal_out0_short_us_at_1_10mhz: [105.455, 104.545]
    nominal_out0_long_us_at_1_10mhz: [210.000, 210.000]
    receiver_dly3: 0x1b
    receiver_window_us: [130.537, 145.198]
    current_compat_short_us: [112, 112]
    current_compat_long_us: [204, 204]

framing_policy:
  native_normal:
    header_short_pulses: 22000
    data_short_pulses: 11000

  special_loader:
    header_short_pulses: 11000
    loader_data_short_pulses: 5500
    turbo_data_short_pulses: 5500
```

---

# 28. Finální rozhodovací pravidlo

Při nastavování nové konstanty v QDTool nebo SD2CMT2 se nejdřív musí odpovědět:

```text
Chci:
A) historicky věrný writer waveform?
B) waveform s nejlepší receiver margin?
C) kanonický project framing?
```

Pak:

```text
A -> použij tento dokument / COPIER-WRITER-EXACT nebo COPIER-TIMER-EXACT

B -> použij CMT_TIMING_REFERENCE receiver windows
     + HW regression

C -> použij LEADER_PULSES_UNIFICATION
```

Nikdy neodvozovat jednu z těchto vrstev automaticky z druhé.

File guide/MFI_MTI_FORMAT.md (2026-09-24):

# MFI / MTI playback metadata

External metadata names are explicit:

- `GAME.MZF` -> `GAME.MFI`
- `TAPE.MZT` -> `TAPE.MTI`

There is no `.MZI` fallback. The internal source/API name `mzi_sidecar.*` is
kept only to avoid an unrelated project-wide rename.

## MFI for one MZF

Example:

```text
TYPE=NORMAL
SPEED=1:3
```

Intercopy and TurboCopy examples:

```text
TYPE=IC
SPEED=1:1
```

```text
TYPE=TC
SPEED=1:1
```

Loader without a SPEED field:

```text
TYPE=UL_MZ800
```

MFI is used only when PLAY loader selection is `AUTO`. A manually selected
loader/profile always has priority.

## MTI for an MZT container

Each MZT logical MZF record can use its own loader/profile. Record numbering is
1-based.

```text
RECORD=1
TYPE=NORMAL
SPEED=1:3

RECORD=2
TYPE=IC
SPEED=1:1

RECORD=3
TYPE=TC
SPEED=1:1

RECORD=4
TYPE=UL

RECORD=5
TYPE=UL_MZ800

RECORD=6
TYPE=UL_MZ700

RECORD=7
TYPE=MZ700
SPEED=1:3
```

The MTI parser is streaming. It uses the existing shared SD work buffer and
does not build a record table in SRAM. The SD layer owns one sequential stream,
so AUTO MZT temporarily closes the MZT, reads only the requested MTI section,
then reopens the MZT and seeks back to the saved position.
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

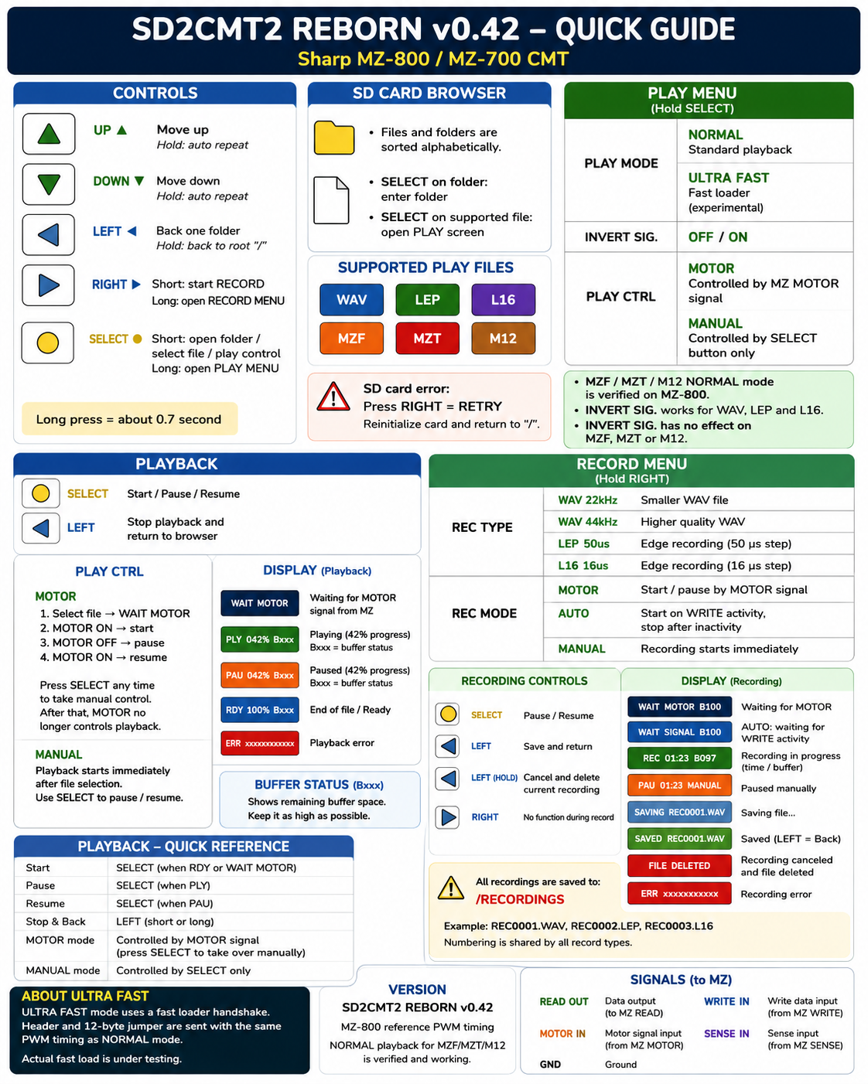
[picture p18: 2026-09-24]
guide/quickguide.png

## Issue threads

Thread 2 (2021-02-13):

Unable to compile with current Arduino IDE and library versions

ottj, 2021-02-13:
Hi
I just finished recapping my MZ80k and tried to load this awesome project onto an Arduino. I get all kinds of errors in the current Arduino IDE when I try to compile it. I then tried with downgrading the IDE and also the libraries, but the list of strange errors just changes. I am not able to update/fix the code myself. Can you provide some info which IDE and library versions to use, or even a fix in the code? Thanks a lot in advance

hlide, 2021-02-14:
Hi. Can you describe the version of the IDE you used? That project is kinda old and I am now using Visual Studio plus an Arduino plugin. Arduino IDE and libraries are not as simple as they should be because there are constantly evolving. I'll try with the most recent IDE and libraries.

hlide, 2021-02-14:
Also can you tell me what the devices you want to use with Arduino MEGA?

hlide, 2021-02-14:
You can see the version 1.8.5 and in the end the list of libraries and their version. I didn't update all the versions, that would be my next task. When finished, I will push my last commit as I can see the GitHub version is not the last.
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

hlide, 2021-02-14:
I just need to update the SdFat to the one I wanted:
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

hlide, 2021-02-14:
I committed last change. Try it with Arduino IDE 1.8.5 and the libraries as listed in pictures.

ottj, 2021-02-14:
Hi. Thanks a lot for this fast reply! I was able to compile it with the versions you specified, although I had to remove the
#include "mz-sd2cmt.std.h" line from .ino file, since this is missing from the files. So you either have to remove this line as well or commit the file.

Uploading it to the Arduino Mega 2560 worked as well.

I plan to use it with the the OLED screen, IR remote, and SD Card reader specified in the readme. At a later stage I I might also add a relay module to be able to trigger the reset of the MZ80k via remote.

hlide, 2021-02-15:
Good to hear! I forgot to remove that file so it is okay so it's ok to proceed this way. Regarding IR remote, pay attention to their keycodes, they may vary if you don't take the one I took or you will need to modify them in the code because they are not standard unhopefully.

I once tried that player on my MZ-80 K and had played twice to make sure MZ-80 K loads unlike MZ-700. It may be an issue with terminating a header block to let it start the data block. A second play will skip the header block to start the data block. By playing I mean only launching from MEGA while MZ-80 K is still trying to load (no break). I didn't try to investigate further because I had more priority elsewhere and it was for testing faulty DRAM and replacing them.

hlide, 2024-08-11:
As a fact MZ-80 K and MZ-80 A outputs MOTOR signal as 12V, not 5V which is not good for the Arduino MEGA. So we need a shift level for it, using a LM7805 for instance.

ottj, 2024-08-12:
MOTOR is a pulsed signal, and LM7805 are more for power AFAIK. Maybe a voltage divider would be better suited? https://forum.arduino.cc/t/12v-signal-to-5v-with-lm7805/324733
I'd prefer having a small board with these components so I can add it to the wiring inside the 80K.

hlide, 2024-08-12:
MOTOR is not just a pulse signal, it powers MZ 80 K and MZ 80 A dataset with 12V (yep, that why it is called MOTOR and not REMOTE). As for MZ-700 and MZ-800, it also powers their dataset but with 5V.

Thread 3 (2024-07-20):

LCD keypad doesnt work?

bales0, 2024-07-20:
Hi,
I would like to renew my SHARP MZ-800 with MZ-SD2CMT as I have no cassete player now. Found this great project. Successfuly compile and run on Mega. LCD is showing first file, but it looks like LCD keypad doesnt work. No reaction from key push.
Im not able to check the code as Im not experienced, but from first view it looks like there is no routine to read A0 voltage from LCD keypad to decode keypress.
Could you please help?
Thank you.

hlide, 2024-07-21:
Hi, glad to see my project inspires you. So, it was for an MZ-800. Can you give more details about what LCD keypad you use? A link to where you bought may be helpful.

hlide, 2024-07-21:
I checked that the keypad is enabled by default in the source:
https://github.com/SHARPENTIERS/MZ-SD2CMT/blob/3d14d01e14415129d7c6f805d5cc58e5bc8e473c/Arduino/mz-sd2cmt/mz-sd2cmt.input.h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

If you power the Mega through an USB cable plugged to your PC, you can use the serial terminal to get the value whenever you press a button on the keypad. Take note of the value for each button and give them to me. Preferably done without the MZ-800 connected to Mega as it is not a right thing to let USB power the MZ-800 or to let MZ-800 powering the PC USB.

hlide, 2024-07-21:
Also, you can join me at https://discord.com/channels/1197483745389854760/1208344566521004073.

hlide, 2024-07-21:
Mine was an old version V1 which may have a different order of voltages per key than yours and the source only works for V1. That's the reason I need more details about yours so I can add a new version working with yours.

https://github.com/SHARPENTIERS/MZ-SD2CMT/blob/3d14d01e14415129d7c6f805d5cc58e5bc8e473c/Arduino/mz-sd2cmt/mz-sd2cmt.input.keypad.h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

bales0, 2024-07-21:
Hi, than you for reply.
Im using this shield (probably China clone): D1 Robot
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

When I checked RS232 it cycle in strange error:
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

I have compiled it in Arduino 1.8.5 due to new compiler incompatibility:
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

I cant see ADC values, but measured voltage:
Right: 0V
Up: 0.650V
Down: 1.508V
Left: 2.354V
Select: 3.533V

As I understand LCD keypad shield examples, there should be voltage range for each keypress (didnt found it in your code)

BR,
Aleš

hlide, 2024-07-21:
To get the value, you simply need to use the serial monitor of Arduino IDE.

The order of buttons is the same as V1. Now, I'm not sure how to compute the voltage into BVx value because there is no warranty 1023 will be 5V (or 3.3V as I'm not sure). A long time ago I'm no longer programming in Arduino AVR...

Each pressed button has its voltage. If you press two buttons, you'll get a voltage in-between. My code was done as such as it will only accept one pressed button just for your information, so it will accept them in range [BVx-5, BVx+5] (BV0, BV1, BV2, BV3 and BV4]

What I need is to see what the Mega is reading in its ADC A0 and my code display it on USB serial. I don't understand the first image. And I cannot open both image to have them bigger as they seem to be private.

"As I understand LCD keypad shield examples, there should be voltage range for each keypress (didnt found it in your code)"
There are them in ADC 0-1023 values as expected from Mega :
https://github.com/SHARPENTIERS/MZ-SD2CMT/blob/3d14d01e14415129d7c6f805d5cc58e5bc8e473c/Arduino/mz-sd2cmt/mz-sd2cmt.input.keypad.h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

You can try to increase "delta" value as it is used to check a button is pressed if its ADC value is in the range [BVx-delta, BVx+delta]. But honestly, you can have those BVx values through the USB serial output whenever you press a button.

bales0, 2024-07-22:
Hi, I used terminal to see COM but I can see just this message:
"
The function decode(&results)) is deprecated and may not work as expected! Just use decode() - without any parameter.
The function decode(&results)) is deprecated and may not work as expected! Just use decode() - without any parameter.
The function decode(&results)) is deprecated and may not work as expected! Just use decode() - without any parameter.
The function decode(&results)) is deprecated and may not work as expected! Just use decode() - without any parameter.
The function decode(&results)) is deprecated and may not work as expected! Just use decode() - without any parameter.
The function decode(&results)) is deprecated and may not work as expected! Just use decode() - without any parameter.
The function decode(&results)) is deprecated and may not work as expected! Just use decode() - without any parameter.
"

bales0, 2024-07-22:
Hi, based on your hints, I have edited the code (replace decode(results) with decode(), so serial showed keypad ADC (I have changed acordingly ADC values as bellow). Now it shows:
"
Input device: rotary encoder.
Input device: TTP223 KeyPad.
MZ-SD2CMT
     41601 2000-10-11 10:46 Jason.mzf
TTP223: ----||0
0
83
133
1DF
2D0
"
But no reaction of LCD. Is is dependent on MOTOR and SENSE values and need to be connected to real MZ CMT port?
Selecting next mzf file doesnt work, so thats why I thought that keypad doesnt work.

BR,
Ales

bales0, 2024-07-25:
Hi, still the keypads dont work. It reads the value from keypad, but doesnt react even I have cjanged the values to the same as from serial monitor.

hlide, 2024-07-26:
Sorry, I was so busy with my work that I didn't watch my emails. So in the end, you got values when pressing keys (I see some hexa values). Did you change the values BV0-BV4 according to what you read? Because if you didn't change them, it is normal that there is no feedback to LCD.

hlide, 2024-07-26:
Regarding the LCD, I'm checking the datasheet of your LCD and they have the same pins. Oh, your picture is showing LCD is working. Note that if you select an entry, you can have info on serial port : https://github.com/SHARPENTIERS/MZ-SD2CMT/blob/3d14d01e14415129d7c6f805d5cc58e5bc8e473c/Arduino/mz-sd2cmt/mz-sd2cmt.display.serial.h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

Let me check what happens...

hlide, 2024-07-26:
In the loop, we get the input code to act accordingly:

https://github.com/SHARPENTIERS/MZ-SD2CMT/blob/3d14d01e14415129d7c6f805d5cc58e5bc8e473c/Arduino/mz-sd2cmt/mz-sd2cmt.ino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

You could add serial usb printing to see if a input code is received.

https://github.com/SHARPENTIERS/MZ-SD2CMT/blob/3d14d01e14415129d7c6f805d5cc58e5bc8e473c/Arduino/mz-sd2cmt/mz-sd2cmt.ino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

As you can see, there is a call to Display.displayCode(...) so I'm a little surprise you won't get here.

I suppose that you don't have specific issue to access SD (though Storage instance).

As for MOTOR and SENSE,  there are used when you call playWAV(); or playMZF();

hlide, 2024-07-26:
And yes, you must connect SENSE and MOTOR! I design it as a replacement of the internal tape player, not as an external tape player and yes, MOTO and SENSE are mandatory.
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
bales0, 2024-08-12:
Hi, Ive tried with real MZ800 and it is working! Awesome speed Flappy in seconds. Both normal and ultra-fast mode works.
Some of multipart games also work. I have to play more to check why just some.
Note that I have to mirror CMT connector numbering in oposite the connection diagram.
Now I have to figure out how to inbuild to MZ800 case so it would looked nice and "original".
Thank you, good job!

hlide, 2024-08-12:
> Could I have one more ask for help? Im not able to compile MZF2LEP in MinGW and there is no build included in your project. Maybe you have compiled version for Windows to share with me or add here to repository?

You need Visual Studio Development Prompt launched in _...\MZ-SD2CMT\Tools\mzf2lep\prj_ then type `build.bat`. The binary will then be in _...\MZ-SD2CMT\Tools\mzf2lep\bin_.

But I added a Release for it (compiled under Visual Studio 2022): https://github.com/SHARPENTIERS/MZ-SD2CMT/releases

bales0, 2024-08-13:
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

Hi,
thank you for help.
Anyway I will just try to compile by myself to learn something new for me.

bales0, 2024-08-13:
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

Hi,
I think that the problem is not that key is not aquired, but that it is aquired two times as LCD is redrawn with each keypress. But sometimes no change in "normal" "ultra-fast mode" parameter text.
It is clearly visible by browsing files on SD, sometimes it overjump one file with one press.
This is not a big issue for me, Im happy that we got it working on this level!

hlide, 2024-08-13:
My last commit (needs to update Arduino IDE and libraries) contains some changes :
Each button of the keypad except for UP and DOWN are now not repetitive when holding the key so you shouldn't have that issue  with the last commit and it works perfectly on my prototype. By the way, the LCD is so damn slow to refresh that I opted for an OLED which is more confortable for your information.

bales0, 2024-08-15:
Hi,
now it is possible to compile in Arduino 2.3.2, but "#include "mz-sd2cmt.std.h"" has to be deleted.
Where is the configuration file created in Windows, so it can be edited? There is no ADC values in terminal, just 0 of SELECT key (as it is 0 in always). So unknown values to be changed to for configuration.
However I have already ordered OLED and rotary encoder to get benefits from these peripherials, even 16x2 LCD looks better to 8-bit computer. :-)

hlide, 2024-08-15:
Ah sorry, this file is always in my local repository. I must really remove its #include.

As for the configuration file, you must run the firmware fist so it can create those files. They are created in the hidden .config directory in the root of your SD. The file is LCD_KEYPAD_SHIELD.input.

hlide, 2024-08-16:
Calibration for KEYPAD is now added. If the configuration is missing or invalid, serial monitor will prompt a calibration is needed and will as for pressing each buttons distinctly to hint their voltage levels.

bales0, 2024-08-16:
Hi,
nice! It works. If I need to recalibrate, I can just delete config files. One note and proposal, what about to use LCD as guidance for calibration? Its not clear what key is 1, 2, 3, why not to call them by function? LEFT, RIGHT, SELECT...? In this case user can set any ADC - keyposition configuration. As I can see from calibration procedure, code recognises which key is pressed, as I didnt went through 1,2,3,4,5 acordingly and it asigns right ADC value to right key. So maybe no calibration is needed (but maybe just coincidence as I try just once and it works) :-)
Again, I would like to thank you for such friendly and quick support!

bales0, 2024-08-16:
Oh, now I can see. It just scans ADC values for all the keys and then asigns to functions as LCDKEYPAD schematics is always the same (keypad resistor ladder) - clever. 👍

hlide, 2024-08-17:
Yes, I gambled that the voltage scale would remain the same, so all you had to do was press in any order and then sort the voltages in ascending order so that magically the right buttons were associated with the right voltage.

I've already added the possibility of displaying the calibration on all the displays but I had to comment their code out except for the serial because I had garbage on the LCD. The other problem is that I don't have many characters per line on the LCD, so I've decided to display only on the serial display for the time being.

bales0, 2024-08-19:
> Also, you can join me at https://discord.com/channels/1197483745389854760/1208344566521004073.

Hi,
Im trying to join you at discord.
Just like to discuss if it is possible to add also record function. No matter if to WAV or LEP or any other format suitable to sample MZ800 dataflow. This would totally substitute CMT as if MZ-SD2CMT is used no external casette recorder could be connected.
Maybe some simple dataloger when SAFE
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

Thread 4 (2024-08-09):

Allowing to add configuration files for various modules

hlide, 2024-08-09:
While I'm now using Arduino IDE 2.3.2, I plan to add loading/creation of specific files to configure the input/output modules. I started with LCD_KEYPAD_SHIELD input where you may need to change the voltage threshold for each button of the keypad.

The rational is to try to load a configuration file and retrieves the configuration as a simple binary file. If loading is unsuccessful or the file is not present, it is then created with default values.

If you need to tweak the configuration, you need to use an hexadecimal editor to edit it.

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

bales0, 2024-08-12:
Hi,
what about self calibration during first run and/or after holding key 1 (as this key is alway 0) during swith on?

hlide, 2024-08-12:
Regarding KEYPAD, a simple self calibration cannot be done. You need to initiate it (how?) then you need to display each button to hold to calibrate it (how?) and so on. Then you would need to sort both voltage level (BVx) and button association (ICx) so the voltage level goes from 0 to 1023.

hlide, 2024-08-12:
I may consider SELECT (enter dir or play file), LEFT (leave dir) and RIGHT (toggle ultra-fast mode) being not auto-repetitive while I kept UP and DOWN auto-repetitive to avoid unwanted actions.

bales0, 2024-08-16:
You are right. MUCH MUCH better behaviour of keypress! I have ordered RGB to HDMI converter (ready to hack acording your guidance) as RF output is so blurry.

hlide, 2024-08-17:
Now KEYPAD calibration is also displayed on LCD. The message changes as it was too long. Also the message is updated after each validated keypress.

bales0, 2024-08-19:
Hi,
something gone wrong. After update to last commit, there is no LCD init (no text just first row barrely visible rectangles).
Output from terminal is:

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

And ADC just from RIGHT key - 0.

hlide, 2024-08-19:
Ok, let me check. What's not normal is there is no saving of those files.

hlide, 2024-08-19:
Still it does work for me:
```
Input device: serial 115200.
Failed configuration file: /.config/SERIAL.debug
Invalid or no configuration file: /.config/OLED128x32.display
Created configuration file: /.config/OLED128x32.display
Output device: LED activity.
Invalid or no configuration file: /.config/LCD_KEYPAD_SHIELD.display
Created configuration file: /.config/LCD_KEYPAD_SHIELD.display
Output device: LCD16X2 screen.
Output device: serial 115200.
Invalid or no configuration file: /.config/ROTARY_ENCODER.input
Created configuration file: /.config/ROTARY_ENCODER.input
Input device: rotary encoder.
Calibrating LCD_KEYPAD...
Press keys 0/5.
```
But then it goes wrong... `Press keys 6/5.`

hlide, 2024-08-19:
Reformatted SD (works for both FAT32 or exFAT) and copy MZ-700 repository. Insert SD before powering MZ-SD²CMT. I got:

```
Input device: serial 115200.
Failed configuration file: /.config/SERIAL.debug
Invalid or no configuration file: /.config/OLED128x32.display
Created configuration file: /.config/OLED128x32.display
Output device: LED activity.
Invalid or no configuration file: /.config/LCD_KEYPAD_SHIELD.display
Created configuration file: /.config/LCD_KEYPAD_SHIELD.display
Output device: LCD16X2 screen.
Output device: serial 115200.
Created configuration file: /.config/ROTARY_ENCODER.input
Input device: rotary encoder.
Invalid or no configuration file: /.config/LCD_KEYPAD_SHIELD.input
Calibrating LCD_KEYPAD...
Press keys 0/5.
Calibrating LCD_KEYPAD...
Press keys 1/5.
280
Calibrating LCD_KEYPAD...
Press keys 2/5.
19A
Calibrating LCD_KEYPAD...
Press keys 3/5.
64
Press keys 4/5.
102
Calibrating LCD_KEYPAD...
Press keys 5/5.
0
Created configuration file: /.config/LCD_KEYPAD_SHIELD.input
Input device: LCD16X2 KeyPad.
  +00 Enabled: 1
  +01 Button Voltage [RIGHT ]: 0
  +03 Button Voltage [UP    ]: 64
  +05 Button Voltage [DOWN  ]: 102
  +07 Button Voltage [LEFT  ]: 19A
  +09 Button Voltage [SELECT]: 280
Invalid or no configuration file: /.config/TTP223_KEYPAD.input
Created configuration file: /.config/TTP223_KEYPAD.input
Input device: TTP223 KeyPad.
  +00 Enabled: 1
  +01 Input Code #0: 5
  +02 Input Code #1: 1
  +03 Input Code #2: 2
  +04 Input Code #3: 4
  +05 Input Code #4: 3
  +06 Input Code #5: 0
  +07 Input Code #6: 0
  +08 Input Code #7: 0
  +09 Active: 0
Invalid or no configuration file: /.config/IR_REMOTE.input
Created configuration file: /.config/IR_REMOTE.input
         0 2024-08-10 20:57 SHARP MZ-700/

```

And if I press RESET:

```
Input device: serial 115200.
Loaded configuration file: /.config/SERIAL.debug
Loaded configuration file: /.config/OLED128x32.display
Output device: LED activity.
Loaded configuration file: /.config/LCD_KEYPAD_SHIELD.display
Output device: LCD16X2 screen.
Output device: serial 115200.
Loaded configuration file: /.config/ROTARY_ENCODER.input
Input device: rotary encoder.
Loaded configuration file: /.config/LCD_KEYPAD_SHIELD.input
Input device: LCD16X2 KeyPad.
  +00 Enabled: 1
  +01 Button Voltage [RIGHT ]: 0
  +03 Button Voltage [UP    ]: 64
  +05 Button Voltage [DOWN  ]: 102
  +07 Button Voltage [LEFT  ]: 19A
  +09 Button Voltage [SELECT]: 280
Loaded configuration file: /.config/TTP223_KEYPAD.input
Input device: TTP223 KeyPad.
  +00 Enabled: 1
  +01 Input Code #0: 5
  +02 Input Code #1: 1
  +03 Input Code #2: 2
  +04 Input Code #3: 4
  +05 Input Code #4: 3
  +06 Input Code #5: 0
  +07 Input Code #6: 0
  +08 Input Code #7: 0
  +09 Active: 0
Loaded configuration file: /.config/IR_REMOTE.input
         0 2024-08-10 20:57 SHARP MZ-700/
```

bales0, 2024-08-19:
Hi,
Now I see the reason. Ive just deleted ".config" folder to initialize calibration. But  there was ".config" file also created. After deleting the file it works! No need to format CD card.
Nice! Thanks.

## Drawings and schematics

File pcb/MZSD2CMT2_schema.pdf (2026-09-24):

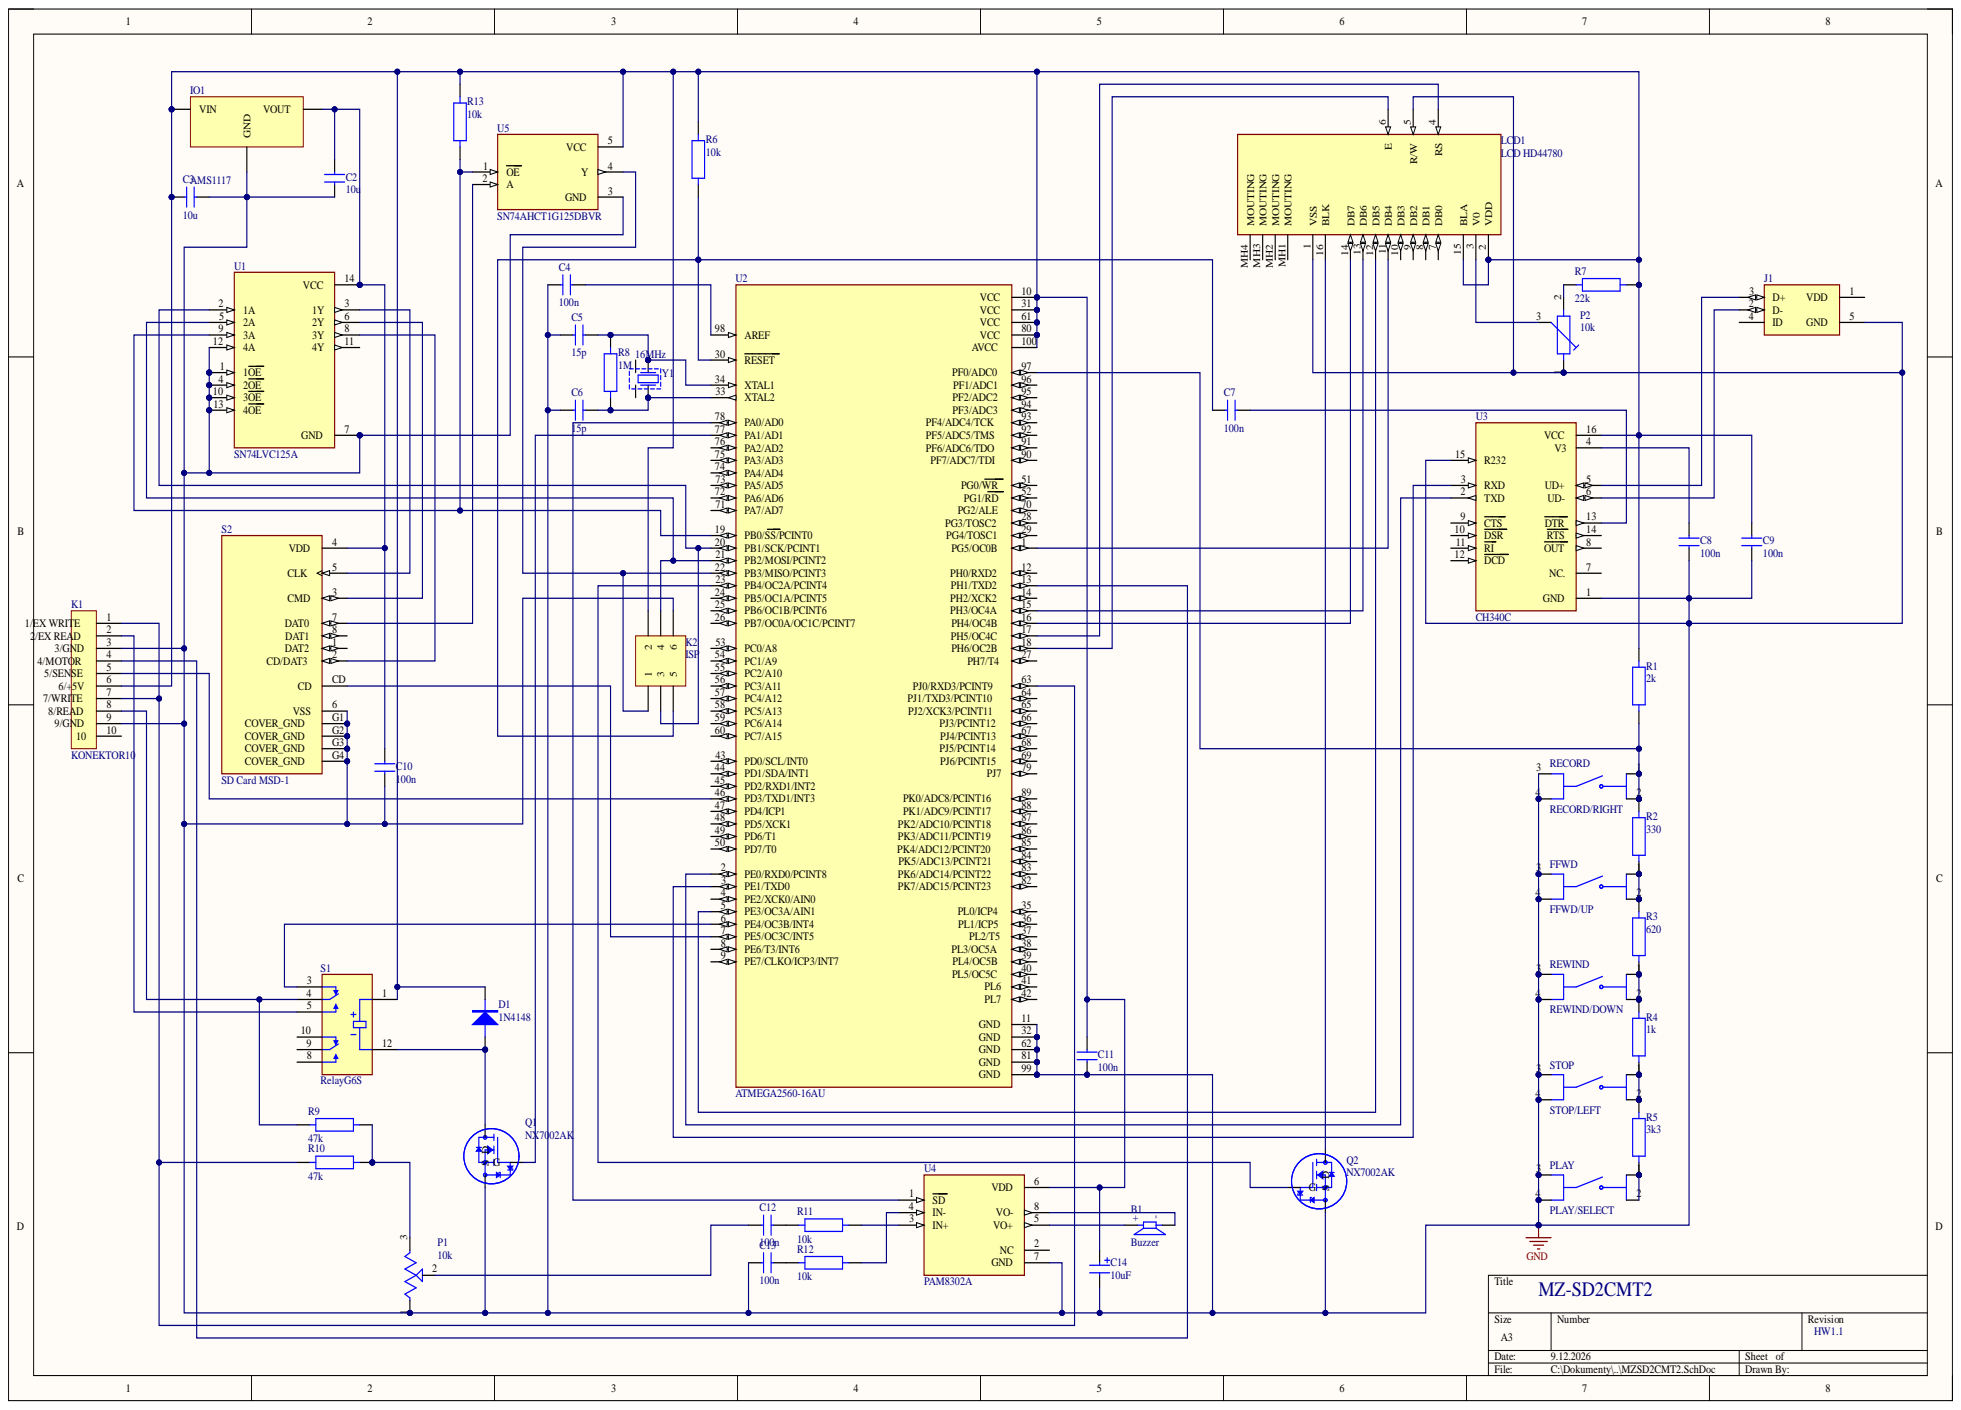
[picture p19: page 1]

MOUTING MH1 MOUTING MH2 MOUTING MH3 MOUTING MH4

PB3/MISO/PCINT3 22

PB5/OC1A/PCINT5 24

VSS | | PC3/A11 56
6 | C10 100n | | PC4/A12 57

Name | Description | Designator | Footprint | LibRef | Quantity
Buzzer | | B1 | BUZZER_6_6 | Buzzer | 1
10u | Capacitor | C2, C3 | SMD0805 | KOND | 2
100n | Capacitor | C4, C7, C8, C9, C10, C11, C12, C13 | SMD0805 | KOND | 8
15p | Capacitor | C5, C6 | SMD0805 | KOND | 2
10uF | Capacitor | C14 | SMD1812 | KONDEL | 1
1N4148 | Dioda | D1 | MINIMELF | DIODE | 1
FFWD/UP | | FFWD | Switch-6 | Switch tact | 1
AMS1117 | 3-Terminal Positive Voltage Regulator 3.3V | IO1 | SOT229 | AMS1117 | 1
USBMicroB | USB 2.0 MicroB | J1 | USBMicro SMT V3 | USBMicroB | 1
KONEKTOR10 | | K1 | JST-10-XH-A-2.54 | KONEKTOR10 | 1
ISP | Header, 3-Pin, Dual row | K2 | HDR2X3_SOCKET | Header 3X2 | 1
LCD HD44780 | LCD 2x16,2x20, HD44780 | LCD1 | LCD1602_2x16-STANDOFF11 | LCD_HD44780 | 1
10k | | P1 | TRIMR_Thumbwheel | TRIMR_Thumbwheel | 1
10k | Potentiometer | P2 | RM065 | TRIMR | 1
PLAY/SELECT | | PLAY | Switch-6 | Switch tact | 1
NX7002AK | 60 V, 190mA, single N-channel Trench MOSFET | Q1, Q2 | SOT23-3 | NX7002AK | 2
2k | Resistor | R1 | SMD0805 | REZISTOR | 1
330 | Resistor | R2 | SMD0805 | REZISTOR | 1
620 | Resistor | R3 | SMD0805 | REZISTOR | 1
1k | Resistor | R4 | SMD0805 | REZISTOR | 1
3k3 | Resistor | R5 | SMD0805 | REZISTOR | 1
10k | Resistor | R6, R11, R12, R13 | SMD0805 | REZISTOR | 4
22k | Resistor | R7 | SMD0805 | REZISTOR | 1
1M | Resistor | R8 | SMD0805 | REZISTOR | 1
47k | Resistor | R9, R10 | SMD0805 | REZISTOR | 2
RECORD/RIGHT | | RECORD | Switch-6 | Switch tact | 1
REWIND/DOWN | | REWIND | Switch-6 | Switch tact | 1
RelayG6S | | S1 | Relay-G6S-2Y | RelayG6S | 1
SD Card MSD-1 | | S2 | SD Card MSD-1 | SD Card MSD-1 | 1
STOP/LEFT | | STOP | Switch-6 | Switch tact | 1
SN74LVC125A | Quadruple Bus Buffer Gate With 3-State Outputs | U1 | SSOP-14 | SN74LVC125A | 1
ATMEGA2560-16AU | 8bit MCU | U2 | QFP50P160X160X120-100N | ATMEGA2560-16AU | 1
CH340C | USB to serial chip | U3 | SOIC-16Narrow | CH340C | 1
PAM8302A | Class D Amplifier | U4 | MSOP-8 | PAM8302A | 1
SN74AHCT1G125DBV R | | U5 | SOT23-5 | SN74AHCT1G125DBV R | 1
16MHz | Crystal Resonator | Y1 | SMD3225-4 | XTAL 4-PIN | 1

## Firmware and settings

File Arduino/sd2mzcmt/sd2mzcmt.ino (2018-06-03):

#include <Arduino.h>

//#include <DigitalIO.h>       // Sketch > Include library > Manage libraries > search: DigitalIO, by Bill Greiman
#include <SdFat.h>           // Sketch > Include library > Manage libraries > search: SdFat, by Bill Greiman
//#include <TimerOne.h>        // Sketch > Include library > Manage libraries > search: TimerOne, by Jesse Tane, Jérôme Despatis, Michael Polli, Dan Clemens, Paul Stoffregen

#define HAS_LCD16x2 1
#define HAS_ANALOG_BTNSET 1

#define LEP_UNIT      16     // LEP resolution in µs unit

#define SD0_MO        50     // SD MOSI
#define SD0_MI        51     // SD MISO
#define SD0_CK        52     // SD SCK
#define SD0_SS        53     // SS SS

#define MZT_DI        15     // MZTape WRITE (WRITE -> DI)
#define MZT_MI        16     // MZTape MOTOR ON (MOTOR ON -> MI) 
#define MZT_DO        17     // MZTape READ (DO -> READ)
#define MZT_CS        18     // MZTape /SENSE (CS -> /SENSE) 
#define MZT_LO        19     // MZTape LED OUTPUT

#define DIR_DEPTH     8
#define SFN_DEPTH     13
#define LFN_DEPTH     100

#define ENTRY_UNK     0
#define ENTRY_DIR     1
#define ENTRY_LEP     2
#define ENTRY_MZF     3

char          entry_type = ENTRY_UNK;

SdFat         sd;
SdFile        entry;
SdFile        dir[DIR_DEPTH];
char          sfn[SFN_DEPTH];
char          lfn[LFN_DEPTH+1];
bool          sd_ready = false;
int16_t       entry_index = 0;
int8_t        dir_depth = -1;
int16_t       dir_index[DIR_DEPTH] = {};
bool          canceled = false;

#if HAS_LCD16x2  

#include <LiquidCrystal.h>   // Built-in by Arduino

#define LCD_RS        8      // LCD RESET
#define LCD_EN        9      // LCD ENABLE
#define LCD_D4        4      // LCD D4
#define LCD_D5        5      // LCD D5
#define LCD_D6        6      // LCD D6
#define LCD_D7        7      // LCD D7

#define SCROLL_SPEED  250    // Text scroll delay
#define SCROLL_WAIT   3000   // Delay before scrolling starts

byte icon[8][8] =
{
  {
    B10000,
    B10000,
    B10000,
    B10000,
    B10000,
    B10000,
    B10000,
    B10000
  },
  {
    B11000,
    B11000,
    B11000,
    B11000,
    B11000,
    B11000,
    B11000,
    B11000
  },
  {
    B11100,
    B11100,
    B11100,
    B11100,
    B11100,
    B11100,
    B11100,
    B11100
  },
  {
    B11110,
    B11110,
    B11110,
    B11110,
    B11110,
    B11110,
    B11110,
    B11110
  },
  {
    B11111,
    B11111,
    B11111,
    B11111,
    B11111,
    B11111,
    B11111,
    B11111
  },
  {
    B11100,
    B10011,
    B11101,
    B10001,
    B10001,
    B10001,
    B10001,
    B11111
  },
  {
    B00111,
    B00100,
    B00100,
    B01110,
    B10101,
    B00100,
    B00100,
    B11100
  },
  {
    B10001,
    B11011,
    B10101,
    B10001,
    B11111,
    B00100,
    B01000,
    B11111
  }
};

LiquidCrystal lcd(LCD_RS, LCD_EN, LCD_D4, LCD_D5, LCD_D6, LCD_D7);
byte          scroll_pos = 0;
unsigned long scroll_time = millis() + SCROLL_WAIT;

/// This function displays a text on the first line with a horizontal scrolling if necessary.
void scrollText(char* text)
{
  if (scroll_pos < 0)
  {
    scroll_pos = 0;
  }
  char outtext[17];
  outtext[0] = entry_type ? (entry_type + 4) : '?'; 
  for (int i = 1; i < 16; ++i)
  {
    int p = i + scroll_pos - 1;
    if (p < strlen(text)) 
    {
      outtext[i] = text[p];
    }
    else
    {
      outtext[i] = '\0';
    }
  }
  outtext[16] = '\0';

  lcd.setCursor(0,0);
  lcd.print(F("                    "));
  lcd.setCursor(0,0);
  lcd.print(outtext);
}
#endif

#define BTN_R         0      // Button RIGHT
#define BTN_U         1      // Button UP
#define BTN_D         2      // Button DOWN
#define BTN_L         3      // Button LEFT
#define BTN_S         4      // Button SELECT
#define BTN_N         5      // Button None

bool          btn_pressed = false;

/// This function reads an analogic pin to determine which button is pressed.
/// @return BTN_L, BTN_R, BTN_U, BTN_D or BTN_S if one pressed (left, right, up, down or select buttons), otherwise BTN_N (none)
int readButtons()
{
#if HAS_ANALOG_BTNSET
  int adc_key = analogRead(0);

  if (adc_key < 380)
  {
    if (adc_key < 50)
      return BTN_R;
    else
      return (adc_key < 195) ? BTN_U : BTN_D;
  }
  else
  {
    if (adc_key <  555)
      return BTN_L;
    else
      return (adc_key < 790) ? BTN_S : BTN_N;
  }
#else
  return BTN_N;
#endif
}

bool checkForLEP(char *filename)
{
  return !!strstr(strlwr(filename + (strlen(filename)-4)), ".lep");
}

bool checkForMZF(char *filename)
{
  return !!strstr(strlwr(filename + (strlen(filename)-4)), ".mzf");
}

void setupDisplay()
{
#if HAS_LCD16x2  
  lcd.begin(16, 2);
  
  lcd.createChar(0, icon[0]);
  lcd.createChar(1, icon[1]);
  lcd.createChar(2, icon[2]);
  lcd.createChar(3, icon[3]);
  lcd.createChar(4, icon[4]);
  lcd.createChar(5, icon[5]);
  lcd.createChar(6, icon[6]);
  lcd.createChar(7, icon[7]);
  lcd.clear();
  
  lcd.print(F("SD2MZCMT"));
#endif
}

void displayNoSDCard()
{
#if HAS_LCD16x2  
  lcd.clear();
  lcd.print(F("SD2MZCMT: No SD card"));
#endif
}

inline void displayEntryNameMessage(bool exists)
{
#if HAS_LCD16x2  
  scroll_time = millis() + SCROLL_WAIT;
  scroll_pos = 0;

  scrollText(lfn);
#endif

  if (exists)
  {
    entry.printFileSize(&Serial);
    Serial.write(' ');
    entry.printModifyDateTime(&Serial);
    Serial.write(' ');
    entry.printName(&Serial);
    if (entry.isDir())
    {
      Serial.write('/');
    }
    Serial.println();
  }
  else
  { 
    Serial.println(F("Error: fetchEntry - no file/directory!"));
  } 
}

inline void displayScrollingMessage()
{
#if HAS_LCD16x2  
  if ((millis() >= scroll_time) && (strlen(lfn)>15))
  {
    scroll_time = millis() + SCROLL_SPEED;
    scrollText(lfn);
    ++scroll_pos;
    if (scroll_pos > strlen(lfn))
    {
      scroll_pos = 0;
      scroll_time = millis() + SCROLL_WAIT;
      scrollText(lfn);
    }
  }
#endif
}

inline void displayStartPlayingMessage()
{
#if HAS_LCD16x2  
  lcd.clear();
  scroll_pos = 0;
  scrollText(lfn);
  lcd.setCursor(0, 1);
  lcd.print(F("Playing...[    ]"));
#endif
}      

inline void displayResumePlayingMessage()
{
#if HAS_LCD16x2  
  lcd.setCursor(0, 1);
  lcd.write(F("Play"));
#endif
}      

inline void displayStopPlayingMessage(unsigned long elapsed_time) 
{
#if HAS_LCD16x2  
  auto duration = (elapsed_time + 999) / 1000; 
  lcd.setCursor(0, 1);
  if (canceled)
  {
    lcd.print(F("Canceled in "));
    lcd.print(duration);
    lcd.print(F("s.  "));
  }
  else
  {
    lcd.print(F("Done in "));
    lcd.print(duration);
    lcd.print(F("s.      "));
  }
#endif
}

inline void displayPausingMessage()
{
#if HAS_LCD16x2  
  lcd.setCursor(0, 1);
  lcd.write(F("Paus"));
#endif
}      

inline void displayProgressBar(unsigned long new_progress)
{
#if HAS_LCD16x2  
  lcd.setCursor(11 + (new_progress / 5) , 1);
  lcd.write(new_progress % 5);
#endif
}

/// This function fetches an entry in the current directory.
/// @arg int16_t new_index index of a valid entry in the directory.
void fetchEntry(int16_t new_index)
{
  bool    found = true;
  int16_t index;
      
  entry.close();

  if (new_index < 0)
  {
    new_index = 0;
  }

  do
  {
    dir[dir_depth].rewind();
    index = 0;

    while (index <= new_index)
    {
      found = entry.openNext(&dir[dir_depth], O_READ);
      if (found)
      {
        if (!entry.isHidden() && !entry.isSystem())
        {
          if (index == new_index)
          {
            break;
          }
          ++index;        
        }
        entry.close();
      }
      else
      {
        break;
      }
    }

    if (!found)
    {
      new_index = entry_index;
    }
  }
  while (!found && index > 0);

  if (found)
  {
    entry.getSFN(sfn);
    entry.getName(lfn, LFN_DEPTH);

    /**/ if (entry.isDir())
    {
      entry_type = ENTRY_DIR;
    }
    else if (checkForLEP(lfn))
    {
      entry_type = ENTRY_LEP;
    }
    else if (checkForMZF(lfn))
    {
      entry_type = ENTRY_MZF;
    }
    else
    {
      entry_type = ENTRY_UNK;
    }

    displayEntryNameMessage(true);
    
    entry_index = new_index;
  }
  else
  {
    memset(sfn, 0, SFN_DEPTH);
    memset(lfn, 0, LFN_DEPTH + 1);
    strcpy(lfn, "<no file>");
    
    displayEntryNameMessage(false);
  }
}

/// This function enters a directory.
void enterDir()
{
  if (dir_depth < DIR_DEPTH - 2)
  {
    if (dir_depth < 0)
    {
      if (dir[0].openRoot(&sd))
      {
        ++dir_depth;

        fetchEntry(0);
      }
      else
      {
        Serial.println(F("Error: enterDir - cannot open root directory!"));
      }      
    }
    else if (entry.isOpen())
    {
      ++dir_depth;
      
      dir[dir_depth] = entry;
      dir_index[dir_depth] = entry_index;

      fetchEntry(0);                  
    }
    else
    {
        Serial.println(F("Error: enterDir - no subdirectory!"));
    }
  }
  else
  {
    Serial.println(F("Error: enterDir - directory depth exceeded!"));
  }  
}

/// This function leaves a subdirectory.
void leaveDir()
{
  // leave only subdirectory
  if (dir_depth > 0)
  {
    dir[dir_depth].close();

    entry_index = dir_index[dir_depth];

    --dir_depth;

    fetchEntry(entry_index);
  }
}
  
/// This function handles the case where LEFT button is pressed.
void leftPressed()
{
  if (!btn_pressed)
  {   
    leaveDir();
    
    btn_pressed = true;
  }  
}

/// This function handles the case where RIGHT button is pressed.
void rightPressed()
{
  if (!btn_pressed)
  {
    btn_pressed = true;
  }
}

/// This function handles the case where UP button is pressed.
void upPressed()
{
  if (!btn_pressed)
  {
    fetchEntry(entry_index - 1);
    
    btn_pressed = true;
  }
}

/// This function handles the case where DOWN button is pressed.
void downPressed()
{
  if (!btn_pressed)
  {
    fetchEntry(entry_index + 1);
    
    btn_pressed = true;
  }
}

/// This function handles the case where SELECT button is pressed.
void selectPressed()
{
  if (!btn_pressed)
  {
    switch (entry_type)
    {
      case ENTRY_DIR:
        {
          enterDir();
        }
        break;
      
      case ENTRY_LEP:
      case ENTRY_MZF:
        {
          displayStartPlayingMessage();

          entry.rewind();
          
          unsigned long start_time = millis();

          if (entry_type == ENTRY_LEP)
            playLEP();
          else
            playMZF();
      
          unsigned long stop_time = millis();

          displayStopPlayingMessage(stop_time - start_time);
        }
        break;

      default:
        break;
    }
    
    btn_pressed = true;
  }
}

/// This function handles the case where a button is released.
void nonePressed()
{
  if (btn_pressed)
  {
    btn_pressed = false;
  }  
}

/// This function plays a LEP file.
void playLEP()
{
  unsigned long period;                   // half-pulse period
  unsigned long delta;                    // maximum time to spend before moving to the next half-pulse
  unsigned long last_edge;                // elapsed time since the last rising / falling edge
  bool          level = HIGH;             // level of the DATA IN signal at the output of the CMT
  bool          led = LOW;                // led indicating the frequency of reading data
  char          data, next = 0;           // LEP bytes read from the SD
  unsigned long count = 0;                // number of LEP bytes read progressively
  unsigned long led_period = 0;           // blinking period for 512 bytes LEP read
  unsigned long total = entry.fileSize(); // total number of LEP bytes to read
  unsigned long old_progress = -1;
  unsigned long new_progress = 0;

  canceled = false;

  digitalWrite(MZT_DO, level); // DATA IN signal to 1 initially
  digitalWrite(MZT_LO, led); // led light off initially

  digitalWrite(MZT_CS, LOW); // signal /SENSE at 0 to acknowledge the MZ that data is ready

  last_edge = micros(); // initial elapsed time
  delta = 125000 * LEP_UNIT; // foolish MONITOR MOTOR call which waits for 2s
            
  while (count < total) // read all the LEP bytes from the file
  {
    if (digitalRead(MZT_MI) == LOW) // MOTOR at 0, pause
    {
      digitalWrite(MZT_DO, HIGH); // DAT IN signal at 1
      digitalWrite(MZT_LO, LOW); // LED off

      displayPausingMessage();

      while (digitalRead(MZT_MI) == LOW) // as long as MOTOR does not resume
      {
        if (Serial.available() || readButtons() == BTN_S) // but if you ask to cancel
        {
          canceled = true;
          digitalWrite(MZT_CS, HIGH);  // the signal /SENSE reset to 1
          return; // leave totally
        }
      }
      
      displayResumePlayingMessage();
           
      last_edge = micros(); // reset
      delta = 125000 * LEP_UNIT; // foolish MONITOR MOTOR call which waits for 2s
    }

    if (next) // the following LEP byte is immediately available
    {
      data = next; // take it
      next = 0;
      ++count;
    }
    else
    {
      data = entry.read(); // otherwise we read it from the SD
      ++count;

      if (data < 0) // if the new LEP byte is a falling edge
      {
        if (count < total)
        {
          next = entry.read(); // read in advance the following LEP byte

          new_progress = (5 * 4 * count) / total;
          if (old_progress != new_progress)
          {
            displayProgressBar(new_progress);

            old_progress = new_progress;
          }
        }
      }
    }

    /**/ if (data == 0) period = 127;   // very long period ...
    else if (data <  0) period = -data; // in absolute value
    else                period = +data; // in absolute value

    period *= LEP_UNIT; // converts to microseconds
    
    /**/ if (data > 0) level = HIGH; // if positive LEP byte, next half-pulse at 1
    else if (data < 0) level = LOW;  // if negative LEP byte, next half-pulse at 0
    
    while (micros() - last_edge < delta); // we pause in the desired period
    
    digitalWrite(MZT_DO, level); // and we update the level output DATA IN
    
    last_edge = micros(); // update the time reference for the period
    delta = period; // and the next period

    ++led_period;
    
    if (led_period & 512) // the control led is alternated every 512 LEP bytes processed
    {
      led = !led; // toggle the signal level of the LED indicator
      digitalWrite(MZT_LO, led);
    }
  }
  digitalWrite(MZT_LO, 0); // it's over, no more led.
  digitalWrite(MZT_CS, HIGH); // reset the /SENSE signal to 1
  digitalWrite(MZT_DO, HIGH);
}

// SCK = /SENSE ---> MZ inputs  MOTOR (PC4), MOTOR = not /SENSE
// SDI = READ   ---> MZ inputs  READ  (PC5) 
// SDO = WRITE  ---> MZ outputs WRITE (PC1)

void sendMZFByte(unsigned char c)
{
  // TODO    
  for (int i = 0; i < 8; ++i)
  {   
    unsigned long us = micros();

    bool level = (c & (1 << i)) ? HIGH : LOW;
    digitalWrite(MZT_DO, level);                // set SDI to level 
    digitalWrite(MZT_CS, (i & 1) ? HIGH : LOW); // toggle SCK to acknowledge MZ
    digitalWrite(MZT_LO, level);
    
    while(micros() < us + 16);
  }
}

/// This function plays a MZF file.
void playMZF()
{
  unsigned long   total = entry.fileSize();
  unsigned char   data;
  unsigned long   size = 0;
  unsigned short  load = 0;
  unsigned short  exec = 0;
  unsigned long   count;
  unsigned long   old_progress = -1;
  unsigned long   new_progress = 0;
  bool            led = LOW;

  canceled = false;

  data = entry.read(); /* 0x10F0: file attribute */

  if (data == 1 && total >= 128) // On ne lit que les fichiers de type EXECUTABLE BINAIRE
  {
    for (int i = 0x10F1; i < 0x1102; ++i) entry.read(); // skip file name

    size  = (/* 0x1102 */entry.read() & 255) << 0;   
    size += (/* 0x1103 */entry.read() & 255) << 8;

    load  = (/* 0x1104 */entry.read() & 255) << 0;
    load += (/* 0x1105 */entry.read() & 255) << 8;
    
    exec  = (/* 0x1106 */entry.read() & 255) << 0;
    exec += (/* 0x1107 */entry.read() & 255) << 8;
    
    for (int i = 0x1108; i < 0x1170; ++i) entry.read(); // skip the header

    sendMZFByte((size >> 0) & 255);
    sendMZFByte((size >> 8) & 255);
    sendMZFByte((exec >> 0) & 255);
    sendMZFByte((exec >> 8) & 255);
    sendMZFByte((load >> 0) & 255);
    sendMZFByte((load >> 8) & 255);

    count = 0;

    if (total - 128 == size)
    {
      while (count != size)
      {        
        data = entry.read();
        ++count;
  
        new_progress = (5 * 4 * count) / size;
        if (old_progress != new_progress)
        {
          displayProgressBar(new_progress);

          old_progress = new_progress;
        }
  
        sendMZFByte(data);    
      }
    }
    else
    {
      canceled = true;
    }

    digitalWrite(MZT_LO, LOW);
    digitalWrite(MZT_CS, HIGH);
  }
  else
  {
    canceled = true;
  }
}

void setup()
{
  Serial.begin(9600);

  setupDisplay();
  
  pinMode(SD0_SS, OUTPUT);
  
  pinMode(MZT_DO, OUTPUT);
  pinMode(MZT_DI, INPUT_PULLUP);
  pinMode(MZT_CS, OUTPUT);
  pinMode(MZT_MI, INPUT_PULLUP);
  pinMode(MZT_LO, OUTPUT);

  digitalWrite(MZT_DO, HIGH); // signal DATA IN à 1 initialement
  digitalWrite(MZT_CS, HIGH); // signal /SENSE à 1 (lecteur non disponible)
  digitalWrite(MZT_LO, LOW);  // témoin led éteint

  sd_ready = sd.begin(SD0_SS, SPI_FULL_SPEED);
   
  if (!sd_ready) // accès au SD en full-speed
  {
    sd.initErrorHalt();

    displayNoSDCard();
  }
}

void loop()
{
  Serial.println("SD2MZCMT");

  enterDir();
  
  while (!Serial.available())
  {
    switch (readButtons())
    {
    case BTN_R:
      rightPressed();
      break;
    case BTN_L:
      leftPressed();
      break;
    case BTN_U:
      upPressed();
      break;
    case BTN_D:
      downPressed();
      break;
    case BTN_S:
      selectPressed();
      break;
    default:
      nonePressed();
      break;
    }

    displayScrollingMessage();   
  }

  // Do something with Serial?
}

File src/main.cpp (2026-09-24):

#include <Arduino.h>
#include <stdio.h>
#include <string.h>

#include "drivers/lcd.h"
#include "drivers/keypad.h"
#include "drivers/calibration_store.h"
#include "drivers/sdcard.h"
#include "drivers/flash_text.h"
#include "drivers/backlight.h"
#include "drivers/external_switch.h"
#include "drivers/monitor_mute.h"
#include "drivers/ram_monitor.h"

#include "play/play_controller.h"
#include "ui/browser.h"
#include "ui/menu.h"
#include "ui/record_menu.h"
#include "ui/play_screen.h"
#include "ui/record_screen.h"
#include "ui/settings_menu.h"
#include "record/record_engine.h"

#define CALIBRATION_PRESS_DELTA 30U
#define CALIBRATION_RELEASE_DELTA 20U
#define ACTIVE_KEYPAD_POLL_MS 5U
#define ACTIVE_LCD_UPDATE_MS 250U

typedef enum
{
    APP_SCREEN_BROWSER = 0,
    APP_SCREEN_PLAY,
    APP_SCREEN_RECORD,
    APP_SCREEN_PLAY_MENU,
    APP_SCREEN_RECORD_MENU,
    APP_SCREEN_SETTINGS_MENU
} app_screen_t;


static uint16_t last_lcd_update_ms = 0U;
static uint16_t last_active_keypad_poll_ms = 0U;
static bool sd_ok = false;
static app_screen_t current_screen = APP_SCREEN_BROWSER;

/* Fixed root-level destination copied from flash only when RECORD starts. */
static const char recordings_directory_P[] PROGMEM = "/RECORDINGS";
static char recordings_directory[12];

static void lcd_print_line(uint8_t row, const char *text)
{
    char line[17];
    uint8_t length = 0U;
    if (text != NULL)
    {
        while ((length < 16U) && (text[length] != '\0'))
        {
            line[length] = text[length];
            ++length;
        }
    }
    while (length < 16U) line[length++] = ' ';
    line[16] = '\0';
    lcd_set_cursor(0U, row);
    lcd_print(line);
}

static void lcd_print_line_P(uint8_t row, PGM_P text)
{
    char line[17];
    flash_text_copy(line, sizeof(line), text);
    lcd_print_line(row, line);
}

static uint16_t adc_average(uint8_t samples)
{
    uint32_t sum = 0UL;
    for (uint8_t i = 0U; i < samples; ++i)
    {
        sum += keypad_read_raw();
        delay(5);
    }
    return (uint16_t)(sum / samples);
}

static uint16_t calibration_adc_diff(uint16_t left, uint16_t right)
{
    return (left > right) ? (uint16_t)(left - right) :
                            (uint16_t)(right - left);
}

static void wait_for_release(uint16_t none_adc)
{
    lcd_print_line_P(0U, PSTR("RELEASE ALL"));
    lcd_print_line_P(1U, PSTR("WAIT..."));
    while (calibration_adc_diff(keypad_read_raw(), none_adc) >
           CALIBRATION_RELEASE_DELTA) delay(20);
    delay(200);
}

static uint16_t calibrate_none(void)
{
    lcd_clear();
    lcd_print_line_P(0U, PSTR("CAL NONE"));
    lcd_print_line_P(1U, PSTR("RELEASE ALL"));
    /* NONE is the reference level. Do not assume it is above 900: different
       keypad shields may use a different ladder direction or range. */
    delay(1000);
    return adc_average(32);
}

static uint16_t calibrate_button(PGM_P name, uint16_t none_adc)
{
    char line0[17];
    char line1[17];
    char name_ram[12];
    flash_text_copy(name_ram, sizeof(name_ram), name);
    flash_text_snprintf(line0, sizeof(line0), PSTR("PRESS %-10s"), name_ram);
    lcd_clear();
    lcd_print_line(0, line0);
    lcd_print_line_P(1U, PSTR("WAIT INPUT"));
    while (calibration_adc_diff(keypad_read_raw(), none_adc) <
           CALIBRATION_PRESS_DELTA) delay(20);
    delay(250);
    uint16_t value = adc_average(32);
    flash_text_snprintf(line1, sizeof(line1), PSTR("ADC:%4u"), value);
    lcd_print_line(0U, name_ram);
    lcd_print_line(1U, line1);
    delay(700);
    wait_for_release(none_adc);
    return value;
}

static bool run_keypad_calibration(keypad_calibration_t *calibration)
{
    if (calibration == NULL) return false;
    lcd_clear();
    lcd_print_line_P(0U, PSTR("KEYPAD"));
    lcd_print_line_P(1U, PSTR("CALIBRATION"));
    delay(1200);
    calibration->none = calibrate_none();
    calibration->up = calibrate_button(PSTR("REWIND"), calibration->none);
    calibration->down = calibrate_button(PSTR("FFWD"), calibration->none);
    calibration->left = calibrate_button(PSTR("STOP"), calibration->none);
    calibration->right = calibrate_button(PSTR("RECORD"), calibration->none);
    calibration->select = calibrate_button(PSTR("PLAY"), calibration->none);
    if (!keypad_calibration_is_valid(calibration))
    {
        lcd_print_line_P(0U, PSTR("CAL INVALID"));
        lcd_print_line_P(1U, PSTR("USING DEFAULT"));
        delay(1800);
        return false;
    }
    if (!calibration_store_save_keypad(calibration))
    {
        /* Keep the measured mapping for this session, but make a real EEPROM
           failure visible instead of silently replacing it with defaults. */
        lcd_print_line_P(0U, PSTR("EEPROM ERROR"));
        lcd_print_line_P(1U, PSTR("NOT SAVED"));
        delay(1800);
        return true;
    }
    lcd_print_line_P(0U, PSTR("CALIBRATION"));
    lcd_print_line_P(1U, PSTR("SAVED"));
    delay(700);
    return true;
}

static void app_enter_browser(void)
{
    browser_restore_saved_position();
    current_screen = APP_SCREEN_BROWSER;
    lcd_clear();
}

static void app_enter_play(const char *filename, const char *directory_path)
{
    browser_save_position();
    browser_clear_status();
    play_controller_start_session(filename, directory_path,
                                  menu_get_invert_signal(),
                                  menu_get_loader_mode(),
                                  menu_get_play_control_mode());
    current_screen = APP_SCREEN_PLAY;
    lcd_clear();
}

static void app_enter_record(void)
{
    record_engine_config_t config;
    browser_save_position();
    config.format = record_menu_get_format();
    config.wav_sample_rate = record_menu_get_wav_sample_rate();
    config.control_mode = record_menu_get_control_mode();
    config.autoname = record_menu_get_autoname();
    (void)record_engine_start(recordings_directory, &config);
    current_screen = APP_SCREEN_RECORD;
    lcd_clear();
}

static void app_handle_browser_event(button_event_t event)
{
    browser_action_t action = browser_handle_event(event);
    switch (action)
    {
        case BROWSER_ACTION_FILE_SELECTED:
            app_enter_play(browser_get_selected_name(), browser_get_current_path());
            break;
        case BROWSER_ACTION_RECORD_REQUESTED:
            app_enter_record();
            break;
        case BROWSER_ACTION_PLAY_MENU_REQUESTED:
            browser_save_position();
            current_screen = APP_SCREEN_PLAY_MENU;
            lcd_clear();
            break;
        case BROWSER_ACTION_RECORD_MENU_REQUESTED:
            browser_save_position();
            current_screen = APP_SCREEN_RECORD_MENU;
            lcd_clear();
            break;
        case BROWSER_ACTION_SETTINGS_REQUESTED:
            browser_save_position();
            settings_menu_init();
            current_screen = APP_SCREEN_SETTINGS_MENU;
            lcd_clear();
            break;
        default:
            break;
    }
}
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

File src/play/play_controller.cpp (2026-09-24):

#include <Arduino.h>
#include <string.h>

#include "play_controller.h"
#include "../record/record_path_buffer.h"
#include "../formats/mzi_sidecar.h"
#include "play_engine.h"
#include "../drivers/mzio.h"
#include "../drivers/sdcard.h"
#include "../drivers/wav_playback_driver.h"

#if (PLAY_CONTROLLER_PATH_MAX != CMT_SESSION_PATH_BUFFER_MAX)
#error "PLAY and RECORD shared path sizes must match"
#endif
#define session_full_path cmt_session_path_buffer
static file_format_t session_format = FILE_FORMAT_UNKNOWN;
static bool session_invert_signal = false;
static loader_mode_t session_loader_mode = LOADER_MODE_NORMAL_1_1;
static play_control_mode_t session_control_mode = PLAY_CONTROL_MOTOR;
static play_controller_state_t session_state = PLAY_CONTROLLER_STATE_READY;

/* MOTOR mode is armed only once when a file is selected. EOF must not loop. */
static bool waiting_for_motor = false;
static bool motor_control_released = false;

/* Front-panel PLAY may explicitly resume a MOTOR pause while MOTOR is still
   LOW.  Keep that override only until the MZ raises MOTOR again; the next LOW
   then belongs to ordinary MOTOR control. */
static bool manual_motor_override = false;

/* Manual pause has priority over an automatic MOTOR release. */
static bool paused_by_motor = false;
static bool paused_by_user = false;

/* MZT opens in a lightweight record selector.  No record list is retained in
   SRAM; every UP/DOWN re-prepares one requested 1-based record. */
static bool mzt_selection_pending = false;
static bool session_has_info_sidecar = false;
static bool session_media_removed = false;

static const char *play_controller_session_filename(void)
{
    const char *last_slash = strrchr(session_full_path, '/');
    return (last_slash == NULL) ? session_full_path : last_slash + 1U;
}

static bool play_controller_build_full_path(const char *directory_path,
                                            const char *filename)
{
    size_t directory_length;
    size_t filename_length;
    bool add_separator;
    size_t output_offset;

    session_full_path[0] = '\0';
    if ((directory_path == NULL) || (filename == NULL) ||
        (directory_path[0] == '\0') || (filename[0] == '\0'))
    {
        return false;
    }

    directory_length = strlen(directory_path);
    filename_length = strlen(filename);
    add_separator = directory_path[directory_length - 1U] != '/';

    if ((directory_length + (add_separator ? 1U : 0U) + filename_length) >=
        sizeof(session_full_path))
    {
        return false;
    }

    memcpy(session_full_path, directory_path, directory_length);
    output_offset = directory_length;
    if (add_separator)
    {
        session_full_path[output_offset++] = '/';
    }
    memcpy(session_full_path + output_offset, filename, filename_length + 1U);
    return true;
}

static bool play_controller_can_start(void)
{
    return (session_format != FILE_FORMAT_UNKNOWN) && !session_media_removed;
}

static void play_controller_refresh_info_sidecar(void)
{
    session_has_info_sidecar = false;
    if (session_format == FILE_FORMAT_MZF)
    {
        session_has_info_sidecar =
            mzi_sidecar_exists_for_mzf(session_full_path);
    }
    else if (session_format == FILE_FORMAT_MZT)
    {
        session_has_info_sidecar =
            mzi_sidecar_exists_for_mzt(session_full_path);
    }
}

static void play_controller_clear_pause_reason(void)
{
    paused_by_motor = false;
    paused_by_user = false;
}


static bool play_controller_prepare_engine(uint16_t mzt_record_index)
{
    play_engine_config_t config;

    config.full_path = session_full_path;
    config.format = session_format;
    config.invert_signal = session_invert_signal;
    config.loader_mode = session_loader_mode;
    config.control_mode = session_control_mode;
    config.mzt_record_index = mzt_record_index;

    if (!play_engine_prepare(&config))
    {
        session_state = PLAY_CONTROLLER_STATE_ERROR;
        return false;
    }

    return true;
}

static bool play_controller_start_engine(void)
{
    if (!play_engine_start())
    {
        session_state = PLAY_CONTROLLER_STATE_ERROR;
        return false;
    }
    session_state = PLAY_CONTROLLER_STATE_PLAYING;
    manual_motor_override = false;
    play_controller_clear_pause_reason();
    motor_control_released = false;
    if ((session_control_mode == PLAY_CONTROL_MOTOR) &&
        play_engine_is_ul_loader_active())
    {
        motor_control_released = true;
    }
    return true;
}

static bool play_controller_pause_engine(void)
{
    if (!play_engine_pause())
    {
        session_state = PLAY_CONTROLLER_STATE_ERROR;
        return false;
    }
    if (play_engine_get_state() == PLAY_ENGINE_STATE_READY)
    {
        session_state = PLAY_CONTROLLER_STATE_READY;
        waiting_for_motor = false;
        manual_motor_override = false;
        play_controller_clear_pause_reason();
        return true;
    }

    session_state = PLAY_CONTROLLER_STATE_PAUSED;
    return true;
}

static bool play_controller_resume_engine(void)
{
    if (!play_engine_resume())
    {
        session_state = PLAY_CONTROLLER_STATE_ERROR;
        return false;
    }
    session_state = PLAY_CONTROLLER_STATE_PLAYING;
    play_controller_clear_pause_reason();
    motor_control_released = false;
    if ((session_control_mode == PLAY_CONTROL_MOTOR) &&
        play_engine_is_ul_loader_active())
    {
        motor_control_released = true;
    }
    return true;
}

static void play_controller_pause_for_motor(void)
{
    manual_motor_override = false;
    if (play_controller_pause_engine())
    {
        paused_by_user = false;
        paused_by_motor = (session_state == PLAY_CONTROLLER_STATE_PAUSED);
    }
}

static void play_controller_pause_for_user(void)
{
    if (play_controller_pause_engine())
    {
        paused_by_motor = false;
        paused_by_user = (session_state == PLAY_CONTROLLER_STATE_PAUSED);
    }
}

/* Front-panel PLAY is an explicit user override.  If the pause came from
   MOTOR LOW, resume immediately even while MOTOR remains LOW.  The override
   lasts only until the first observed MOTOR HIGH; after that, the next LOW
   again pauses through the normal MOTOR path. */
static void play_controller_resume_from_user(void)
{
    bool motor_override_requested = false;

    paused_by_user = false;

    if ((session_control_mode == PLAY_CONTROL_MOTOR) &&
        !motor_control_released && !mz_motor_get())
    {
        manual_motor_override = true;
        motor_override_requested = true;
    }

    paused_by_motor = false;
    if (!play_controller_resume_engine() && motor_override_requested)
    {
        manual_motor_override = false;
    }
}
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

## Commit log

2018-06-03 When calling MONITOR MOTOR function, there is an active wait loop for almost 2s until the GAP is read. So Arduino must reproduce that 2s pause until it can emit GAP.
2018-06-17 Add legacy PWM playing from a MZF file.
    There are two versions: Procedural vs. Machine State. WIP.
2019-03-30 Led indicator as display addition
2019-03-31 Rotary encoder addition - work in progress
2019-04-14 New input device addition: KY-040, a rotary encoder
2024-08-12 Switching to Arduino IDE 2.3.2 and handling configuration files:
    - Sketch > Include library > Manage libraries > search: SSD1306Ascii 1.3.5, by Bill Greiman
    - Sketch > Include library > Manage libraries > search: SdFat 2.2.3, by Bill Greiman
    - Sketch > Include library > Manage libraries > search: irremote 4.4.0
2024-08-16 Calibration for LCD_KEYPAD_SHIELD.
    If configuration file is empty or invalid, you can press the keys distinctly one by one to register their voltage levels.
2024-08-17 Calibration is now showed on all displays.
2024-09-14 Port to platformio.
    Arduino/mz-sd2cmt is now optional.
    Execute fill_arduino.bat if you need it for ArduinoIDE, using a Junction instead of a copy.
2026-09-13 first RC upload
    firs public version to test
    [Button.stl, Cover.stl, Distancer.stl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]
2026-09-14 timing rebuild from z80 dissassembly, UL leader shorted to 2000/1000, not tested on HW
    [mzf_loader.cpp, mzf_playback.cpp]
2026-09-16 autoname for normal 4x now working for wav, repaired unwanted manual init sd card issue
    [mzf_playback.cpp, sdcard.cpp]
2026-09-20 calibration FFD and REW swap repaired
    [keypad.cpp, main.cpp]
